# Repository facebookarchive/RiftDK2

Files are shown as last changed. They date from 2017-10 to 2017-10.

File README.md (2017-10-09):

Oculus Rift Development Kit 2
=======

Firmware, electrical CAD, mechanical CAD, artwork, and documentation for DK2.

License
-------
The CAD, artwork, and documentation are released under Creative Commons
Attribution 4.0 International.

The Oculus firmware is licensed under the BSD-style license at
https://github.com/fbsamples/RiftDK2/blob/master/Headset/Firmware/LICENSE

We also provide for the Oculus firmware an additional grant of patent rights at
https://github.com/fbsamples/RiftDK2/blob/master/Headset/Firmware/PATENTS

The firmware incorporates or references materials of third parties that are
subject to other licenses.  Please see the individual headers on each file to
determine which license applies.  For ease of reference, headers that include
the link http://www.st.com/software_license_agreement_liberty_v2 refer to the
license reproduced in en.ultimate-liberty-v2.txt.

Documentation
-------------

High-level specifications for the DK2 headset, sensor, and firmware.

Cable
-----

The cable is surprisingly one of the most complex parts of the product, and
is likely actually more advanced than the entirety of DK1.  This directory
contains schematics and high level specifications for the cable, but this
is a custom assembly that likely isn't achievable to recreate from source.

Sensor
------

The positional tracking sensor release contains electrical and mechanical
CAD.  The sensor also utilizes microcontrollers which require firmware
which was not redistributable.

Headset
-------

The headset directory contains the mainboard firmware as well as electrical
and mechanical CAD for the headset.  It also contains artwork for the
packaging.

Contributors
------------

The incredible (and incredibly small) team who made DK2:

 * Headset Electrical: Lyle Bainbridge, Ryan Brown, Matt DeVoe
 * Sensor Electrical: John Robertson
 * Headset Firmware: Nirav Patel
 * Mechanical: Julian Hammerstein, Matt Thomas, Kam Chin
 * Optical: Youngshik Yoon
 * Automation: Simon Hallam, Anusha Balan, Brant Lewis
 * Operations: Rita Chen, Licia Angino, Jack McCauley, David Dykes
 * Factory: Allen Qin, Victor Zhang, Ivan Chow, Mark Zhang
 * Misc: Palmer Luckey, Chris Dycus, Jonathan Shine
 * Artwork: Matt Ford, Jon Malkemus

RiftDK2 repository preparation: Matt Appleby, Kelly Lowenberg, John Tsai

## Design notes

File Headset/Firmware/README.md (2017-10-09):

DK2 Firmware
============

Licenses
--------

The Oculus firmware is licensed under the BSD-style license at
https://github.com/fbsamples/RiftDK2/blob/master/Headset/Firmware/LICENSE

We also provide for the Oculus firmware an additional grant of patent rights at
https://github.com/fbsamples/RiftDK2/blob/master/Headset/Firmware/PATENTS

The firmware incorporates or references materials of third parties that are
subject to other licenses.  Please see the individual headers on each file to
determine which license applies.  For ease of reference, headers that include
the link http://www.st.com/software_license_agreement_liberty_v2 refer to the
license reproduced in en.ultimate-liberty-v2.txt.

External Libraries
------------------

The ARM CMSIS library is not included, but can be downloaded from:
https://github.com/ARM-software/CMSIS/tree/master/CMSIS

The firmware was originally developed with CMSIS 3.01

This should be placed in lib/CMSIS

Building DK2 Firmware
---------------------

Building DK2 firmware currently requires IAR EWARM.  You can get a 30-day trial
here: http://supp.iar.com/Download/SW/?item=EWARM-EVAL

Programming DK2 Firmware to a Board
-----------------------------------

### Updating an already programmed board

You can update a DK2 over USB using the Oculus Configuration Utility:
https://product-guides.oculus.com/en-us/documentation/dk2/latest/tasks/ug-tray-start-firmware/

In this case, you should use the most recent DK2.bin available for your board.

* Rev 3 (GDC units): prj/REV3/Exe/DK2.bin
* Rev 3.3 (Pilot run and production units): prj/REV3_3/Exe/DK2.bin

### Programming to a blank board

For a blank board, you'll need to program it over the SWD header using an
ST-Link programmer.

In this case, you'll need the ST-Link utility and DK2Bootloader.bin

* Rev 3 (GDC units): bootloader/prj/REV3/Exe/DK2Bootloader.bin
* Rev 3.3 (Pilot run and production units):
    bootloader/prj/REV3_3/Exe/DK2Bootloader.bin

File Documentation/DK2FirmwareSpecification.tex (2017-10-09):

\documentclass[letterpaper]{article}
\usepackage{bytefield}
\usepackage{mathtools}
\usepackage{ifxetex}
\ifxetex
  \usepackage{fontspec}
  \setmainfont[ExternalLocation=../Common/, 
  					  Ligatures =TeX,
					  BoldFont = Cabin-Bold.ttf,
					  ItalicFont = Cabin-Italic.ttf,
					  BoldItalicFont = Cabin-BoldItalic.ttf ]
					  {Cabin-Regular.ttf}
\fi
\usepackage{graphicx}
\usepackage{color}
\usepackage[table]{xcolor}
\usepackage{hyperref}
\usepackage{parskip}
\usepackage{tikz}
\usetikzlibrary{automata,positioning,fit}
\usepackage{fancyhdr}
\pagestyle{fancy}
\definecolor{lightgray}{gray}{0.8}
\renewcommand{\arraystretch}{1.25}

\begin{document}

\title{\huge DK2 Firmware Specification}
\author{Nirav Patel}
\date{Revision 0.10\\
28 April 2014}

\begin{figure}

\end{figure}

\maketitle
\thispagestyle{empty}

\lfoot{DK2 Firmware Specification}
\cfoot{}
\rfoot{\thepage}

\newpage

\tableofcontents

\newpage

\section{Revision History}

\begin{center}
    \begin{tabular}{ | l | l | p{8cm} |}
    \hline
    \cellcolor{lightgray} Revision & \cellcolor{lightgray} Date & \cellcolor{lightgray} Description \\ \hline
    0.1 & 28-11-2013 & Preliminary specification. \\ \hline
    0.2 & 08-12-2013 & Add camera feature report. \\ \hline
    0.3 & 11-12-2013 & Add display feature report. \\ \hline
    0.4 & 23-12-2013 & Add magnetometer and position calibration and LED pattern reports. \\ \hline
    0.5 & 26-12-2013 & Add keep alive, manufacturing, and uuid reports. \\ \hline
    0.6 & 30-01-2014 & Add temperature report, modify position report. \\ \hline
    0.7 & 13-02-2014 & Add gyro offset report. \\ \hline
    0.8 & 18-02-2014 & Add normals to position calibration, rename camera to tracking. \\ \hline
    0.9 & 24-02-2014 & Add lens distortion report. \\ \hline
    0.10 & 28-04-2014 & Add basic EDID information. \\ \hline
    \end{tabular}
\end{center}

\newpage

\section{Introduction}

The Rift DK2 is interfaced using USB HID with a 1000 Hz polling rate.  The device is configured using Feature Report Gets and Sets and reports back gyroscope, accelerometer, magnetometer, and synchronization timestamps through an IN Report.  For more information about HID, see the Device Class Definition for Human Interface Devices\footnote{\url{http://www.usb.org/developers/devclass_docs/HID1_11.pdf}}

\begin{itemize}
  \item {\bfseries Vendor ID:} {\em 0x2833}
  \item {\bfseries Product ID:} {\em 0x0021}
  \item {\bfseries Vendor String:} {\em Oculus VR, Inc.}
  \item {\bfseries Product String:} {\em Rift DK2}
  \item {\bfseries Serial String:} {\em Globally unique 20 byte Base32 string generated per device}
\end{itemize}

\newpage

\section{HID In Report}

The 64 byte IN report on Endpoint 1 contains the sensor data.  All data is in little-endian format.  The gyro and accelerometer report data at a rate of 1000 Hz, which is also the rate at which the sample time is incremented.\\

While the target rate for the host polling the device for the IN report is 1000 Hz, system or bus load can cause the polling to happen on longer intervals, dropping the reporting rate below 1000 Hz.  For this reason, the report contains fields for up to 2 samples of gyro and accelerometer data as well as a field stating the number of samples being reported.  The behavior is as follows:\\

\begin{itemize}
  \item If the number of recorded samples is $<=$ 2, the corresponding number
   of samples is returned with NumSamples set accordingly.
  \item If the number of recorded samples is $>$ 2, the first (NumSamples -1) samples
   are averaged into Samples[0], while Samples[1] contains the most recent recorded sample.
   NumSamples is set to the total original number of
   recorded samples and Timestamp is set to that of the most recent sample; this allows for PC software to compensate the integration.
  \item DK2 does not accumulate more then 254 samples; beyond that the
   NumSamples is reset to 2 and only the most recent 2 samples are reported, with the Timestamp field properly incremented to indicate the loss of samples.
\end{itemize}

\begin{bytefield}[leftcurly=.,bitwidth=1.1em]{32}
         \bitheader{0-31} \\
	\begin{leftwordgroup}{0}
           \bitbox{8}{ReportID = 11} & \bitbox{16}{LastCommandID} & \bitbox{8}{NumSamples}
	\end{leftwordgroup} \\
	\begin{leftwordgroup}{4}
           \bitbox{16}{SampleCount} & \bitbox{16}{Temperature}
	\end{leftwordgroup} \\
	\begin{leftwordgroup}{8}
           \bitbox{32}{SampleTimestamp}
	\end{leftwordgroup} \\
	\begin{leftwordgroup}{12}
           \wordbox[lrt]{1}{Samples[0]}
	\end{leftwordgroup} \\
         \skippedwords \\
         \wordbox[lrb]{1}{} \\
	\begin{leftwordgroup}{28}
           \wordbox[lrt]{1}{Samples[1]}
	\end{leftwordgroup} \\
         \skippedwords \\
         \wordbox[lrb]{1}{} \\
	\begin{leftwordgroup}{44}
            \bitbox{16}{MagX} & \bitbox{16}{MagY}
	\end{leftwordgroup} \\
	\begin{leftwordgroup}{48}
           \bitbox{16}{MagZ} & \bitbox{16}{FrameCount}
	\end{leftwordgroup} \\
	\begin{leftwordgroup}{52}
	   \bitbox{32}{FrameTimestamp}
	\end{leftwordgroup} \\
	\begin{leftwordgroup}{56}
	   \bitbox{8}{FrameID} & \bitbox{8}{TrackingPattern} & \bitbox{16}{TrackingCount}
	\end{leftwordgroup} \\
	\begin{leftwordgroup}{60}
	   \bitbox{32}{TrackingTimestamp}
	\end{leftwordgroup} \\
\end{bytefield}

\begin{itemize}
  \item {\bfseries ReportID} (8 bits): The USB Report ID for this report is 11.
  \item {\bfseries LastCommandID} (16 bits): Contains the CommandID from the last Feature Report set on DK2.
  \item {\bfseries NumSamples} (8 bits): The number of samples the report represents as described above.
  \item {\bfseries SampleCount} (16 bits): A running counter of samples, for the number of the first sample in the report.  As the internal sampling rate targets 1000 Hz, this unit is close to milliseconds.
  \item {\bfseries Temperature} (16 bits): The most recent internal sensor temperature recorded by the DK2.  The value is in two's complement format, in units of centidegrees Celsius. 
  \item {\bfseries SampleTimestamp} (32 bits): A microsecond timestamp of the last sensor sample in the packet.  This is recorded on the same clock as the FrameTimestamp and TrackingTimestamp.
  \item {\bfseries Samples} (128 bits): Each sample contains X, Y, and Z data for the gyro and accelerometer.  Specified below.
  \item {\bfseries MagX, MagY, MagZ} (16 bits each): The most recent data available from the magnetometer.  The three axes are sampled simultaneously at up to 100 Hz.  Note that consecutive reports may contain the same magnetometer data.  The data is two's complement in units of $10\textsuperscript{-4}$ gauss.
  \item {\bfseries FrameCount} (16 bit): A running counter of frames sent to the display, incremented at each vsync.
  \item {\bfseries FrameTimestamp} (32 bit): A microsecond timestamp of the last vsync sent to the display.  This is recorded on the same clock as the SampleTimestamp and TrackingTimestamp.
  \item {\bfseries FrameID} (8 bit): The green value of the top left pixel in the last frame sent to the display.  This is used to identify specific frames to measure the end to end latency from motion to photon.
  \item {\bfseries TrackingPattern} (8 bit): The index of the last tracking LED pattern exposed to the camera.
  \item {\bfseries TrackingCount} (16 bit): A running counter of camera frames triggered by the headset.
  \item {\bfseries TrackingTimestamp} (32 bit): A microsecond timestamp of the last camera exposure.  This is recorded on the same clock as the SampleTimestamp and FrameTimestamp.
\end{itemize}

\subsection{Accelerometer and Gyro Sample}

The X, Y, and Z axes of the gyro and accelerometer are sampled simultaneously.  The accelerometer fields are two's complement format and 21 bits each. They are in units of $\frac{m}{s\textsuperscript{2}}\cdot 10\textsuperscript{-4}$.  The gyroscope fields are two's complement and 21 bits each. They are in units of $\frac{\theta}{s}\cdot 10\textsuperscript{-4}$ in radians.\\

\begin{bytefield}[leftcurly=.,bitwidth=1.1em]{32}
         \bitheader{0-31} \\
	\begin{leftwordgroup}{0}
           \bitbox{21}{AccelX} & \bitbox{11}{AccelY[0:10]} 
	\end{leftwordgroup} \\
	\begin{leftwordgroup}{4}
           \bitbox{10}{AccelY[11:20]} & \bitbox{21}{AccelZ} & \bitbox{1}{\color{lightgray}\rule{\width}{\height}}
	\end{leftwordgroup} \\
	\begin{leftwordgroup}{8}
           \bitbox{21}{GyroX} & \bitbox{11}{GyroY[0:10]} 
	\end{leftwordgroup} \\
	\begin{leftwordgroup}{12}
           \bitbox{10}{GyroY[11:20]} & \bitbox{21}{GyroZ} & \bitbox{1}{\color{lightgray}\rule{\width}{\height}}
	\end{leftwordgroup} \\
\end{bytefield}

\newpage

\section{Feature Reports}

\subsection{Tracking}

The 13 byte Tracking report has a ReportID of 12.  It configures the infrared tracking LEDs and camera synchronization. \\

\begin{bytefield}[leftcurly=.,bitwidth=1.1em]{32}
         \bitheader{0-31} \\
	\begin{leftwordgroup}{0}
           \bitbox{8}{ReportID = 12} & \bitbox{16}{CommandID} & \bitbox{8}{Pattern}
	\end{leftwordgroup} \\
	\begin{leftwordgroup}{4}
           \bitbox{1}{a} & \bitbox{1}{b} & \bitbox{1}{c} & \bitbox{1}{d} & \bitbox{1}{e} & \bitbox{1}{f} & \bitbox{10}{} & \bitbox{16}{ExposureLength}
          \end{leftwordgroup} \\
	\begin{leftwordgroup}{8}
           \bitbox{16}{FrameInterval} & \bitbox{16}{VsyncOffset}
	\end{leftwordgroup} \\
	\begin{leftwordgroup}{12}
           \bitbox{8}{DutyCycle} & \bitbox[]{24}{}
	\end{leftwordgroup} \\
\end{bytefield}

\begin{itemize}
  \item {\bfseries ReportID} (8 bits): The USB Report ID for this report is 12.
  \item {\bfseries CommandID} (16 bits): A sequence number that is then repeated in the LastCommandID field of the HID IN Report.
  \item {\bfseries Pattern} (8 bits): The index of the pattern of high and low intensities that is currently set on the tracking LEDs.  Pattern 255 is reserved for all LEDs set high.  Patterns auto-increment after each exposure if the Autoincrement bit is set in the bitmask.  The Pattern starts at 0 on power on.
  \item {\bfseries (a) Enable} (1 bit): This bit enables the tracking LED exposure and updating.  This currently defaults to on, but will default off in a later firmware revision.
  \item {\bfseries (b) Autoincrement} (1 bit): With Autoincrement set, the Pattern is incremented after every exposure.  This defaults to on.
  \item {\bfseries (c) UseCarrier} (1 bit): The tracking LEDs modulate at 85 kHz to allow for wireless synchronization when UseCarrier is enabled.  This defaults to on.
  \item {\bfseries (d) SyncInput} (1 bit): With SyncInput enabled, LED exposure is triggered from a rising edge on GPIO1.  With SyncInput disabled, the LED exposure is triggered from an internal timer at FrameInterval.  This defaults to off.
  \item {\bfseries (e) VsyncLock} (1 bit)(Disabled): If enabled, LED exposure is triggered on panel Vsync rather than from an internal timer or external trigger.  This defaults to off.
  \item {\bfseries (f) CustomPattern} (1 bit): If enabled, the LED sequence will be the one loaded in using the CustomPattern report.  This defaults to off.
  \item {\bfseries ExposureLength} (16 bits): This is the length of time the tracking LEDs are enabled for in microseconds.  The sync output also follows this length.  This number cannot be larger than the FrameInterval.  The minimum length is approximately 10 microseconds.
  \item {\bfseries FrameInterval} (16 bits): When SyncInput and VsyncLock are false, the tracking LEDs are exposed on the interval set in FrameInterval in microseconds.
  \item {\bfseries VsyncOffset} (16 bits)(Disabled): When VsyncLock is enabled, the exposure can be performed a fixed offset of VsyncOffset microseconds after the panel vsync.
  \item {\bfseries DutyCycle} (8 bits): When UseCarrier is true, the duty cycle of the 85 kHz modulation can be increased or decreased.  The default value is 128, which results in a $50\%$ duty cycle. 
\end{itemize}

\newpage

\subsection{Display}

The 16 byte Display report has a ReportID of 13.  It configures the display panel. \\

\begin{bytefield}[leftcurly=.,bitwidth=1.1em]{32}
         \bitheader{0-31} \\
	\begin{leftwordgroup}{0}
           \bitbox{8}{ReportID = 13} & \bitbox{16}{CommandID} & \bitbox{8}{Brightness}
	\end{leftwordgroup} \\
	\begin{leftwordgroup}{4}
           \bitbox{4}{a} & \bitbox{2}{b} & \bitbox{1}{c} & \bitbox{1}{d} & \bitbox{1}{e} & \bitbox{1}{f} & \bitbox{1}{g} & \bitbox{1}{h} &\bitbox{20}{}
          \end{leftwordgroup} \\
	\begin{leftwordgroup}{8}
           \bitbox{16}{Persistence} & \bitbox{16}{LightingOffset}
	\end{leftwordgroup} \\
	\begin{leftwordgroup}{12}
           \bitbox{16}{PixelSettle} & \bitbox{16}{TotalRows}
	\end{leftwordgroup} \\
\end{bytefield}

\begin{itemize}
  \item {\bfseries ReportID} (8 bits): The USB Report ID for this report is 13.
  \item {\bfseries CommandID} (16 bits): A sequence number that is then repeated in the LastCommandID field of the HID IN Report.
  \item {\bfseries Brightness} (8 bits): A relative brightness setting that is independent of pixel persistence.  The field only takes effect if HighBrightness is disabled. 
  \item {\bfseries (a) ShutterType} (4 bits)(Read only): A read-only enum of the method in which the display is scanned and exposed.
  \item {\bfseries (b) CurrentLimit} (2 bit): An enum of the current limiting mode in use.
  \item {\bfseries (c) UseRolling} (1 bit): Switches between global shutter and rolling shutter update modes.  This defaults to true.
  \item {\bfseries (d) ReverseRolling} (1 bit): Switches the polarity on the rolling shutter mode.  Reverse had the lighting of rows happen before the black period.  This defaults to true.
  \item {\bfseries (e) HighBrightness} (1 bit)(Disabled): This enables a mode in which maximum brightness is used, at the possible expense of panel lifetime.  This defaults to false.
  \item {\bfseries (f) SelfRefresh} (1 bit): This sets the panel to self refresh from the contents of its frame buffer.  This defaults to false.
  \item {\bfseries (g) ReadPixel} (1 bit): This enables reading the top left pixel each frame.  This currently defaults to false, but will default to true in a later firmware revision.
  \item {\bfseries (h) DirectPentile} (1 bit): This enables direct mapping of input data to panel sub pixel geometry, rather than using in-panel interpolation.
  \item {\bfseries Persistence} (16 bits): This is the length of time in rows that the display is lit each frame.  This defaults to the full size of the display, meaning full persistence.
  \item {\bfseries LightingOffset} (16 bits)(Disabled): This is the offset in rows from vsync that the panel is lit when using global shutter mode.  In rolling shutter, this has no effect.
  \item {\bfseries PixelSettle} (16 bits)(Read only): This is the read-only time in microseconds that we estimate the pixel takes to settle to the value it is set to after it is lit.
  \item {\bfseries TotalRows} (16 bits)(Read only): This is the read-only number of rows including active area and blanking used with Persistence and LightingOffset.
\end{itemize}

\newpage

\subsection{MagCalibration}

The 52 byte MagCalibration report has a ReportID of 14.  It contains the 3 by 4 matrix of parameters used to fit the magnetometer to a sphere.  The table is stored on the headset, but the firmware does not apply it to outgoing magnetometer data. \\

\begin{bytefield}[leftcurly=.,bitwidth=1.1em]{32}
         \bitheader{0-31} \\
	\begin{leftwordgroup}{0}
           \bitbox{8}{ReportID = 14} & \bitbox{16}{CommandID} & \bitbox{8}{Version}
	\end{leftwordgroup} \\
	\begin{leftwordgroup}{4}
           \bitbox{32}{Calibration[0][0]}
         \end{leftwordgroup} \\
	\begin{leftwordgroup}{8}
           \bitbox{32}{Calibration[0][1]}
         \end{leftwordgroup} \\
	\begin{leftwordgroup}{12}
           \bitbox{32}{Calibration[0][2]}
         \end{leftwordgroup} \\
	\begin{leftwordgroup}{16}
           \bitbox{32}{Calibration[0][3]}
         \end{leftwordgroup} \\
	\begin{leftwordgroup}{20}
           \bitbox{32}{Calibration[1][0]}
         \end{leftwordgroup} \\
	\begin{leftwordgroup}{24}
           \bitbox{32}{Calibration[1][1]}
         \end{leftwordgroup} \\
	\begin{leftwordgroup}{28}
           \bitbox{32}{Calibration[1][2]}
         \end{leftwordgroup} \\
	\begin{leftwordgroup}{32}
           \bitbox{32}{Calibration[1][3]}
         \end{leftwordgroup} \\
	\begin{leftwordgroup}{36}
           \bitbox{32}{Calibration[2][0]}
         \end{leftwordgroup} \\
	\begin{leftwordgroup}{40}
           \bitbox{32}{Calibration[2][1]}
         \end{leftwordgroup} \\
	\begin{leftwordgroup}{44}
           \bitbox{32}{Calibration[2][2]}
         \end{leftwordgroup} \\
	\begin{leftwordgroup}{48}
           \bitbox{32}{Calibration[2][3]}
         \end{leftwordgroup} \\
\end{bytefield}

\begin{itemize}
  \item {\bfseries ReportID} (8 bits): The USB Report ID for this report is 14.
  \item {\bfseries CommandID} (16 bits): A sequence number that is then repeated in the LastCommandID field of the HID IN Report.
  \item {\bfseries Version} (8 bits): The version of the calibration procedure used to generate the stored table. 
  \item {\bfseries Calibration} (48 bytes): This is the 3 by 4 matrix used to fit magnetometer data to a sphere.  Each field is a 32 bit signed integer.  The specific value is dependent on the calibration procedure, indicated by Version.
\end{itemize}

\newpage

\subsection{PositionCalibration}

The 30 byte PositionCalibration report has a ReportID of 15.  It allows reading and storage of calibrated positions of each tracking LED as well as the inertial tracker.\\

\begin{bytefield}[leftcurly=.,bitwidth=1.1em]{32}
         \bitheader{0-31} \\
	\begin{leftwordgroup}{0}
           \bitbox{8}{ReportID = 15} & \bitbox{16}{CommandID} & \bitbox{8}{Version}
	\end{leftwordgroup} \\
	\begin{leftwordgroup}{4}
           \bitbox{32}{Position[0]}
          \end{leftwordgroup} \\
	\begin{leftwordgroup}{8}
           \bitbox{32}{Position[1]}
          \end{leftwordgroup} \\
	\begin{leftwordgroup}{12}
           \bitbox{32}{Position[2]}
          \end{leftwordgroup} \\
	\begin{leftwordgroup}{16}
           \bitbox{16}{Normal[0]} && \bitbox{16}{Normal[1]}
          \end{leftwordgroup} \\
	\begin{leftwordgroup}{20}
           \bitbox{16}{Normal[2]} && \bitbox{16}{Rotation}
          \end{leftwordgroup} \\
	\begin{leftwordgroup}{24}
           \bitbox{16}{PositionIndex} & \bitbox{16}{NumPositions}
          \end{leftwordgroup} \\
	\begin{leftwordgroup}{28}
           \bitbox{16}{PositionType} & \bitbox[]{16}{}
          \end{leftwordgroup} \\
\end{bytefield}

\begin{itemize}
  \item {\bfseries ReportID} (8 bits): The USB Report ID for this report is 15.
  \item {\bfseries CommandID} (16 bits): A sequence number that is then repeated in the LastCommandID field of the HID IN Report.
  \item {\bfseries Version} (8 bits): The version of the calibration procedure used to generate the stored positions.  Note that setting the report with a Version value of 1 returns the Position values for the PositionIndex to the stored defaults.
    \begin{description}
      \item[0 -] None
      \item[1 -] Hard-coded default positions
      \item[2 -] Factory calibrated
      \item[3 -] User calibrated
    \end{description}
  \item {\bfseries Position} (12 bytes): The X, Y, and Z axis position of the LED or inertial tracker.  This is a signed integer in units of micrometers.  The position is relative to the center of the emitter plane of the display at nominal focus.
  \item {\bfseries Normal} (6 bytes): The X, Y, and Z axis normal of the LED or inertial tracker.  This is a signed integer in units of micrometers.  The Normal is relative to the Position.
  \item {\bfseries Rotation} (16 bits): The rotation around the normal.  This is in units of $ 10\textsuperscript{-4}$ radians.
  \item {\bfseries PositionIndex} (16 bits): This is the current position being read or written to.  This autoincrements on reads, and gets set to the written value on writes.
  \item {\bfseries NumPositions} (16 bits)(Read only): This is the read-only number of items with positions stored.
  \item {\bfseries PositionType} (16 bits)(Read only): The type of the item which has its position reported in the current report.  These are defined as:
    \begin{description}
      \item[0 -] Tracking LED
      \item[1 -] Inertial sensor
    \end{description}
    When setting this report, the PositionType should match that read for the PositionIndex.
\end{itemize}

\newpage

\subsection{CustomPattern}

The 12 byte CustomPattern report has a ReportID of 16.  It allows reading of the default LED patterns as well as reading and setting of custom patterns.  Repeated reads of the report iterate through each LED, starting at 0 and wrapping at the final LED.  When the CustomPattern bit of the Tracking report is not set, reads on this report act upon the default LED pattern stored in the headset, and writes have no effect.  With the CustomPattern bit set, this report acts on a custom pattern array that erases when the headset is reset.\\

\begin{bytefield}[leftcurly=.,bitwidth=1.1em]{32}
         \bitheader{0-31} \\
	\begin{leftwordgroup}{0}
           \bitbox{8}{ReportID = 16} & \bitbox{16}{CommandID} & \bitbox{8}{SequenceLength}
	\end{leftwordgroup} \\
	\begin{leftwordgroup}{4}
           \bitbox{32}{Sequence}
          \end{leftwordgroup} \\
	\begin{leftwordgroup}{8}
           \bitbox{16}{LEDIndex} & \bitbox{16}{NumLEDs}
	\end{leftwordgroup} \\
\end{bytefield}

\begin{itemize}
  \item {\bfseries ReportID} (8 bits): The USB Report ID for this report is 16.
  \item {\bfseries CommandID} (16 bits): A sequence number that is then repeated in the LastCommandID field of the HID IN Report.
  \item {\bfseries SequenceLength} (8 bits): The length of the sequence of bits that each LED goes through.  Each state of the sequence is represented by two bits, allowing a maximum of 4 levels per sequence.  For DK2, only states 0, 1, and 3 are meaningful, for off, low, and high respectively.
  \item {\bfseries Sequence} (32 bits): The sequence that the specific LED goes through.  The first $SequenceLength*2$ bits are used.  The sequence is in order of LSB to MSB.
  \item {\bfseries LEDIndex} (16 bits): This is the current LED being read or written to.  This autoincrements on reads, and gets set to the written value on writes.
  \item {\bfseries NumLEDs} (16 bits)(Read only): This is the read-only number of tracking LEDs which are actually present on the device.
\end{itemize}

\newpage

\subsection{KeepAliveMux}

The 6 byte KeepAliveMux report has a ReportID of 17.  It is used to specify both which IN Report is sent and the interval of sending.  The interval takes effect only if the UseCommandKeepAlive or UseMotionKeepAlive bits are set in the Config report.\\

\begin{bytefield}[leftcurly=.,bitwidth=1.1em]{32}
         \bitheader{0-31} \\
	\begin{leftwordgroup}{0}
           \bitbox{8}{ReportID = 17} & \bitbox{16}{CommandID} & \bitbox{8}{INReport}
	\end{leftwordgroup} \\
	\begin{leftwordgroup}{4}
           \bitbox{16}{Interval} & \bitbox[]{16}{}
          \end{leftwordgroup} \\
\end{bytefield}

\begin{itemize}
  \item {\bfseries ReportID} (8 bits): The USB Report ID for this report is 17.
  \item {\bfseries CommandID} (16 bits): A sequence number that is then repeated in the LastCommandID field of the HID IN Report.
  \item {\bfseries INReport} (8 bits): The specified number is the INReport which will be repeatedly sent until the interval is passed.  For example, specifying 1 sends the DK1 IN Report, while specifying 11 sends the DK2 IN Report.  The default value for DK2 is 11.
  \item {\bfseries Interval} (16 bits): The interval in milliseconds used as the threshold for UseCommandKeepAlive and UseMotionKeepAlive.  The default interval is 10000.
\end{itemize}

\newpage

\subsection{Manufacturing}

The 16 byte Manufacturing report has a ReportID of 18.  It is used to record and display the results of each stage of the production of the DK2 product that has USB access.\\

\begin{bytefield}[leftcurly=.,bitwidth=1.1em]{32}
         \bitheader{0-31} \\
	\begin{leftwordgroup}{0}
           \bitbox{8}{ReportID = 18} & \bitbox{16}{CommandID} & \bitbox{8}{NumStages}
	\end{leftwordgroup} \\
	\begin{leftwordgroup}{4}
           \bitbox{8}{Stage} & \bitbox{8}{StageVersion} & \bitbox{16}{StageLocation}
         \end{leftwordgroup} \\
	\begin{leftwordgroup}{8}
           \bitbox{32}{StageTime}
         \end{leftwordgroup} \\
	\begin{leftwordgroup}{12}
           \bitbox{32}{Result}
         \end{leftwordgroup} \\
\end{bytefield}

\begin{itemize}
  \item {\bfseries ReportID} (8 bits): The USB Report ID for this report is 18.
  \item {\bfseries CommandID} (16 bits): A sequence number that is then repeated in the LastCommandID field of the HID IN Report.
  \item {\bfseries NumStages} (8 bits)(Read only): The number of stages of production being recorded on the product.
  \item {\bfseries Stage} (8 bits): The specific stage number being recorded or read from.  This autoincrements on reads, and gets set to the written value on writes.
  \item {\bfseries StageVersion} (8 bits): The version of the specific manufacturing test.
  \item {\bfseries StageLocation} (16 bits): A bit mask representing the manufacturer, line, and machine this test was performed on.  See the DK2 Testware document for details on this.
  \item {\bfseries StageTime} (32 bits): The UNIX time at which the stage was performed.
  \item {\bfseries Result} (32 bits): The result of the stage.  See the DK2 Testware document for the details of what this means for each stage.
\end{itemize}

\newpage

\subsection{UUID}

The 23 byte UUID report has a ReportID of 19.  It is used internally for manufacturing purposes, when the USB serial number is set to a default number.  Outside of manufacturing, the number is identical to the USB serial number.  Setting this report switches the USB serial number to the value read from this report.  The value being set is ignored.\\

\begin{bytefield}[leftcurly=.,bitwidth=1.1em]{32}
         \bitheader{0-31} \\
	\begin{leftwordgroup}{0}
           \bitbox{8}{ReportID = 19} & \bitbox{16}{CommandID} & \bitbox{8}{UUID[0]} 
	\end{leftwordgroup} \\
	\begin{leftwordgroup}{4}
           \bitbox{32}{UUID[1:5]}
	\end{leftwordgroup} \\
	\begin{leftwordgroup}{8}
           \bitbox{32}{UUID[5:9]}
	\end{leftwordgroup} \\
	\begin{leftwordgroup}{12}
           \bitbox{32}{UUID[9:13]}
	\end{leftwordgroup} \\
	\begin{leftwordgroup}{16}
           \bitbox{32}{UUID[13:17]}
	\end{leftwordgroup} \\
	\begin{leftwordgroup}{20}
           \bitbox{24}{UUID[17:20]} & \bitbox[]{8}{}
	\end{leftwordgroup} \\
\end{bytefield}

\begin{itemize}
  \item {\bfseries ReportID} (8 bits): The USB Report ID for this report is 19.
  \item {\bfseries CommandID} (16 bits): A sequence number that is then repeated in the LastCommandID field of the HID IN Report.
  \item {\bfseries UUID} (20 bytes)(Read only):  The unique ID of the device.
\end{itemize}

\newpage

\subsection{Temperature}

The 24 byte Temperature report has a ReportID of 20.  It is used to store gyroscope zero rate offsets across different temperatures.  The offsets are stored for certain target temperature Bins, with multiple Samples of offset data stored per temperature.  When reading the report, subsequent reads of the report go sequentially through each Sample in NumSamples for each Bin in NumBins.  The headset only stores the offsets, and does not create or modify them directly.\\

\begin{bytefield}[leftcurly=.,bitwidth=1.1em]{32}
         \bitheader{0-31} \\
	\begin{leftwordgroup}{0}
           \bitbox{8}{ReportID = 20} & \bitbox{16}{CommandID} & \bitbox{8}{Version} 
	\end{leftwordgroup} \\
	\begin{leftwordgroup}{4}
           \bitbox{8}{NumBins} & \bitbox{8}{Bin} & \bitbox{8}{NumSamples} & \bitbox{8}{Sample}
	\end{leftwordgroup} \\
	\begin{leftwordgroup}{8}
           \bitbox{16}{TargetTemperature} & \bitbox{16}{ActualTemperature}
	\end{leftwordgroup} \\
	\begin{leftwordgroup}{12}
           \bitbox{32}{Time}
	\end{leftwordgroup} \\
	\begin{leftwordgroup}{16}
           \wordbox[lrt]{1}{Offset}
	\end{leftwordgroup} \\
         \skippedwords \\
         \wordbox[lrb]{1}{} \\
\end{bytefield}

\begin{itemize}
  \item {\bfseries ReportID} (8 bits): The USB Report ID for this report is 20.
  \item {\bfseries CommandID} (16 bits): A sequence number that is then repeated in the LastCommandID field of the HID IN Report.
  \item {\bfseries Version} (8 bits):  The version of temperature calibration being performed.
  \item {\bfseries NumBins} (8 bits)(Read only): The number of temperature bins being stored.
  \item {\bfseries Bin} (8 bits): The current index of temperature bin the samples are for.  This autoincrements on reading all of the Samples in the Bin, and gets set to the written value on writes.
  \item {\bfseries NumSamples} (8 bits)(Read only): The number of samples being stored per temperature bin.
  \item {\bfseries Sample} (8 bits): The current index of temperature offset sample.  This autoincrements on reads, and gets set to the written value on writes.
  \item {\bfseries TargetTemperature} (16 bits)(Read only): The target temperature in centidegrees Celsius for the current Level.
  \item {\bfseries ActualTemperature} (16 bits): The actual temperature in centidegrees Celsius of the current Bin.
  \item {\bfseries Time} (32 bits): The UNIX time that the current Sample was generated at.
  \item {\bfseries Offset} (64 bits): The packed sample format with 21 bits per axis used for the IN Report, with each value in units of $\frac{\theta}{s}\cdot 10\textsuperscript{-4}$ radians, representing the estimated zero-rate gyroscope offset for the ActualTemperature.
\end{itemize}

\newpage

\subsection{GyroOffset}

The 18 byte Temperature report has a ReportID of 21.  It is used to fetch the headset's most recent estimate of gyro zero-rate offset error.  Note that if the headset fails to complete zero rate offset calculation, there will not be valid data in this report, indicated by a Version field value of 0.\\

\begin{bytefield}[leftcurly=.,bitwidth=1.1em]{32}
         \bitheader{0-31} \\
	\begin{leftwordgroup}{0}
           \bitbox{8}{ReportID = 21} & \bitbox{16}{CommandID} & \bitbox{8}{Version} 
	\end{leftwordgroup} \\
	\begin{leftwordgroup}{4}
           \wordbox[lrt]{1}{Offset}
	\end{leftwordgroup} \\
         \skippedwords \\
         \wordbox[lrb]{1}{} \\
	\begin{leftwordgroup}{12}
           \bitbox{32}{Timestamp}
        	\end{leftwordgroup} \\
	\begin{leftwordgroup}{16}
           \bitbox{16}{Temperature} & \bitbox[]{16}{}
	\end{leftwordgroup} \\
\end{bytefield}

\begin{itemize}
  \item {\bfseries ReportID} (8 bits): The USB Report ID for this report is 21.
  \item {\bfseries CommandID} (16 bits): A sequence number that is then repeated in the LastCommandID field of the HID IN Report.
  \item {\bfseries Version} (8 bits):  The version of offset calculation being performed.
    \begin{description}
      \item[0 -] No offset calculated
      \item[1 -] Running average terminated by motion
      \item[2 -] Running average terminated by timeout
    \end{description}
  \item {\bfseries Offset} (64 bits): The packed sample format with 21 bits per axis used for the IN Report, with each value in units of $\frac{\theta}{s}\cdot 10\textsuperscript{-4}$ radians, representing the estimated zero-rate gyroscope offset.
  \item {\bfseries Timestamp} (32 bits): A microsecond timestamp of the calculation of the offset.  This is recorded on the same clock as the SampleTimestamp in the IN Report.
  \item {\bfseries Temperature} (16 bits): The temperature the offset was calculated at.
\end{itemize}

\newpage

\subsection{LensDistortion}

The 64 byte LensDistortion report has a ReportID of 22.  It defines parameters used by LibOVR to correct lens distortion.  Multiple reports of the same or different versions or eye reliefs may be available, defined by NumDistortions.  The report defaults to factory data, but each DistortionIndex may be overwritten with new data.\\

\begin{bytefield}[leftcurly=.,bitwidth=1.1em]{32}
         \bitheader{0-31} \\
	\begin{leftwordgroup}{0}
           \bitbox{8}{ReportID = 22} & \bitbox{16}{CommandID} & \bitbox{8}{NumDistortions} 
	\end{leftwordgroup} \\
	\begin{leftwordgroup}{4}
           \bitbox{8}{DistortionIndex} & \bitbox{8}{Bitmask} & \bitbox{16}{LensType}
	\end{leftwordgroup} \\
	\begin{leftwordgroup}{8}
           \bitbox{16}{Version} & \bitbox{16}{EyeRelief}
	\end{leftwordgroup} \\
	\begin{leftwordgroup}{12}
           \bitbox{16}{KCoefficients[0]} & \bitbox{16}{KCoefficients[1]}
	\end{leftwordgroup} \\
	\begin{leftwordgroup}{16}
           \bitbox{16}{KCoefficients[2]} & \bitbox{16}{KCoefficients[3]}
	\end{leftwordgroup} \\
	\begin{leftwordgroup}{20}
           \bitbox{16}{KCoefficients[4]} & \bitbox{16}{KCoefficients[5]}
	\end{leftwordgroup} \\
	\begin{leftwordgroup}{24}
           \bitbox{16}{KCoefficients[6]} & \bitbox{16}{KCoefficients[7]}
	\end{leftwordgroup} \\
	\begin{leftwordgroup}{28}
           \bitbox{16}{KCoefficients[8]} & \bitbox{16}{KCoefficients[9]}
	\end{leftwordgroup} \\
	\begin{leftwordgroup}{32}
           \bitbox{16}{KCoefficients[10]} & \bitbox{16}{MaxR}
	\end{leftwordgroup} \\
	\begin{leftwordgroup}{36}
           \bitbox{16}{MetersPerTanAngleAtCenter} & \bitbox{16}{ChromaticAberration[0]}
	\end{leftwordgroup} \\
	\begin{leftwordgroup}{40}
           \bitbox{16}{ChromaticAberration[1]} & \bitbox{16}{ChromaticAberration[2]}
	\end{leftwordgroup} \\
	\begin{leftwordgroup}{44}
           \bitbox{16}{ChromaticAberration[3]} & \bitbox[lrt]{16}{}
	\end{leftwordgroup} \\
	\begin{leftwordgroup}{48}
           \wordbox[lr]{1}{Unused}
	\end{leftwordgroup} \\
         \skippedwords \\
         \wordbox[lrb]{1}{} \\
\end{bytefield}

\begin{itemize}
  \item {\bfseries ReportID} (8 bits): The USB Report ID for this report is 22.
  \item {\bfseries CommandID} (16 bits): A sequence number that is then repeated in the LastCommandID field of the HID IN Report.
  \item {\bfseries NumDistortions} (8 bits)(Read only):  The number of lens distortions being stored.
  \item {\bfseries DistortionsIndex} (8 bits):  The current index of lens distortion.  This autoincrements on reads and gets set to the written value on writes.
  \item {\bfseries Bitmask} (8 bits):  A current unused bitmask.
  \item {\bfseries LensType} (16 bits):  The type of the lens used in the headset.  These are enumerated in LibOVR.
  \item {\bfseries Version} (16 bits):  The version of lens distortion specified in the report.  The fields after this one are dependent on the specified Version.
    \begin{description}
      \item[0 -] No lens distortion stored. The remaining report is empty.
      \item[1 -] LCSV\_CatmullRom10Version1. The fields are defined as below.
    \end{description}
  \item {\bfseries EyeRelief} (16 bits):  The eye relief the distortion is designed for.  This is in units of micrometers measured from the front surface of the lens.
  \item {\bfseries KCoefficients} (11 fields of 16 bits): Catmull-Rom distortion coefficients.  The units are defined in LibOVR.
  \item {\bfseries MaxR} (16 bits): Defined in LibOVR.
  \item {\bfseries MetersPerTanAngleAtCenter} (16 bits): Defined in LibOVR.
  \item {\bfseries ChromaticAberration} (4 fields of 16 bits): Defined in LibOVR.
  \item {\bfseries Unused} (14 bytes): Unused by LCSV\_CatmullRom10Version1.
\end{itemize}

\newpage

\section{EDID}

The EDID 1.3 is read over the HDMI interface by the video host.

\begin{itemize}
  \item {\bfseries Manufacturer ID:} {\em OVR}
  \item {\bfseries Product ID:} {\em 0x0003}
  \item {\bfseries Product String:} {\em Rift DK2}
  \item {\bfseries Serial String:} {\em First 13 bytes of the device UUID}
\end{itemize}

\end{document}

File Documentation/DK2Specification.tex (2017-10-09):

\documentclass[letterpaper]{article}
\usepackage[utf8]{inputenc}

\usepackage{ifxetex}
\ifxetex
  \usepackage{fontspec}
  \setmainfont[ExternalLocation=../Common/, 
              		  Ligatures =TeX,
					  BoldFont = Cabin-Bold.ttf,
					  ItalicFont = Cabin-Italic.ttf,
					  BoldItalicFont = Cabin-BoldItalic.ttf ]
					  {Cabin-Regular.ttf}
\fi

\title{\huge DK2 Specification}
\author{Nirav Patel\\ Nate Mitchell\\ Kam Chin\\ Ryan Brown}
\date{Revision 0.4\\
30 May 2014}

\usepackage{parskip}
\usepackage{graphicx}
\usepackage{hyperref}
\usepackage{color}
\usepackage{fancybox}
\usepackage[usenames,dvipsnames,svgnames,table]{xcolor}
\usepackage{fancyhdr}
\usepackage{todo}
\usepackage{mdwlist}
\usepackage{float}
\pagestyle{fancy}
\definecolor{lightgray}{gray}{0.8}
\renewcommand{\arraystretch}{1.25}

\begin{document}

\begin{figure}
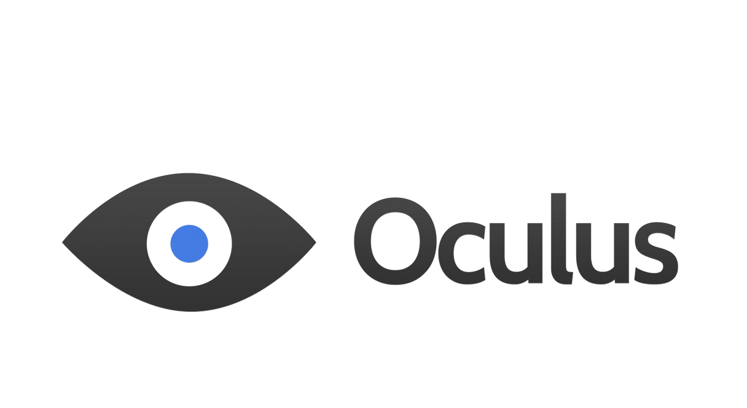
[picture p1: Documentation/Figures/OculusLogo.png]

\end{figure}

\maketitle
\thispagestyle{empty}

\lfoot{DK2 Specification 0.4}
\cfoot{}
\rfoot{\thepage}

\newpage

\tableofcontents

\newpage

\section{Revision History}

\begin{center}
    \begin{tabular}{ | l | l | p{8cm} |}
    \hline
    \cellcolor{lightgray} Revision & \cellcolor{lightgray} Date & \cellcolor{lightgray} Description \\ \hline
    0.1 & 18-9-2013 & Preliminary specification. \\ \hline
    0.2 & 3-10-2013 & Modifications from specification review. \\ \hline
    0.3 & 5-22-2014 & Updated to current design. \\ \hline
    0.4 & 5-30-2014 & Updates to cable and optics. \\ \hline
    \end{tabular}
\end{center}

\newpage

\section{Introduction}
The Oculus Rift is a virtual reality headset designed for immersive gaming. Development Kit 2 (DK2) is the second iteration of the development kit that game developers use to build games and applications for the consumer version of the Rift. \\

DK2 introduces a number of new features over DK1, including:

\begin{itemize}
    \item Higher image quality via a 1080x1920 pixel resolution AMOLED display
    \item Positional head tracking via an external Positional Tracker and headset IR LEDs    
    \item Extensibility via a user accessible USB port
\end{itemize}

\newpage

\section{Box Contents}
The Oculus Rift Development Kit 2 includes the following:

\begin{itemize}
    \item Headset with detachable cable
    \item Lenses - 2 sizes and cleaning cloth
    \item Positional Tracker
    \item Positional Tracker USB cable
    \item Positional Tracker sync cable
    \item 1 DVI to HDMI adapter
    \item Power adapter and 4 plugs: US (attached), UK, AU, EU
\end{itemize}

\newpage

\section{Primary Vendors}

\begin{itemize}
    \item Vishay
    \item STMicroelectronics
    \item Toshiba
    \item Richtek
    \item InvenSense
    \item Samsung Display
    \item Berway
    \item Jabil
    \item Elka
    \item Cypress
    \item Coxon
    \item Aptina
    \item Etron
    \item Boowon
\end{itemize}

\newpage

\section{Industrial and Mechanical Design}
DK2 is designed to be comfortable, lightweight, and durable for Virtual Reality game and content developers.  The industrial design is comprised of three distinct sections: the physical plastic panel, optics, and electronics housing, the foam and rubber facial interface, and mounting straps.  The total weight of the unit is 440 grams.

\subsection{Housing}
The DK2 headset shell is outer front cover and designed for IR transmissive cover for position tracking LEDs. This shell shape is unique industrial design and consists cable door, power button, power light pipe, Aux/USB light pipe and rubber plug. It also cover for HMD controller board. The shell interconnects with DK2 cable and Facial Interface. It has a dedicated location for product label behind both connectors. The shell has a nose recess allowing for nose clearance when the shell is assembled to other optical mounting base.

\begin{center}
    \begin{tabular}{ | l | p{8cm} |}
    \hline
    \cellcolor{lightgray} Parameter & \cellcolor{lightgray} Specification \\ \hline
    Housing & Black plastic injection molded ABS IR Transmissive \\ \hline
    Weight & 97.5 grams \\ \hline
    Finish & Matte (Sandblasted Tool) \\ \hline
    \end{tabular}
\end{center}

\begin{figure}[H]  
  \centering
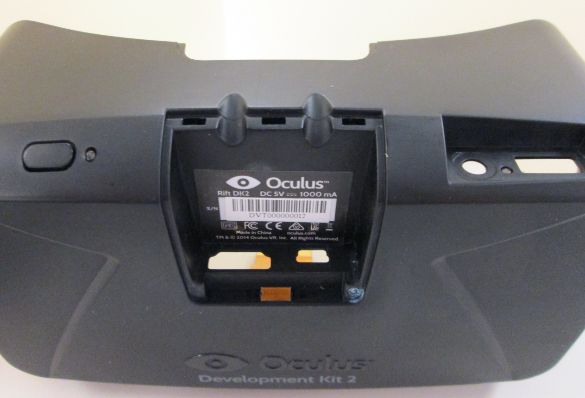
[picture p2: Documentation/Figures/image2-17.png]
    
\end{figure}

\subsection{Internal Structure}
The DK2 Mounting Base is inner part of the HMD unit where optics and panel are mounted together. Two eyecups are mounted into the Mounting Base from user viewing side and panel with rubber cushion is mounted on the other side of the Base with Frame. 
The mounting base design is highly leveraged from DK1. The Base is an interface part for Front Cover Shell and Facial Interface. The Base has a nose recess and maximized for nose clearance and optical viewing.

\begin{center}
    \begin{tabular}{ | l | p{8cm} |}
    \hline
    \cellcolor{lightgray} Parameter & \cellcolor{lightgray} Specification \\ \hline
    Housing & Black plastic injection molded ABS \\ \hline
    Weight & 176.5 grams \\ \hline
    Finish & Matte (light textured tool) \\ \hline
    \end{tabular}
\end{center}

\begin{figure}[H]  
  \centering
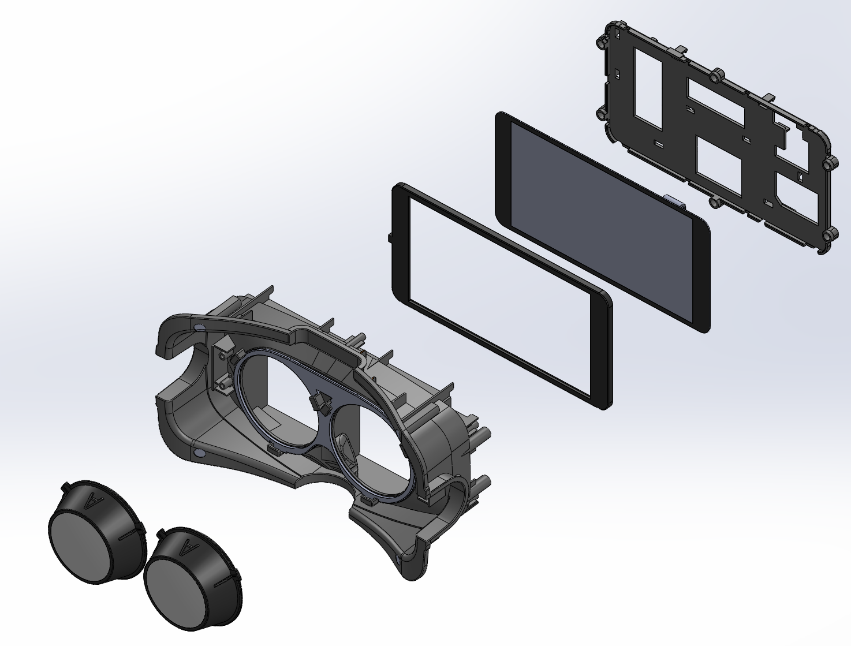
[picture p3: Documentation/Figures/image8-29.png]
    
\end{figure}

\subsection{Eye Relief Adjustment}

To allow for a wide variety of face shapes, the entire housing assembly containing the panel and optics can be adjusted closer and farther from the user's face using a coin on the mechanisms on the left and right sides of the headset.

\subsection{Facial Interface and Straps}
The facial interface of DK2 attaches to the housing using a multi-clip system. The primary components are a curved rubber mask, mesh ventilation openings, and a strip of microfiber covered triple-layer die cut foam attached to the mask with a layer of adhesive. The facial interface is very similar in design to that of ski goggles, with many of the same objectives: long term comfort, sweat resistance, and durability. \\

The DK2 Straps and Facial Interface design are carried over from DK1. Top strap design is highly leverage from DK1 and with two additional elastic cable loops. One loop is located in the front of the strap and 6 to 9 mm away from hard plastic loop. And, another loop is located in the back of the strap where T-shaped clip located and in vertical orientation. The Loop is able to stretch for connector insertion and holding cable in place. Right side of the adjustable strap loop is the same as left side loop unlike DK1 right side loop with cable clip feature.
Facial Interface?s plastic part bridge portion is trimmed off where nose clearance is located from DK1 design.

\begin{center}
    \begin{tabular}{ | l | p{8cm} |}
    \hline
    \cellcolor{lightgray} Parameter & \cellcolor{lightgray} Specification \\ \hline
    Weight & 138 grams \\ \hline
    Facial interface & Single layer die-cut foam strip, flexible PPU mounting \\ \hline
    Facial interface foam dimensions & Approximate 14mm thick, 19mm wide \\ \hline
    Straps & Two nylon/elastic fabric straps attached to the left and right sides of the headset. Top Strap has Velcro for ease of adjustment \\ \hline
    Strap Dimensions & Top strap: 3.5 mm thick, 30 mm wide, 420 mm length (approximate).
Side strap: 2.6 mm thick, 39.5 mm wide, 220 mm length (approximate) \\ \hline
    \end{tabular}
\end{center}

\begin{figure}[H]  
  \centering
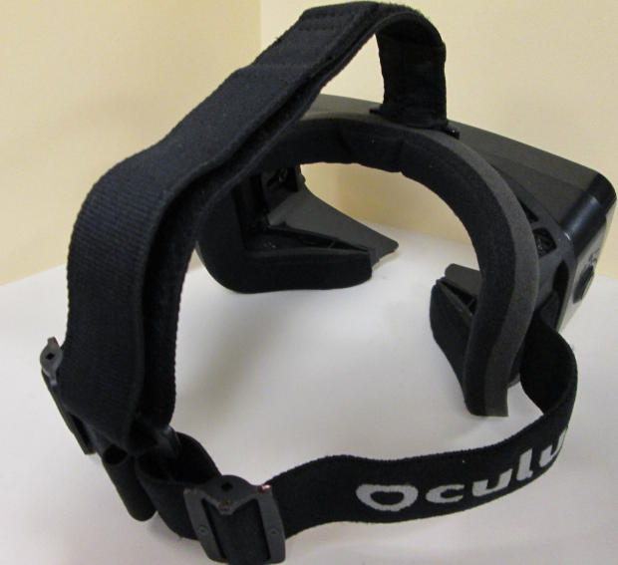
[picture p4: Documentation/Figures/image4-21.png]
    
\end{figure}

\subsection{Tracking LEDs}
DK2 includes 40 Vishay VSMY3850 850nm IR LEDs for positional tracking. These LEDs are reflow soldered onto an FPC which is attached to the inside of the front plate of the headset using 3M VHB double sided tape. They are spaced approximately 30mm apart in a design defined by computer vision algorithms.

\newpage

\subsection{Interface Control}
The Rift has a momentary tactile switch used for powering on and off.

\subsection{Status Indicator}
A bi-color amber/blue status LED on the Rift shows indication of power on as well as notification of errors.  The LED is located next to the power button.  Amber indicates that the headset is powered but not receiving video input.  Blue indicates that the headset is powered and receiving video input.

\subsection{USB Port}
A user accessible USB port is available on the top surface of the Rift.  A 2.5mm synchronization jack is placed next to the USB port to allow for synchronization of the .  The USB port is enabled and providing up to 500 mA only when the optional wall wart power is plugged in to the DK2 Cable.

\newpage

\section{Optics}
The design of the viewing optics is to cover human visual field based on biological and psychological researches. Having a single lens approach for cost effectiveness, the design is optimized not only in optics but also in image processing. There are two sets of magnifiers, labeled A and B, for the user's eye sight or preference. Each magnifier is placed at 10mm in front of each eye, situated with their centers 63.5mm (as an average inter-pupillary distance) apart. The A eyecup is mounted for normal 20/20 eye vision and B eyecup is for near-sighted users.

\begin{center}
    \begin{tabular}{ | l | p{8cm} |}
    \hline
    \cellcolor{lightgray} Parameter & \cellcolor{lightgray} Specification \\ \hline
    Lens Material & Molded optical-grade polycarbonate \\ \hline
    Lens Thickness & 5.36mm thick at the edge and 15mm at the center. \\ \hline
    Lens Type & Aspherical \\ \hline
    \end{tabular}
\end{center}

\begin{figure}[H]  
  \centering
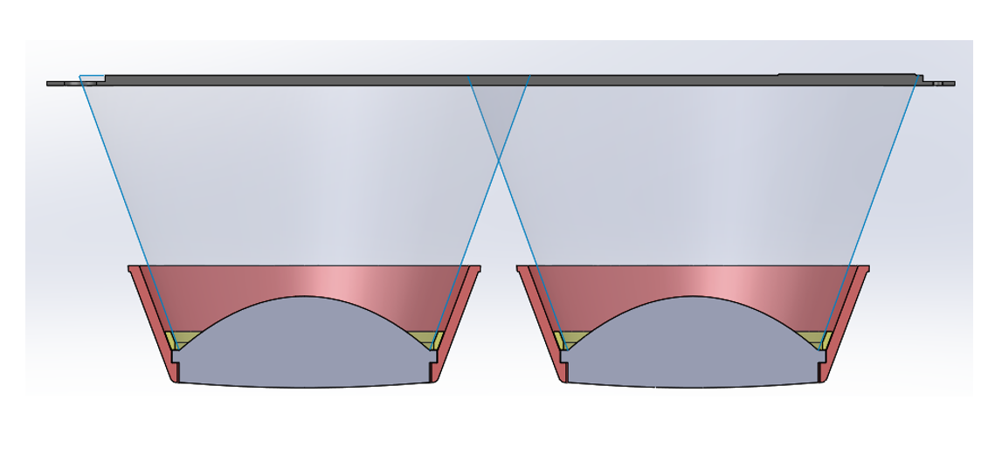
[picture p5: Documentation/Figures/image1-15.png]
    
\end{figure}

\begin{figure}[H]  
  \centering
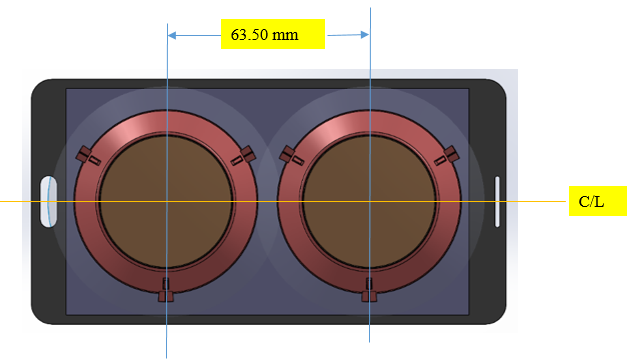
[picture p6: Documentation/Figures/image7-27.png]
    
\end{figure}

\subsection{Focus Adjustment}
To accommodate near-sighted users, an additional pair of lens cups labelled B are included with the DK2 with a 2.5mm shorter focal length.  The default lens cups installed in the headset are labelled A.  \\ 

\newpage

\section{Display}
DK2 uses a 5.68" Full HD AMOLED panel developed by Samsung Display. It is a portrait mode driven display viewed in landscape orientation, with each eye viewing half of the active screen area for a per-eye resolution of 960x1080.

\subsection{Panel}
The Samsung Display AMS568 is an RGBG pentile AMOLED panel measuring 5.68" diagonally with a 16:9 aspect ratio and a total resolution of 1080x1920. The viewable area dimensions are 70.74mm x 125.76mm.  The panel stackup from bottom to top is a foam layer, the LTPS layer, encapsulation, a polarizer, optical adhesive, a touch screen, and cover glass.  The touch screen layer is not powered or interfaced in the DK2 headset.  The module weight is 36.4 grams.

\subsection{Display Driver}
The display driver on the panel is the Samsung S6E3FA0, which supports 4 lane MIPI-DSI at up to 1.1 Gbps per lane.

\subsection{Brightness Control}
Analog voltage rails for the panel are supplied by a the TI TPS65633 triple output power supply.  The ELVSS rail can be controlled by the panel to adjust brightness.  Brightness control is made available via the Oculus SDK.  A HID Control report sets the the desired level to the microcontroller on the Rift, which then writes the request via i\textsuperscript{2}c to the display controller, which sends the MIPI DCS command to the panel to adjust the ELVSS level.  The default brightness of the headset is approximately 100 nit.

\subsection{Low Persistence Mode}
Although the effectively instant pixel switch times on an AMOLED reduce motion blur relative to LCDs, a perceptual artifact results in a specific type of motion blur called judder remaining.  Michael Abrash's blog posts offer thorough explanations of the perception of and challenges around judder.

\begin{itemize}
  \item \url{http://blogs.valvesoftware.com/abrash/why-virtual-isnt-real-to-your-brain-judder/}
  \item \url{http://blogs.valvesoftware.com/abrash/down-the-vr-rabbit-hole-fixing-judder/}
\end{itemize}

The summary is that during smooth pursuit by the eye of an object moving across space or during the vestibulo-ocular reflex (VOR) in which the eye tracks a stationary object in space smoothly as the head rotates, the object appearing on the display remains stationary for a full frame length of 16.6ms while the eye continues to rotate to track the expected path of its motion.  The effect is that the object perceptually is smearing across the retina as the eye continues to turn while the image remains stationary.  This can be most easily observed by attempting to read text fixed in the virtual environment as the head turns.  The text appears blurry as the eye attempts to track it.

The significance of the effect is proportional to the angular velocity of the head or moving object and the length of time that the object persists on the display.  The solution to the problem is therefore to reduce the length of time that the object persists on the display.

DK2 accomplishes this using a feature of the AMS568 panel called AID, which allows for rows to be enabled in a rolling manner on a reduced duty cycle.  The default duty cycle for the DK2 headset is 22.5\%.  The duty cycle is adjustable through a HID report write using the Oculus SDK.

\newpage

\section{Positional Tracker}
The Positional Tracker uses an Aptina MT9V034 sensor and an Etron eSP570 USB controller.  A user removable band pass filter on the outside of the lens stack allows for high efficiency infrared tracking as well as visible light use.  The Positional Tracker is interfaced to the host PC via a USB Mini jack as well as to the DK2 Cable via a 2.5mm synchronization jack.  See the DK2 Positional Tracker Specification for details on the positional tracking system.

\newpage

\section{Mainboard}
The mainboard of DK2 contains the video interface circuitry, the Tracker, the LED driving circuitry, and a USB hub.  See the DK2 Mainboard Specification for implementation.

\begin{figure}[H]  
  \centering
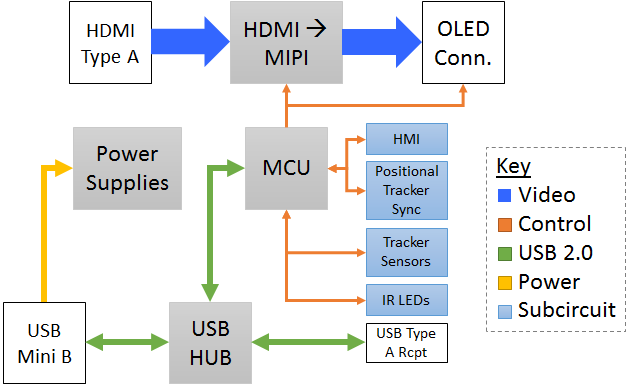
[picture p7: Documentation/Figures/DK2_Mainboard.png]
    
  \caption{Rift DK 2 Mainboard Diagram}
  \label{Mainboard_Diagram}
\end{figure}

The mainboard uses a 6 layer FR4 PCB to accommodate high speed impedance matched differential pairs.

\subsection{Power}
The DK2 power system generates all required voltages from the 5V input, optimized for minimal coversion loss.  The following rails are used:

\begin{itemize}
    \item 3.3V, 1.2V from a buck regulator
    \item 3.0V from an LDO from 3.3V
    \item 2.0V from a buck regulator
    \item 4.6V, 7.0V, -4.4V from a TPS65633
\end{itemize}

The total power consumption is under 500 mA to allow the product to be bus powered.

\subsection{HDMI MIPI Bridge}
To interface the HDMI input signal to the MIPI-DSI panel, a Toshiba TC358779 HDMI MIPI Bridge is used.  The TC358799 is a 64 ball BGA package.  It takes HDMI input at an up to 165 MHz pixel clock, optionally upscales and color adjusts it, and outputs it over a four lane MIPI-DSI interface.  The device is configured by the microcontroller over i\textsuperscript{2}c.\\

The TC358799 natively supports HDCP.  DK2 uses HDCP keys provided by Toshiba.

\begin{center}
\fcolorbox{black}{lightgray}{\parbox{\textwidth}{\textbf{Note}\\The TC358799 does not support video rotation or superposition of an on-screen display (OSD).}}
\end{center}

\subsubsection{EDID}
The HDMI DDC lines interface to a dedicated EDID EEPROM.  The EEPROM is programmed at the factory and can also be updated via the microcontroller.  The EDID contains the following display modes:

\begin{itemize*}
    \item 1080x1920 75 Hz (default)
    \item 1080x1920 60 Hz
    \item 1080x1920 72 Hz 
\end{itemize*}

The Product ID in the EDID is 0x04.  The display serial number presented in the EDID matches that of the microcontroller on the USB interface.

\subsection{USB Hub}
The mainboard contains a Cypress CY7C65634-28LTXC \footnote{\url{http://www.cypress.com/?mpn=CY7C65634-28LTXC}} 2-port USB hub.  One port interfaces to the Tracker microcontroller, while the other is connected to a USB Type A port exposed on the headset for use by the user.\\

A USB overcurrent detection and control IC interfaced to the hub powers the user USB port to ensure that overcurrent devices are disconnected.\\

When DK2 is bus powered, the user USB port is disabled.  With DK2 self powered by a wall wart, the port advertises 500 mA capability.  The hub is configured using the microcontroller to set and change this information.

\newpage

\section{Microcontroller and Sensors}
The DK2 microcontroller is a USB 2.0 FS HID device which reports inertial sensor information to the host PC, as well as allowing for driver free control of various Rift functions.  The microcontroller system is a component of the Mainboard.

\subsection{Microcontroller}
An STMicroelectronics STM32L100R8T6\footnote{\url{http://www.st.com/web/catalog/mmc/FM141/SC1169/SS1295/LN1808/PF255678}} Cortex-M3 microcontroller handles the USB interface, interfacing to the various sensors on the main board, configuring the HDMI MIPI bridge, and configuring the tracking LEDs.  Dual-stage firmware allows for the application firmware to be updated by a bootloader over USB HID.

\subsection{Gyroscope and Accelerometer}
An Invensense MPU-6500\footnote{\url{http://www.invensense.com/mems/gyro/mpu6500.html}} 3-axis gyroscope and accelerometer handles reporting angular velocity and acceleration information to the PC, allowing for low latency orientation measurement.  The sensor supports a 1000 Hz sampling rate, and reports 16-bit per axis data over SPI.

\subsection{Magnetometer}
An STMicroelectronics LIS3MDL\footnote{\url{http://www.st.com/web/en/catalog/sense_power/FM89/SC1449/PF255198}} 3-axis magnetometer reports magnetic field data back to the PC, allowing for yaw correction of the orientation data.  The device reports over SPI with 16-bit data for all axes at a 80 Hz update rate.

\subsection{Sampling Synchronization}
Sensor samples also contain a bit indicating the display VSYNC pulse, allowing the tracking LEDs and tracking frames to be time synchronized with inertial measurements.

\subsection{Latency Tester}
The microcontroller reads the top left pixel off of the display controller each frame, sending it back to the PC in the sensor HID reports.  This allows precise continuous latency measurements to the developer and to the sensor fusion prediction algorithm.

\newpage

\section{Firmware}
The STM32L100 microcontroller on the mainboard with 128 KB of Flash contains two stages of firmware, the Bootloader and the Application.

\subsection{Bootloader}
The Bootloader firmware runs immediately on powering the headset.  If no firmware update flag was set, the Bootloader jumps to the Application firmware.  If a firmware update flag was set through previous running of the Application firmware or by holding the power button when powering on, the Bootloader firmware jumps to a mode where it is able to receive new Application firmware over the USB interface.  This allows for field updates of Application firmware.  See the Oculus Bootloader Specification for further details.

\subsection{Application}
The Application firmware interfaces to the host PC over USB to transmit sensor and timestamp data at up to 1000 Hz as well as receive configuration commands for the sensors, tracking LEDs, and display.  Calibration parameters for the LEDs, sensors, and lenses are also stored in EEPROM accessed by the Application firmware.  See the DK2 Firmware Specification for further details.

\newpage

\section{Cable}
The USB, power, and video cable for DK2 is detachable.  This custom cable allows for USB, HDMI, and power to be contained within a single 3 meter cable assembly for minimal diameter and maximum flexibility.  The HMD (sink) side of the cable connects to a HDMI Type A and a USB Mini B inline on the top of the headset.  The sink side HDMI connector contains a Spectra7 VR7100 HDMI equalizer.

On the PC (source) side, the cable breaks out into two 1 foot tails, one for HDMI Type A and one for USB Type A.  The breakout also contains a barrel connector for optional 5V power input and a 2.5mm connector for the sync signal to the Positional Tracker.  Full details on the cable are available in the DK2 Cable Specification.

\newpage

\begin{figure}[H]  
  \centering
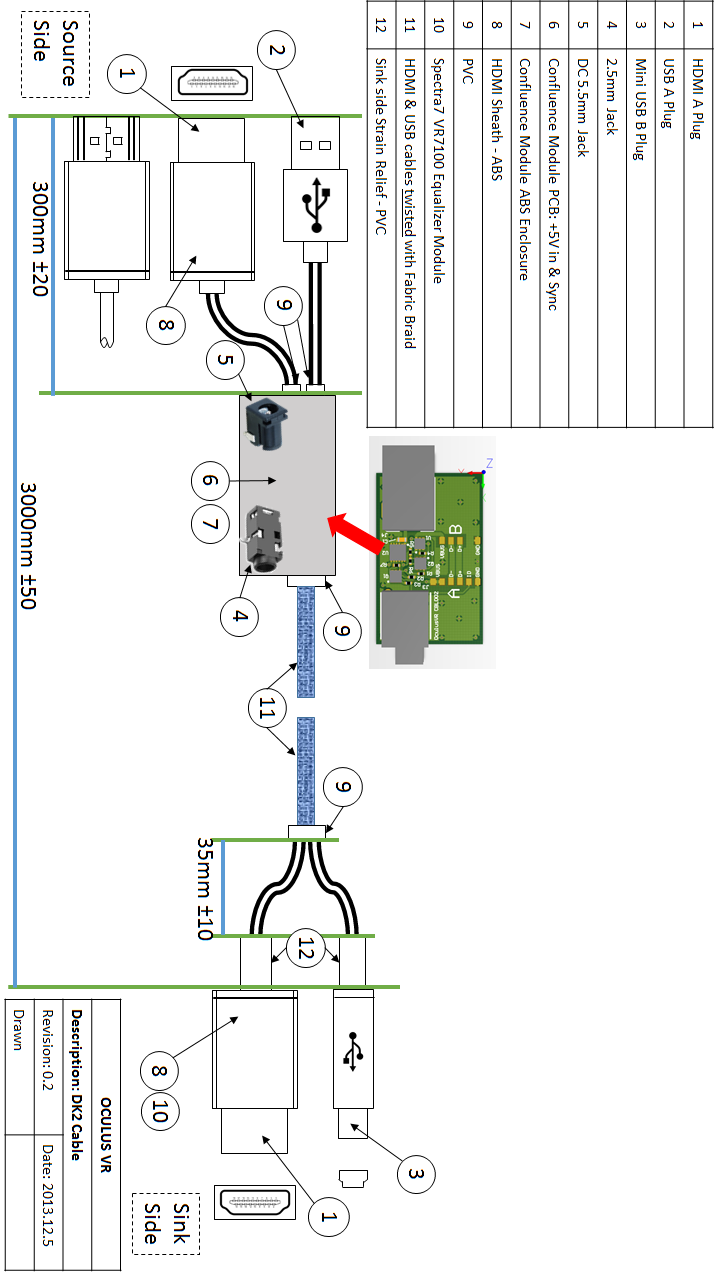
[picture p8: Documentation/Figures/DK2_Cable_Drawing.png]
    
  \caption{Rift DK 2 Cable Drawing}
  \label{Cable_Diagram}
\end{figure}

\newpage

\subsection{Molded Components}
The DK2 Cable includes custom molded backshells, confluence module enclosure, and strain relief - detailed in the following table.

\begin{center}
    \begin{tabular}{ | l | l | p{8cm} |}
    \hline
    \cellcolor{lightgray} Parameter & \cellcolor{lightgray} Specification \\ \hline
    Backshells (4) & Black plastic injection molded ABS \\ \hline
    Strain relief and join overmold & Black PVC \\ \hline
    Confluence Module Housing & Black plastic injection molded ABS \\ \hline
    Cable-Individual Jacket & Black TPE \\ \hline
    Cable-Twisted Jacket & Black fabric braid \\ \hline
    Finish (Back shells) & Glossy (Polished Tool) \\ \hline
    Finish (Strain relief and join over mold) & Matte (sandblasted tool) \\ \hline
    Finish (Module) & Matte (sandblasted tool) \\ \hline
    \end{tabular}
\end{center}

\begin{figure}[H]  
  \centering
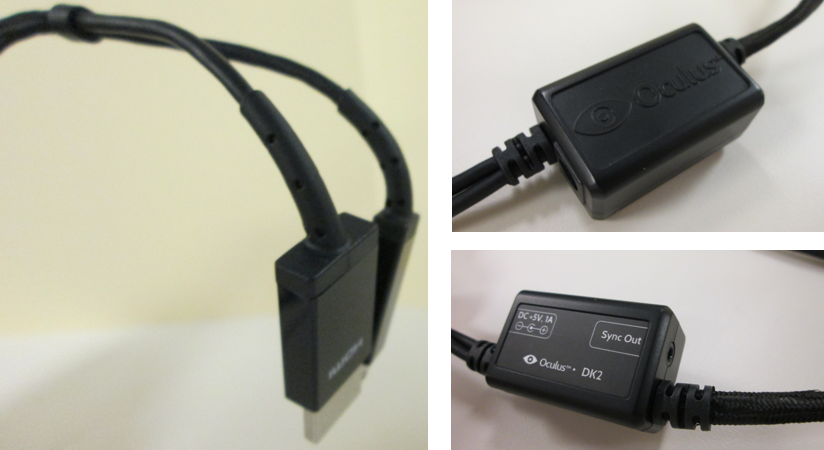
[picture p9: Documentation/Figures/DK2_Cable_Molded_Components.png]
    
  \caption{Rift DK 2 Cable molded components}
  \label{Cable_Molded_Components}
\end{figure}

\newpage

\section{Positional Tracking}
DK2 features positional tracking to a 2.5 meter distance at a 72 degree field of view. \\

Positional tracking is achieved using the Oculus SDK, based on data captured by the Positional Tracker sitting on the desk. The Positional Tracker captures snapshots of the LEDs modulating amplitudes in known patterns for LED identification, then sends the data back to the SDK for determination of position.

\subsection{Positional Tracker}
A 60hz Positional Tracker tracks the headset's spatial position within 2 meters with a 100 degree field of view using the LEDs on the front plate of the headset. This Positional Tracker is placed on the desk or atop a monitor in front of the headset with an unobstructed view of the LEDs. \\

See the Positional Tracker section of this document for more information on technical details of this system.

\subsection{LEDs}
DK2 includes 40 Vishay VSMY3850 850nm Infrared LEDs for positional tracking.  The LEDs are driven individually using constant current circuits that allow two brightness levels to be set.  The high or low setting is interfaced to the microcontroller via shift registers interfaced over SPI.  The LEDs and driving circuitry are placed on a flex PCB which is inserted into the front plastic assembly of the headset.

\subsection{Synchronization}
The IR LEDs are pulsed on only during the exposure period of the Positional Tracker.  This is achieved by driving synchronization pulse from the headset MCU to the Positional Tracker.  For DK2 the sync signal is connected to the Positional Tracker via a cable from the source (PC) side of the HMD interface.

\end{document}

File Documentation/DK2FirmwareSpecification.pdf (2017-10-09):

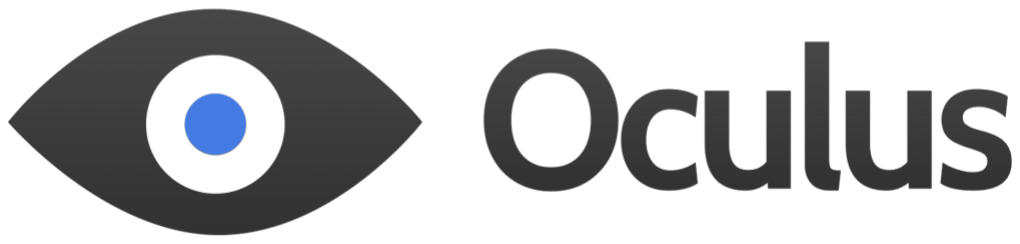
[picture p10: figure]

# DK2 Firmware Specification

Nirav Patel

Revision 0.10
28 April 2014

CONTENTS | CONTENTS

## Contents

1 Revision History | 3
2 Introduction | 4
3 HID In Report | 5
4 Feature Reports | 8
5 EDID | 24
DK2 Firmware Specification | 2

1 REVISION HISTORY

## 1 Revision History

Revision | Date | Description
0.1 | 28-11-2013 | Preliminary specification.
0.2 | 08-12-2013 | Add camera feature report.
0.3 | 11-12-2013 | Add display feature report.
0.4 | 23-12-2013 | Add magnetometer and position calibration and LED pattern reports.
0.5 | 26-12-2013 | Add keep alive, manufacturing, and uuid reports.
0.6 | 30-01-2014 | Add temperature report, modify position report.
0.7 | 13-02-2014 | Add gyro offset report.
0.8 | 18-02-2014 | Add normals to position calibration, rename camera to tracking.
0.9 | 24-02-2014 | Add lens distortion report.
0.10 | 28-04-2014 | Add basic EDID information.
DK2 Firmware Specification | 3

2 INTRODUCTION

## 2 Introduction

The Rift DK2 is interfaced using USB HID with a 1000 Hz polling rate. The device is configured using Feature Report Gets and Sets and reports back gyroscope, accelerometer, magnetometer, and synchronization timestamps through an IN Report. For more information about HID, see the Device Class Definition for Human Interface Devices¹

- Vendor ID: 0x2833
- Product ID: 0x0021
- Vendor String: Oculus VR, Inc.
- Product String: Rift DK2
- Serial String: Globally unique 20 byte Base32 string generated per device

1http://www.usb.org/developers/devclass_docs/HID1_11.pdf

DK2 Firmware Specification | 4

3 HID IN REPORT

## 3 HID In Report

The 64 byte IN report on Endpoint 1 contains the sensor data. All data is in little-endian format. The gyro and accelerometer report data at a rate of 1000 Hz, which is also the rate at which the sample time is incremented.

While the target rate for the host polling the device for the IN report is 1000 Hz, system or bus load can cause the polling to happen on longer intervals, dropping the reporting rate below 1000 Hz. For this reason, the report contains fields for up to 2 samples of gyro and accelerometer data as well as a field stating the number of samples being reported. The behavior is as follows:

- If the number of recorded samples is <= 2, the corresponding number of samples is returned with NumSamples set accordingly.
- If the number of recorded samples is > 2, the first (NumSamples -1) samples are averaged into Samples[0], while Samples[1] contains the most recent recorded sample. NumSamples is set to the total original number of recorded samples and Timestamp is set to that of the most recent sample; this allows for PC software to compensate the integration.
- DK2 does not accumulate more then 254 samples; beyond that the Num-Samples is reset to 2 and only the most recent 2 samples are reported, with the Timestamp field properly incremented to indicate the loss of samples.
DK2 Firmware Specification | 5

3 HID IN REPORT

0 | 1 | 2 | 3 | 4 | 5 | 6 | 7 | 8 | 9 | 10 11 12 13 14 15 16 17 18 19 20 21 22 23 24 25 26 27 28 29 30 31
0 | ReportID = 11 | LastCommandID | NumSamples
4 | SampleCount | Temperature
8 | SampleTimestamp
12 | Samples[0]

❤❤❤❤❤❤❤❤❤❤❤❤❤❤❤❤❤❤❤❤❤❤❤❤❤❤❤❤❤❤❤❤❤❤❤ ❤❤❤❤

❤❤❤

❤❤❤❤

❤❤❤

❤❤❤❤

❤❤❤

❤❤❤❤

❤❤❤

❤❤❤❤

❤❤❤

28 | Samples[1]

❤❤❤❤❤❤❤❤❤❤❤❤❤❤❤❤❤❤❤❤❤❤❤❤❤❤❤❤❤❤❤❤❤❤❤ ❤❤❤❤

❤❤❤❤

❤❤❤❤

❤❤❤

❤❤❤❤

❤❤❤

❤❤❤❤

❤❤❤

❤❤❤❤

❤❤

44 | | MagX | MagY
48 | | MagZ | FrameCount
52 | | FrameTimestamp
56 | FrameID | TrackingPattern | TrackingCount
60 | | TrackingTimestamp
- ReportID (8 bits): The USB Report ID for this report is 11.
- LastCommandID (16 bits): Contains the CommandID from the last Feature Report set on DK2.
- NumSamples (8 bits): The number of samples the report represents as described above.
- SampleCount (16 bits): A running counter of samples, for the number of the first sample in the report. As the internal sampling rate targets 1000 Hz, this unit is close to milliseconds.
- Temperature (16 bits): The most recent internal sensor temperature recorded by the DK2. The value is in two’s complement format, in units of centidegrees Celsius.
- SampleTimestamp (32 bits): A microsecond timestamp of the last sensor sample in the packet. This is recorded on the same clock as the Fram-
DK2 Firmware Specification | 6

3.1 Accelerometer and Gyro Sample | 3 HID IN REPORT

eTimestamp and TrackingTimestamp.

- Samples (128 bits): Each sample contains X, Y, and Z data for the gyro and accelerometer. Specified below.
- MagX, MagY, MagZ (16 bits each): The most recent data available from the magnetometer. The three axes are sampled simultaneously at up to 100 Hz. Note that consecutive reports may contain the same magnetometer data. The data is two’s complement in units of 10⁻⁴ gauss.
- FrameCount (16 bit): A running counter of frames sent to the display, incremented at each vsync.
- FrameTimestamp (32 bit): A microsecond timestamp of the last vsync sent to the display. This is recorded on the same clock as the Sample-Timestamp and TrackingTimestamp.
- FrameID (8 bit): The green value of the top left pixel in the last frame sent to the display. This is used to identify specific frames to measure the end to end latency from motion to photon.
- TrackingPattern (8 bit): The index of the last tracking LED pattern exposed to the camera.
- TrackingCount (16 bit): A running counter of camera frames triggered by the headset.
- TrackingTimestamp (32 bit): A microsecond timestamp of the last camera exposure. This is recorded on the same clock as the Sample-Timestamp and FrameTimestamp.

### 3.1 Accelerometer and Gyro Sample

The X, Y, and Z axes of the gyro and accelerometer are sampled simultaneously. The accelerometer fields are two’s complement format and 21 bits each. They are in units of m
s

2

- 10⁻⁴. The gyroscope fields are two’s complement and 21 bits each. They are in units of θ
s
- 10⁻⁴ in radians.
0 | 1 | 2 | 3 | 4 | 5 | 6 | 7 | 8 | 9 | 10 11 12 13 14 15 16 17 18 19 20 21 22 23 24 25 26 27 28 29 30 31
0 | AccelX | AccelY[0:10]
4 | AccelY[11:20] | AccelZ
8 | GyroX | GyroY[0:10]
12 | GyroY[11:20] | GyroZ
DK2 Firmware Specification | 7

4 FEATURE REPORTS

## 4 Feature Reports

### 4.1 Tracking

The 13 byte Tracking report has a ReportID of 12. It configures the infrared tracking LEDs and camera synchronization.

0 | 1 | 2 | 3 | 4 | 5 | 6 | 7 | 8 | 9 | 10 11 12 13 14 15 16 17 18 19 20 21 22 23 24 25 26 27 28 29 30 31
0 | ReportID = 12 | CommandID | Pattern
4 | a | b | c | d | e | f | ExposureLength
8 | FrameInterval | VsyncOffset
12 | DutyCycle
- ReportID (8 bits): The USB Report ID for this report is 12.
- CommandID (16 bits): A sequence number that is then repeated in the LastCommandID field of the HID IN Report.
- Pattern (8 bits): The index of the pattern of high and low intensities that is currently set on the tracking LEDs. Pattern 255 is reserved for all LEDs set high. Patterns auto-increment after each exposure if the Autoincrement bit is set in the bitmask. The Pattern starts at 0 on power on.
- (a) Enable (1 bit): This bit enables the tracking LED exposure and updating. This currently defaults to on, but will default off in a later firmware revision.
- (b) Autoincrement (1 bit): With Autoincrement set, the Pattern is incremented after every exposure. This defaults to on.
- (c) UseCarrier (1 bit): The tracking LEDs modulate at 85 kHz to allow for wireless synchronization when UseCarrier is enabled. This defaults to on.
- (d) SyncInput (1 bit): With SyncInput enabled, LED exposure is triggered from a rising edge on GPIO1. With SyncInput disabled, the LED exposure is triggered from an internal timer at FrameInterval. This defaults to off.
- (e) VsyncLock (1 bit)(Disabled): If enabled, LED exposure is triggered on panel Vsync rather than from an internal timer or external trigger. This defaults to off.
- (f) CustomPattern (1 bit): If enabled, the LED sequence will be the one loaded in using the CustomPattern report. This defaults to off.
DK2 Firmware Specification | 8

4.1 Tracking | 4 FEATURE REPORTS
- ExposureLength (16 bits): This is the length of time the tracking LEDs are enabled for in microseconds. The sync output also follows this length. This number cannot be larger than the FrameInterval. The minimum length is approximately 10 microseconds.
- FrameInterval (16 bits): When SyncInput and VsyncLock are false, the tracking LEDs are exposed on the interval set in FrameInterval in microseconds.
- VsyncOffset (16 bits)(Disabled): When VsyncLock is enabled, the exposure can be performed a fixed offset of VsyncOffset microseconds after the panel vsync.
- DutyCycle (8 bits): When UseCarrier is true, the duty cycle of the 85 kHz modulation can be increased or decreased. The default value is 128, which results in a 50% duty cycle.
DK2 Firmware Specification | 9

4.2 Display | 4 FEATURE REPORTS

### 4.2 Display

The 16 byte Display report has a ReportID of 13. It configures the display panel.

0 | 1 | 2 | 3 | 4 | 5 | 6 | 7 | 8 | 9 | 10 11 12 13 14 15 16 17 18 19 20 21 22 23 24 25 26 27 28 29 30 31
0 | ReportID = 13 | CommandID | Brightness
4 | a | b | c | d | e | f | g | h
8 | Persistence | LightingOffset
12 | PixelSettle | TotalRows
- ReportID (8 bits): The USB Report ID for this report is 13.
- CommandID (16 bits): A sequence number that is then repeated in the LastCommandID field of the HID IN Report.
- Brightness (8 bits): A relative brightness setting that is independent of pixel persistence. The field only takes effect if HighBrightness is disabled.
- (a) ShutterType (4 bits)(Read only): A read-only enum of the method in which the display is scanned and exposed.
- (b) CurrentLimit (2 bit): An enum of the current limiting mode in use.
- (c) UseRolling (1 bit): Switches between global shutter and rolling shutter update modes. This defaults to true.
- (d) ReverseRolling (1 bit): Switches the polarity on the rolling shutter mode. Reverse had the lighting of rows happen before the black period. This defaults to true.
- (e) HighBrightness (1 bit)(Disabled): This enables a mode in which maximum brightness is used, at the possible expense of panel lifetime. This defaults to false.
- (f) SelfRefresh (1 bit): This sets the panel to self refresh from the contents of its frame buffer. This defaults to false.
- (g) ReadPixel (1 bit): This enables reading the top left pixel each frame. This currently defaults to false, but will default to true in a later firmware revision.
- (h) DirectPentile (1 bit): This enables direct mapping of input data to panel sub pixel geometry, rather than using in-panel interpolation.
- Persistence (16 bits): This is the length of time in rows that the display is lit each frame. This defaults to the full size of the display, meaning full persistence.
DK2 Firmware Specification | 10

4.2 Display | 4 FEATURE REPORTS
- LightingOffset (16 bits)(Disabled): This is the offset in rows from vsync that the panel is lit when using global shutter mode. In rolling shutter, this has no effect.
- PixelSettle (16 bits)(Read only): This is the read-only time in microseconds that we estimate the pixel takes to settle to the value it is set to after it is lit.
- TotalRows (16 bits)(Read only): This is the read-only number of rows including active area and blanking used with Persistence and LightingOffset.
DK2 Firmware Specification | 11

4.3 MagCalibration | 4 FEATURE REPORTS

### 4.3 MagCalibration

The 52 byte MagCalibration report has a ReportID of 14. It contains the 3 by 4 matrix of parameters used to fit the magnetometer to a sphere. The table is stored on the headset, but the firmware does not apply it to outgoing magnetometer data.

0 | 1 | 2 | 3 | 4 | 5 | 6 | 7 | 8 | 9 | 10 11 12 13 14 15 16 17 18 19 20 21 22 23 24 25 26 27 28 29 30 31
0 | ReportID = 14 | CommandID | Version
4 | Calibration[0][0]
8 | Calibration[0][1]
12 | Calibration[0][2]
16 | Calibration[0][3]
20 | Calibration[1][0]
24 | Calibration[1][1]
28 | Calibration[1][2]
32 | Calibration[1][3]
36 | Calibration[2][0]
40 | Calibration[2][1]
44 | Calibration[2][2]
48 | Calibration[2][3]
- ReportID (8 bits): The USB Report ID for this report is 14.
- CommandID (16 bits): A sequence number that is then repeated in the LastCommandID field of the HID IN Report.
- Version (8 bits): The version of the calibration procedure used to generate the stored table.
- Calibration (48 bytes): This is the 3 by 4 matrix used to fit magnetometer data to a sphere. Each field is a 32 bit signed integer. The specific value is dependent on the calibration procedure, indicated by Version.
DK2 Firmware Specification | 12

4.4 PositionCalibration | 4 FEATURE REPORTS

### 4.4 PositionCalibration

The 30 byte PositionCalibration report has a ReportID of 15. It allows reading and storage of calibrated positions of each tracking LED as well as the inertial tracker.

0 | 1 | 2 | 3 | 4 | 5 | 6 | 7 | 8 | 9 | 10 11 12 13 14 15 16 17 18 19 20 21 22 23 24 25 26 27 28 29 30 31
0 | ReportID = 15 | CommandID | Version
4 | Position[0]
8 | Position[1]
12 | Position[2]
16 | Normal[0] | Normal[1]
20 | Normal[2] | Rotation
24 | PositionIndex | NumPositions
28 | PositionType
- ReportID (8 bits): The USB Report ID for this report is 15.
- CommandID (16 bits): A sequence number that is then repeated in the LastCommandID field of the HID IN Report.
- Version (8 bits): The version of the calibration procedure used to generate the stored positions. Note that setting the report with a Version value of 1 returns the Position values for the PositionIndex to the stored defaults.

0 - None

1 - Hard-coded default positions

2 - Factory calibrated

3 - User calibrated

- Position (12 bytes): The X, Y, and Z axis position of the LED or inertial tracker. This is a signed integer in units of micrometers. The position is relative to the center of the emitter plane of the display at nominal focus.
- Normal (6 bytes): The X, Y, and Z axis normal of the LED or inertial tracker. This is a signed integer in units of micrometers. The Normal is relative to the Position.
- Rotation (16 bits): The rotation around the normal. This is in units of 10⁻⁴ radians.
- PositionIndex (16 bits): This is the current position being read or written to. This autoincrements on reads, and gets set to the written value
DK2 Firmware Specification | 13

4.4 PositionCalibration | 4 FEATURE REPORTS

on writes.

- NumPositions (16 bits)(Read only): This is the read-only number of items with positions stored.
- PositionType (16 bits)(Read only): The type of the item which has its position reported in the current report. These are defined as:

0 - Tracking LED

1 - Inertial sensor

When setting this report, the PositionType should match that read for the PositionIndex.

DK2 Firmware Specification | 14

4.5 CustomPattern | 4 FEATURE REPORTS

### 4.5 CustomPattern

The 12 byte CustomPattern report has a ReportID of 16. It allows reading of the default LED patterns as well as reading and setting of custom patterns. Repeated reads of the report iterate through each LED, starting at 0 and wrapping at the final LED. When the CustomPattern bit of the Tracking report is not set, reads on this report act upon the default LED pattern stored in the headset, and writes have no effect. With the CustomPattern bit set, this report acts on a custom pattern array that erases when the headset is reset.

0 | 1 | 2 | 3 | 4 | 5 | 6 | 7 | 8 | 9 | 10 11 12 13 14 15 16 17 18 19 20 21 22 23 24 25 26 27 28 29 30 31
0 | ReportID = 16 | CommandID | SequenceLength
4 | Sequence
8 | LEDIndex | NumLEDs
- ReportID (8 bits): The USB Report ID for this report is 16.
- CommandID (16 bits): A sequence number that is then repeated in the LastCommandID field of the HID IN Report.
- SequenceLength (8 bits): The length of the sequence of bits that each LED goes through. Each state of the sequence is represented by two bits, allowing a maximum of 4 levels per sequence. For DK2, only states 0, 1, and 3 are meaningful, for off, low, and high respectively.
- Sequence (32 bits): The sequence that the specific LED goes through. The first SequenceLength ∗ 2 bits are used. The sequence is in order of LSB to MSB.
- LEDIndex (16 bits): This is the current LED being read or written to. This autoincrements on reads, and gets set to the written value on writes.
- NumLEDs (16 bits)(Read only): This is the read-only number of tracking LEDs which are actually present on the device.
DK2 Firmware Specification | 15

4.6 KeepAliveMux | 4 FEATURE REPORTS

### 4.6 KeepAliveMux

The 6 byte KeepAliveMux report has a ReportID of 17. It is used to specify both which IN Report is sent and the interval of sending. The interval takes effect only if the UseCommandKeepAlive or UseMotionKeepAlive bits are set
in the Config report.
0 | 1 | 2 | 3 | 4 | 5 | 6 | 7 | 8 | 9 | 10 11 12 13 14 15 16 17 18 19 20 21 22 23 24 25 26 27 28 29 30 31
0 | ReportID = 17 | CommandID | INReport
4 | Interval
- ReportID (8 bits): The USB Report ID for this report is 17.
- CommandID (16 bits): A sequence number that is then repeated in the LastCommandID field of the HID IN Report.
- INReport (8 bits): The specified number is the INReport which will be repeatedly sent until the interval is passed. For example, specifying 1 sends the DK1 IN Report, while specifying 11 sends the DK2 IN Report. The default value for DK2 is 11.
- Interval (16 bits): The interval in milliseconds used as the threshold for UseCommandKeepAlive and UseMotionKeepAlive. The default interval is 10000.
DK2 Firmware Specification | 16

4.7 Manufacturing | 4 FEATURE REPORTS

### 4.7 Manufacturing

The 16 byte Manufacturing report has a ReportID of 18. It is used to record and display the results of each stage of the production of the DK2 product that
has USB access.
0 | 1 | 2 | 3 | 4 | 5 | 6 | 7 | 8 | 9 | 10 11 12 13 14 15 16 17 18 19 20 21 22 23 24 25 26 27 28 29 30 31
0 | ReportID = 18 | CommandID | NumStages
4 | Stage | StageVersion | StageLocation
8 | StageTime
12 | Result
- ReportID (8 bits): The USB Report ID for this report is 18.
- CommandID (16 bits): A sequence number that is then repeated in the LastCommandID field of the HID IN Report.
- NumStages (8 bits)(Read only): The number of stages of production being recorded on the product.
- Stage (8 bits): The specific stage number being recorded or read from. This autoincrements on reads, and gets set to the written value on writes.
- StageVersion (8 bits): The version of the specific manufacturing test.
- StageLocation (16 bits): A bit mask representing the manufacturer, line, and machine this test was performed on. See the DK2 Testware document for details on this.
- StageTime (32 bits): The UNIX time at which the stage was performed.
- Result (32 bits): The result of the stage. See the DK2 Testware document for the details of what this means for each stage.
DK2 Firmware Specification | 17

4.8 UUID | 4 FEATURE REPORTS

### 4.8 UUID

The 23 byte UUID report has a ReportID of 19. It is used internally for manufacturing purposes, when the USB serial number is set to a default number. Outside of manufacturing, the number is identical to the USB serial number. Setting this report switches the USB serial number to the value read from this report. The value being set is ignored.

0 | 1 | 2 | 3 | 4 | 5 | 6 | 7 | 8 | 9 | 10 11 12 13 14 15 16 17 18 19 20 21 22 23 24 25 26 27 28 29 30 31
0 | ReportID = 19 | CommandID | UUID[0]
4 | UUID[1:5]
8 | UUID[5:9]
12 | UUID[9:13]
16 | UUID[13:17]
20 | UUID[17:20]
- ReportID (8 bits): The USB Report ID for this report is 19.
- CommandID (16 bits): A sequence number that is then repeated in the LastCommandID field of the HID IN Report.
- UUID (20 bytes)(Read only): The unique ID of the device.
DK2 Firmware Specification | 18

4.9 Temperature | 4 FEATURE REPORTS

### 4.9 Temperature

The 24 byte Temperature report has a ReportID of 20. It is used to store gyroscope zero rate offsets across different temperatures. The offsets are stored for certain target temperature Bins, with multiple Samples of offset data stored per temperature. When reading the report, subsequent reads of the report go sequentially through each Sample in NumSamples for each Bin in NumBins.
The headset only stores the offsets, and does not create or modify them directly.
0 | 1 | 2 | 3 | 4 | 5 | 6 | 7 | 8 | 9 | 10 11 12 13 14 15 16 17 18 19 20 21 22 23 24 25 26 27 28 29 30 31
0 | ReportID = 20 | CommandID | Version
4 | NumBins | Bin | NumSamples | Sample
8 | TargetTemperature | ActualTemperature
12 | Time
16 | Offset ❤❤❤❤❤❤❤❤❤❤❤❤❤❤❤❤❤❤❤❤❤❤❤❤❤❤❤❤❤❤❤❤❤❤❤ ❤❤❤

❤❤❤❤

❤❤❤

❤❤❤❤

❤❤❤

❤❤❤❤

❤❤❤

❤❤❤❤

❤❤❤

❤❤❤❤

- ReportID (8 bits): The USB Report ID for this report is 20.
- CommandID (16 bits): A sequence number that is then repeated in the LastCommandID field of the HID IN Report.
- Version (8 bits): The version of temperature calibration being performed.
- NumBins (8 bits)(Read only): The number of temperature bins being stored.
- Bin (8 bits): The current index of temperature bin the samples are for. This autoincrements on reading all of the Samples in the Bin, and gets set to the written value on writes.
- NumSamples (8 bits)(Read only): The number of samples being stored per temperature bin.
- Sample (8 bits): The current index of temperature offset sample. This autoincrements on reads, and gets set to the written value on writes.
- TargetTemperature (16 bits)(Read only): The target temperature in centidegrees Celsius for the current Level.
DK2 Firmware Specification | 19

4.9 Temperature | 4 FEATURE REPORTS
- ActualTemperature (16 bits): The actual temperature in centidegrees Celsius of the current Bin.
- Time (32 bits): The UNIX time that the current Sample was generated at.
- Offset (64 bits): The packed sample format with 21 bits per axis used for the IN Report, with each value in units of θ
s
- 10⁻⁴ radians, representing the estimated zero-rate gyroscope offset for the ActualTemperature.
DK2 Firmware Specification | 20

4.10 GyroOffset | 4 FEATURE REPORTS

### 4.10 GyroOffset

The 18 byte Temperature report has a ReportID of 21. It is used to fetch the headset’s most recent estimate of gyro zero-rate offset error. Note that if the headset fails to complete zero rate offset calculation, there will not be valid data
in this report, indicated by a Version field value of 0.
0 | 1 | 2 | 3 | 4 | 5 | 6 | 7 | 8 | 9 | 10 11 12 13 14 15 16 17 18 19 20 21 22 23 24 25 26 27 28 29 30 31
0 | ReportID = 21 | CommandID | Version
4 | Offset ❤❤❤❤❤❤❤❤❤❤❤❤❤❤❤❤❤❤❤❤❤❤❤❤❤❤❤❤❤❤❤❤❤❤❤ ❤❤❤

❤❤❤❤

❤❤❤

❤❤❤❤

❤❤❤

❤❤❤❤

❤❤❤

❤❤❤❤

❤❤❤

❤❤❤❤

12 | Timestamp
16 | Temperature
- ReportID (8 bits): The USB Report ID for this report is 21.
- CommandID (16 bits): A sequence number that is then repeated in the LastCommandID field of the HID IN Report.
- Version (8 bits): The version of offset calculation being performed.

0 - No offset calculated

1 - Running average terminated by motion

2 - Running average terminated by timeout

- Offset (64 bits): The packed sample format with 21 bits per axis used for the IN Report, with each value in units of θ
s
- 10⁻⁴ radians, representing the estimated zero-rate gyroscope offset.
- Timestamp (32 bits): A microsecond timestamp of the calculation of the offset. This is recorded on the same clock as the SampleTimestamp in the IN Report.
- Temperature (16 bits): The temperature the offset was calculated at.
DK2 Firmware Specification | 21

4.11 LensDistortion | 4 FEATURE REPORTS

### 4.11 LensDistortion

The 64 byte LensDistortion report has a ReportID of 22. It defines parameters used by LibOVR to correct lens distortion. Multiple reports of the same or different versions or eye reliefs may be available, defined by NumDistortions. The report defaults to factory data, but each DistortionIndex may be overwritten with new data.

0 | 1 | 2 | 3 | 4 | 5 | 6 | 7 | 8 | 9 | 10 11 12 13 14 15 16 17 18 19 20 21 22 23 24 25 26 27 28 29 30 31
0 | ReportID = 22 | CommandID | NumDistortions
4 | DistortionIndex | Bitmask | LensType
8 | Version | EyeRelief
12 | KCoefficients[0] | KCoefficients[1]
16 | KCoefficients[2] | KCoefficients[3]
20 | KCoefficients[4] | KCoefficients[5]
24 | KCoefficients[6] | KCoefficients[7]
28 | KCoefficients[8] | KCoefficients[9]
32 | KCoefficients[10] | MaxR
36 | MetersPerTanAngleAtCenter | ChromaticAberration[0]
40 | ChromaticAberration[1] | ChromaticAberration[2]
44 | ChromaticAberration[3]
48 | Unused ❤❤❤❤❤❤❤❤❤❤❤❤❤❤❤❤❤❤❤❤❤❤❤❤❤❤❤❤❤❤❤❤❤❤❤ ❤❤❤❤

❤❤❤❤

❤❤❤

❤❤❤❤

❤❤❤

❤❤❤❤

❤❤❤

❤❤❤❤

❤❤❤

❤❤❤

- ReportID (8 bits): The USB Report ID for this report is 22.
- CommandID (16 bits): A sequence number that is then repeated in the LastCommandID field of the HID IN Report.
- NumDistortions (8 bits)(Read only): The number of lens distortions being stored.
- DistortionsIndex (8 bits): The current index of lens distortion. This autoincrements on reads and gets set to the written value on writes.
DK2 Firmware Specification | 22

4.11 LensDistortion | 4 FEATURE REPORTS
- Bitmask (8 bits): A current unused bitmask.
- LensType (16 bits): The type of the lens used in the headset. These are enumerated in LibOVR.
- Version (16 bits): The version of lens distortion specified in the report. The fields after this one are dependent on the specified Version.

0 - No lens distortion stored. The remaining report is empty.

1 - LCSV CatmullRom10Version1. The fields are defined as below.

- EyeRelief (16 bits): The eye relief the distortion is designed for. This is in units of micrometers measured from the front surface of the lens.
- KCoefficients (11 fields of 16 bits): Catmull-Rom distortion coefficients. The units are defined in LibOVR.
- MaxR (16 bits): Defined in LibOVR.
- MetersPerTanAngleAtCenter (16 bits): Defined in LibOVR.
- ChromaticAberration (4 fields of 16 bits): Defined in LibOVR.
- Unused (14 bytes): Unused by LCSV CatmullRom10Version1.
DK2 Firmware Specification | 23

5 EDID

## 5 EDID

The EDID 1.3 is read over the HDMI interface by the video host.

- Manufacturer ID: OVR
- Product ID: 0x0003
- Product String: Rift DK2
- Serial String: First 13 bytes of the device UUID
DK2 Firmware Specification | 24

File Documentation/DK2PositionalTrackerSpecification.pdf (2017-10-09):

### OCULUS VR, INC

# Positional Tracker DK2 Specification

Authors:
John Robertson

Date:
May 29, 2014

Oculus VR, Inc. 19800 MacArthur Blvd Suite 200 Irvine, CA 92612

All brand names, product names or trademarks belong to their respective holders.

Disclaimer
THIS PUBLICATION AND THE INFORMATION CONTAINED HEREIN IS MADE AVAILABLE BY OCULUS VR, INC. AS IS. OCULUS VR, INC. DISCLAIMS ALL WARRANTIES, EITHER EXPRESS OR IMPLIED, INCLUDING BUT NOT LIMITED TO ANY IMPLIED WARRANTIES OF MERCHANTABIL-ITY OR FITNESS FOR A PARTICULAR PURPOSE REGARDING THESE MATERIALS.

## 1 Introduction

Positional Tracker DK2 is a High Speed USB device used to provide optical tracking data for the Oculus Rift. Its large 1/3” format global shutter image sensor enables short exposures, providing high contrast marker tracking data over a wide field of view. Targeting the standard USB Video Class (UVC) will enable wide compatibility with minimal driver development.

### 1.1 Block Diagram

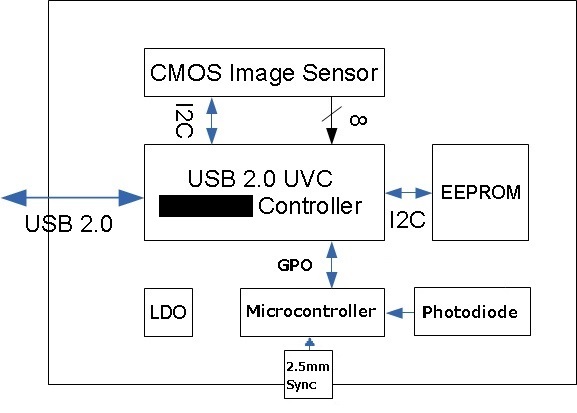
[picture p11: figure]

## 2 Industrial Design

### 2.1 PCB

The Positional Tracker DK2 PCB is 51.4x24mm with mounting holes for the M12 mount (M1.6) and housing (M2). A mini USB connector and a 2.5mm stereo jack attach to removable cables on the side of the device. A daughter-board containing a blue status LED and NIR photodiode is positioned in the front of the case.

### 2.2 Internal M12 Lens Mount

The lens mount is M12, centered on the image sensors optical axis.

### 2.3 Housing

The DK2 Positional Tracker housing design is unique industrial design and consists of two main parts, tracker housing and removable stand. Housing is designed for lens barrel attachment, cover for IR transmissive sensor, for PCBA mounting, removable filter assembly, and removable stand attachment. The housing cover has two dedicated openings for connector connection on the side. The back of the housing has dedicated recess surface area for product label attachment.

Stand Assembly is designed for removable from the housing and allow the upper housing to tilt forward and backward. The stand is design for multiple position usage and folded position for desk top uses, and unfolded position for monitor mounting uses. The bottom of stand surfaces consist with anti-slip rubber pads to minimize movement and with screw thread for tripod mounting of the tracker.

Physical Characteristics

Parameter | Specification
Housing | Black plastic injeciton molded PC
Front Coverplate | Black plastic injection molded PC IR transmissive
Stand Assembly | Black plastic injection molded PC
Weight | 70 grams
Finish (Housing) | Matte (Sandblasted Tool)
Finish (Cover Plate) | Glossy (Polished Tool)
Finish (Stand) | Matte (Sandblasted Tool)

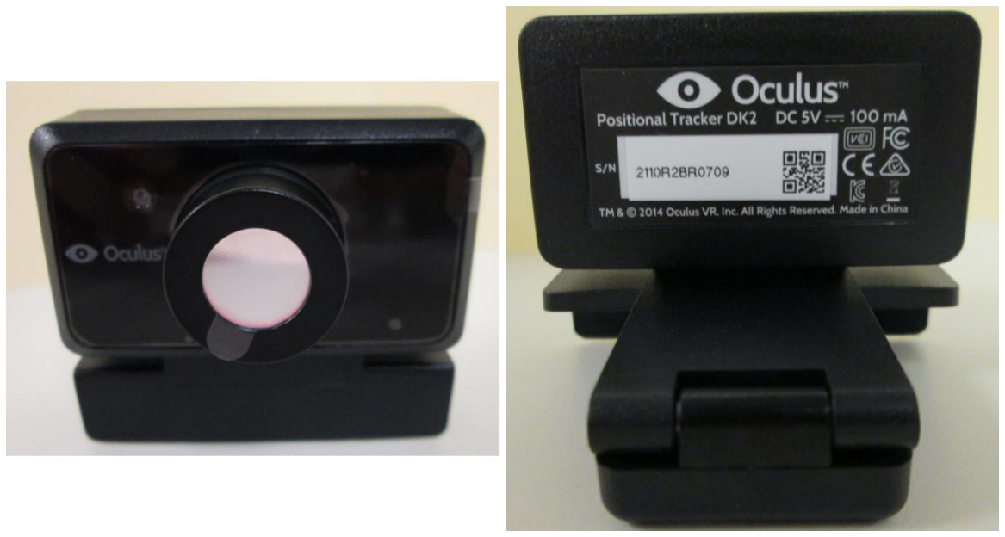
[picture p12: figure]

## 3 Optical System

The optical system consists of a 850nm band-pass filter, lens, lens-mount, and image sensor.

### 3.1 Image Sensor

The image sensor used in the Positional Tracker DK2 is Aptina MT9V034C12STC CMOS sensor¹ with the following feature set:

- 752x480 pixel resolution
- Color (Bayer filter array pattern)
- 60 FPS at full resolution
- 1/3” image format
- Global shutter
- High sensitivity at 850 nm

### 3.2 Lens Optics

The optical system will use low profile lens with a M12 mount. The target for field of view is 70◦ horizontal. Like the viewing optics, distortion in the edges of the field can be corrected for in software, allowing for use of smaller/cheaper optics than would be possible with stringent distortion requirements. A NIR 850nm band-pass filter is included to enable play in high ambient lighting conditions (with some minor transmission loss in the NIR band).

1http://www.aptina.com/products/image_sensors/mt9v034c12stm/

## 4 Microcontroller

The Positional Tracker DK2 will include a STM8S003F3 microcontroller to handle synchronization between the LEDs on the HMD and the image sensor exposure. The STM8S003F3 is programmed over a standard 4-pin SWIM header, and controls a status LED. Field upgrades over USB are not supported.

The microcontroller contains the following I2C registers for configuration:

Address | Name | Description
0x00 | FW VERSION | Firmware version number
0x02 | SYNC PERIOD | Timeout to wait between wired syncs before switch to NIR if enabled
0x03 | EXT SYNC PERIOD | Detected external sync period
0x05 | LED ON START | LED PWM start count
0x06 | LED TOTAL | LED PWM total count
0x07 | SYNC SOURCE SEL | Current sync mode (0 == WIRE, 1 == NIR)
0x08 | NIR SYNC EN | Set to 0 (default) disables NIR sync option, otherwise enabled

## 5 USB 2.0 UVC Controller

To handle USB 2.0 HS isochronous transfers of image sensor frame data to the computer, an Etron eSP570 2 is used. This part is interfaced to the image sensor over a 8-bit image data bus, with status/control strobes, and I2C for image sensor register access. The eSP570 implements the standard USB Video device Class (UVC 1.1) 3 via its internal 8051 core.

Etron claims 50 percent of the UVC controller market in China 4

Firmware is loaded onto the attached EEPROM over USB. The eSP570 part ships with an internal bootloader, so that new devices can be immediately programmed over USB. There is a Windows programming tool that loads the firmware binary into the EEPROM. Field upgrades are supported.

2http://www.etron.com/en/products/PositionalTrackerDK2_detial.php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

28&pages=PR&seq=201

## 6 Data Stored in EEPROM

Address | Size | Name | Written by
0x0000 | Variable, max 0x1000 bytes | Etron Firmware | Jabil Etron Programmer
0x2000 | Variable, max 0x800 bytes | Calibration block | Bundle Adjustment Testware
0x2800 | 32 | Serial Number | Bundle Adjustment Testware
0x2820 | 32 | Jabil Serial Number | Jabil Software

### 6.1 Calibration Block

The calibration block is a variable length block that contains calibration parameters and CRC in little endian

typedef struct
{
UINT32 magic; // should always be 0xe2978900
UINT16 length; // length of serialization block plus this header UINT16 version; // 1 for simple list of coefficients
UINT16 coefficientCount; // 9 for version 1
UINT32 crc; // Checksum of coefficients in this block
} CalibrationHeader;

Each calibration value is specified with a calibration header:

typedef struct
{
UINT16 identifier;
UINT16 length; // Size of this block plus header
} CalibrationValue;

CRC is computed with the entire block and the CRC value as 0

### 6.2 Serial Number

- 20 bytes HMD GUID
- 12 bytes Jenkins hash of 20 byte HMD GUID

### 6.3 Jabil Serial Number

- 0-7 bytes epoch date in milliseconds LE, 8-31 bytes Jabil serial number incrementing from 0 LE

## 7 Image sensor syncrhonization to external strobe

Synchronizing the image sensor exposure to the illumination of the IR LEDs on the HMD allows for minimum exposure time and LED power consumption.

A Vishay TSOP75585NTT IR Receiver module demodulates the signal emitted from the LEDs on the HMD to trigger the image sensor exposure. The TSOP75585NTT has a field of view comparable to the image sensor lens, such that it can receive a sync signal when the HMD is in the image sensors field of view. While the HMD LEDs are not in view, the STM8S003F3 microcontroller can be continue to trigger the image sensors exposure at the set frame rate. To relax the synchronization constraint, the image sensor exposure must be extended relative to the LED on time (for 150us LED, 300us shutter is used) when in NIR sync mode.

The 2.5mm stereo jack provides a sync signal and ground from the HMD. This cable can be used as an alternative to the IR sync (noisy environments). The 2.5mm sync signal has priority over the IR sync.

The image sensor triggers exposure on negative sync edges

## 8 USB Identification

- Vendor ID: 0x2833
- Product ID: 0x0201
- Vendor String: Oculus VR, Inc.
- Product String: Positional Tracker DK2
- Supported Resolutions: 752x480 60fps

## 9 Using the Positional Tracker DK2

All target operating systems include support for UVC-compatible image sensors for streaming video data. Demosaicing can be preformed in usermode after acquiring the data.

### 9.1 Windows

Windows 7,8 have a system-supplied universial serial bus Video Class driver 5
, UsbVideo.sys (Windows XP support may require SP2). The image data is packed in a YUY2 container with half the horizontal resolution (two raw pixels per YUY2 pixel).

### 9.2 Linux

UVC 1.1 video streaming is supported by the Linux UVC driver 6 from 2.6.26 this is included in kernel source distribution.

### 9.3 Mac OS X

Mac OS X has shipped with a UVC driver since version 10.4.3

5http://msdn.microsoft.com/en-us/library/windows/hardware/ff568651.aspx6http://www.ideasonboard.org/uvc/

## 10 Revision History

Revision | Date | Description
0.8 | 29-05-2014 | Cleanup
0.7 | 19-05-2014 | Part number updates, USB Product String, EEPROM map, STM8S I2C regs data
0.6 | 18-12-2013 | Part number updates, USB Product String
0.5 | 20-10-2013 | Cleanup
0.4 | 18-10-2013 | Included sync information, removed accelerometer, added microcontroller. Specified color Aptina part.
0.3 | 19-8-2013 | Fixed markup
0.2 | 30-7-2013 | Updated block diagram.
0.1 | 27-7-2013 | Preliminary specification.

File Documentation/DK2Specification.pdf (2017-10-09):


# DK2 Specification

Nirav Patel
Nate Mitchell
Kam Chin
Ryan Brown

Revision 0.4
30 May 2014

CONTENTS | CONTENTS

## Contents

1 Revision History | 3
2 Introduction | 4
3 Box Contents | 5
4 Primary Vendors | 6
5 Industrial and Mechanical Design | 7
6 Optics | 12
7 Display | 14
8 Positional Tracker | 16
9 Mainboard | 17
10 Microcontroller and Sensors | 19
11 Firmware | 21
DK2 Specification 0.4 | 2

CONTENTS | CONTENTS
12 Cable | 22
13 Positional Tracking | 25
DK2 Specification 0.4 | 3

1 REVISION HISTORY

## 1 Revision History

Revision | Date | Description
0.1 | 18-9-2013 | Preliminary specification.
0.2 | 3-10-2013 | Modifications from specification review.
0.3 | 5-22-2014 | Updated to current design.
0.4 | 5-30-2014 | Updates to cable and optics.
DK2 Specification 0.4 | 4

2 INTRODUCTION

## 2 Introduction

The Oculus Rift is a virtual reality headset designed for immersive gaming. Development Kit 2 (DK2) is the second iteration of the development kit that game developers use to build games and applications for the consumer version of the Rift.

DK2 introduces a number of new features over DK1, including:

- Higher image quality via a 1080x1920 pixel resolution AMOLED display
- Positional head tracking via an external Positional Tracker and headset IR LEDs
- Extensibility via a user accessible USB port
DK2 Specification 0.4 | 5

3 BOX CONTENTS

## 3 Box Contents

The Oculus Rift Development Kit 2 includes the following:

- Headset with detachable cable
- Lenses - 2 sizes and cleaning cloth
- Positional Tracker
- Positional Tracker USB cable
- Positional Tracker sync cable
- 1 DVI to HDMI adapter
- Power adapter and 4 plugs: US (attached), UK, AU, EU
DK2 Specification 0.4 | 6

4 PRIMARY VENDORS

## 4 Primary Vendors

- Vishay
- STMicroelectronics
- Toshiba
- Richtek
- InvenSense
- Samsung Display
- Berway
- Jabil
- Elka
- Cypress
- Coxon
- Aptina
- Etron
- Boowon
DK2 Specification 0.4 | 7

5 INDUSTRIAL AND MECHANICAL DESIGN

## 5 Industrial and Mechanical Design

DK2 is designed to be comfortable, lightweight, and durable for Virtual Reality game and content developers. The industrial design is comprised of three distinct sections: the physical plastic panel, optics, and electronics housing, the foam and rubber facial interface, and mounting straps. The total weight of the unit is 440 grams.

### 5.1 Housing

The DK2 headset shell is outer front cover and designed for IR transmissive cover for position tracking LEDs. This shell shape is unique industrial design and consists cable door, power button, power light pipe, Aux/USB light pipe and rubber plug. It also cover for HMD controller board. The shell interconnects with DK2 cable and Facial Interface. It has a dedicated location for product label behind both connectors. The shell has a nose recess allowing for nose clearance when the shell is assembled to other optical mounting base.

Parameter | Specification
Housing | Black plastic injection molded ABS IR Transmissive
Weight | 97.5 grams
Finish | Matte (Sandblasted Tool)


DK2 Specification 0.4 | 8

5.2 Internal Structure 5 INDUSTRIAL AND MECHANICAL DESIGN

### 5.2 Internal Structure

The DK2 Mounting Base is inner part of the HMD unit where optics and panel are mounted together. Two eyecups are mounted into the Mounting Base from user viewing side and panel with rubber cushion is mounted on the other side of the Base with Frame. The mounting base design is highly leveraged from DK1. The Base is an interface part for Front Cover Shell and Facial Interface. The Base has a nose recess and maximized for nose clearance and optical viewing.

Parameter | Specification
Housing | Black plastic injection molded ABS
Weight | 176.5 grams
Finish | Matte (light textured tool)

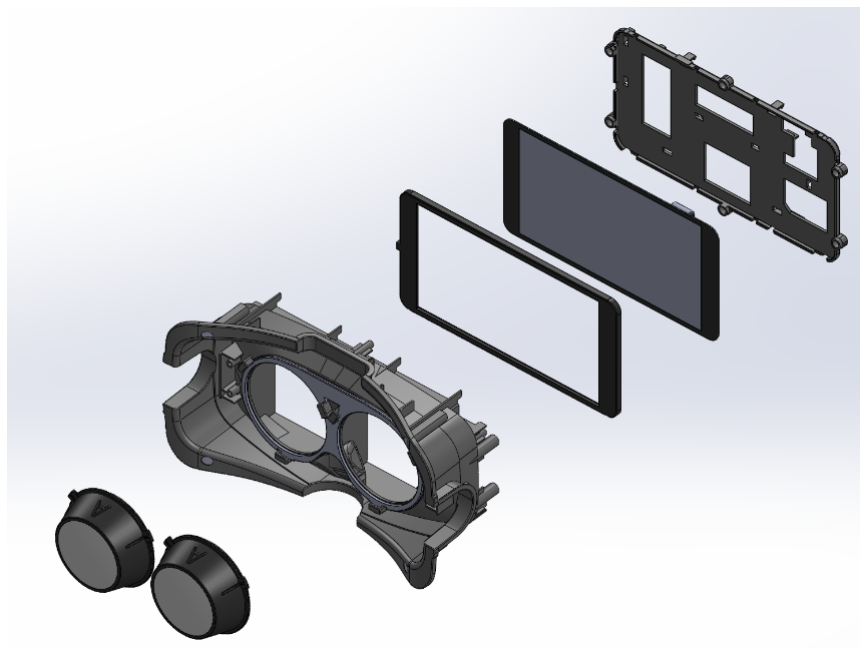
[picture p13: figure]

### 5.3 Eye Relief Adjustment

To allow for a wide variety of face shapes, the entire housing assembly containing the panel and optics can be adjusted closer and farther from the user’s face using a coin on the mechanisms on the left and right sides of the headset.

DK2 Specification 0.4 | 9

5.4 Facial Interface and Straps5 INDUSTRIAL AND MECHANICAL DESIGN
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

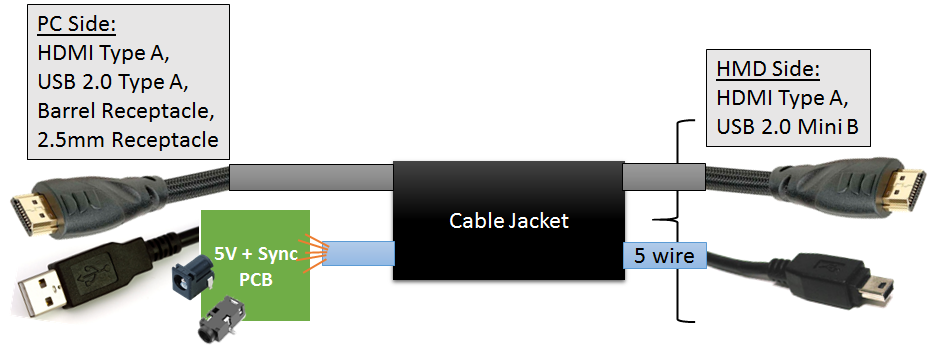
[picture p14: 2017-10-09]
Documentation/Figures/DK2_Cable.png

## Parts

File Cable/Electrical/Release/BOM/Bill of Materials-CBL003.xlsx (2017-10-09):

Manufacturer_PN | Comment | Designator | Manufacturer | Quantity | Description
C1608X5R1C225K080AB | CAP, X7R, 2.2 uF, 10%, 16 V, 0603 | C1 | TDK | 1 | ='CAP, ' + Material + ', ' + Value + ', ' + Tolerance + ', ' + Voltage + ', ' + Package
GRM21BR60J226ME39L | 2.2E-5 | C2 | Murata | 1 | CAP, CERAMIC, 22UF, ±20%, 6.3V, X5R, 0805
GRM1885C1H102JA01D | 1E-9 | C3 | Murata | 1 | CAP, CERAMIC, 1000PF, ±10%, 50V, C0G, 0603
GRM155R61A105KE15D | 1E-6 | C4, C5 | Murata | 2 | CAP, CERAMIC, 1uF, ±10%, 10V, X5R, 0402
GRM31CR60J107ME39L | 0.0001 | C6 | Murata | 1 | CAP, CERAMIC, 100UF, ±20%, 6.3V, X5R, 1206
BAS40L,315 | BAS40L,315 | D1 | NXP | 1 | DIODE, SCHOTTKY, 40V, SOD882
VCUT07B1-HD1 | VCUT07B1-HD1 | D2, D3 | Vishay | 2 | DIODE, ESD SUPPRESSOR, SINGLE LINE BI-DIRECTIONAL, LLP1006-2L
SJ-2509N | SJ-2509N | J3 | CUI | 1 | CONN, 2.5MM AUDIO JACK
KLDX-0202-A | DC Jack | J4 | Kycon | 1 | CONN, DC POWER JACK
BC856BS | TRANSISTOR, DUAL PNP, SOT363 | Q1 | NXP | 1 | ='TRANSISTOR, DUAL PNP, ' + Package
BC847BDW1T3G | TRANSISTOR, DUAL NPN, SOT363 | Q2 | ON Semi | 1 | ='TRANSISTOR, DUAL NPN, ' + Package
FDMA420NZ | FDMA420NZ | Q3 | Fairchild Semiconductor | 1 | TRANS, NMOS, DFN2020-6
RC0402FR-0710KL | RES, 0402, 10K, 1%, 1/16 W | R1, R4, R5, R7, R12 | Yageo | 5 | ='RES, ' + Package + ', ' + Value + ', ' + Tolerance + ', ' + Power
RK73H1ETTP1003F | RES, 0402, 100K, 1%, 1/16 W | R2, R3, R6, R9, R10 | KOA Speer | 5 | ='RES, ' + Package + ', ' + Value + ', ' + Tolerance + ', ' + Power
RC0402FR-0718KL | RES, 0402, 18K, 1%, 1/16 W | R8, R11 | Yageo | 2 | ='RES, ' + Package + ', ' + Value + ', ' + Tolerance + ', ' + Power
NCP380HMUAJAATBG | NCP380HMUAJAATBG | U1 | ON Semi | 1 | IC, LOAD SWITCH, UDFN6
NCP374MU075TXG | NCP374MU075TXG | U2 | ON Semiconductor | 1 | IC, LOAD SWITCH WITH OVP/RVP, LLGA-12

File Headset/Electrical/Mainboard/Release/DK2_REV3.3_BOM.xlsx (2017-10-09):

Comment | Part Number | Description | Designator | Manufacturer | Quantity
0.1uF | GRM155R71C104KA88D | CAP, CERAMIC, 0.1uF, ±10%, 16V, X7R, 0402 | C4, C7, C9, C13, C15, C18, C22, C26, C29, C30, C31, C32, C33, C36, C39, C42, C43, C44, C45, C46, C47, C51, C53, C55, C56, C57, C59, C60, C80, C81, C82, C83, C84, C85, C93, C94, C95, C96, C97, C100, C101, C102 | MURATA ELECTRONICS | 42
0.01uF | GRM155R71E103KA01D | CAP, CERAMIC, 0.01uF, ±10%, 25V, X7R, 0402 | C2, C5, C8, C10, C11, C14, C16, C19, C20, C23, C24, C27, C35, C52 | MURATA ELECTRONICS | 14
22uF | CL21A226MPQNNNE | CAP, CERAMIC, 22uF, ±20%, 10V, X5R, 0805 | C64, C71, C72, C73, C74, C75, C76, C86, C88, C89, C91, C92, C98 | SAMSUNG | 13
1uF | GRM155R61A105KE15D | CAP, CERAMIC, 1uF, ±10%, 10V, X5R, 0402 | C1, C34, C40, C41, C58, C61, C62, C77, C78, C79, C87 | MURATA ELECTRONICS | 11
10K | ERJ-2RKF1002X | RES, 10K OHM, 1/10W, ±1%, 0402 | R9, R15, R19, R21, R27, R35, R36, R42, R50, R54 | PANASONIC | 10
10uF | GRM188R60J106ME47D | CAP, CERAMIC, 10uF, ±20%, 6.3V, X5R, 0603 | C3, C6, C12, C17, C21, C25, C49, C54, C68, C70 | MURATA ELECTRONICS | 10
100K | ERJ-2RKF1003X | RES, 100K OHM, 1/10W, ±1%, 0402 | R10, R16, R22, R23, R32, R33, R34, R37 | PANASONIC | 8
2K | ERJ-2RKF2001X | RES, 2K OHM, 1/10W, ±1%, 0402 | R1, R2, R3, R25, R26, R30 | PANASONIC | 6
BLM18KG221SN1D | BLM18KG221SN1D | FERRITE CHIP BEAD, 220 OHM @ 100MHz, 2.2A, 0603 | FB1, FB2, FB3, FB4, FB5, FB6 | MURATA ELECTRONICS | 6
340R | ERJ-2RKF3400X | RES 340 OHM, 1/10W, ±1%, 0402 | R45, R46, R47, R48, R49 | PANASONIC | 5
DMC2038LVT | DMC2038LVT | FET, COMPLEMENTARY, LOGIC LEVEL | Q1, Q2, Q3, Q4, Q6 | DIODES INC | 5
ESDAXLC6-1BT2 | ESDAXLC6-1BT2 | DIODE, ESD SUPPRESSOR, SINGLE LINE BI-DIRECTIONAL, LOW CAPACITANCE | D3, D4, D6, D7, D8 | ST MICROELECTRONICS | 5
STP16CPC26 | STP16CPC26TTR | IC, LED DRIVER, 16-BIT CONSTANT CURRENT SINK DRIVER | U16, U17, U18, U19, U20 | STMICROELECTRONICS | 5
22R | ERJ-2RKF22R0X | RES, 22 OHM, 1/10W, ±1%, 0402 | R11, R13, R14, R31 | PANASONIC | 4
4.7K | ERJ-2RKF4701X | RES, 4.7K OHM, 1/10W, ±1%, 0402 | R39, R41, R53 | PANASONIC | 3
4.7uF | C1005X5R0J475K | CAP, CERAMIC, 4.7uF, ±10%, 6.3V, X5R, 0402 | C28, C65, C66 | TDK CORPORATION | 3
47K | ERJ-2RKF4702X | RES, 47K OHM, 1/10W, ±1%, 0402 | R5, R20, R28 | PANASONIC | 3
BLM15EG121SN1D | BLM15EG121SN1D | FERRITE CHIP BEAD, 120 OHM @ 100MHz, 1.5A, 0402 | FB9, FB10, FB11 | MURATA ELECTRONICS | 3
HSP061-4NY8 | HSP061-4NY8 | IC, 4-LINE ESD PROTECTION ARRAY, HIGH SPEED | U2, U3, U4 | STMICROELECTRONICS | 3
100uF | GRM31CR60J107ME39K | CAP, CERAMIC, 100uF, ±20%, 6.3V, X5R, 1206 | C48, C103 | MURATA ELECTRONICS | 2
2.2uH | NR3015T2R2M | INDUCTOR, SHIELDED POWER, 2.2uH, 1.5A | L3, L4 | TAIYO YUDEN | 2
20pF | GRM1555C1H200JA01D | CAP, CERAMIC, 20pF, ±5%, 50V, NP0, 0402 | C37, C38 | MURATA ELECTRONICS | 2
22pF | GRM1535C1H220JDD5D | CAP, CERAMIC, 22pF, ±5%, 50V, NP0, 0402 | C63, C67 | MURATA ELECTRONICS | 2
4.7uH | 252010CDMCDS-4R7MC | INDUCTOR, SHIELDED POWER, 4.7uH, 1.4A | L5, L6 | SUMIDA | 2
470R | ERJ-2RKF4700X | RES, 470 OHM, 1/10W, ±1%, 0402 | R7, R12 | PANASONIC | 2
BLM21PG220SN1D | BLM21PG220SN1D | FERRITE CHIP BEAD, 22 OHM @ 100MHz, 6A, 0805 | FB7, FB8 | MURATA ELECTRONICS | 2
ECMF02-2AMX6 | ECMF02-2AMX6 | IC, COMMON MODE FILTER WITH ESD PROTECTION FOR MIPI | U7, U8 | STMICROELECTRONICS | 2
LED | LNJ926W8CRA | LED, BLUE, 0603 | D1, D5 | PANASONIC | 2
M74VHC1GT50DFT2G | M74VHC1GT50DFT2G | IC, NON-INVERTING BUFFER, CMOS LOGIC LEVEL SHIFTER | U22, U23 | ON SEMICONDUCTOR | 2
MMZ1005S601C | MMZ1005S601C | FERRITE CHIP BEAD, 600 OHM @ 100MHz, 300mA, 0402 | L1, L2 | TDK CORPORATION | 2
YC124-JR-0722R | YC124-JR-0722R | RESISTOR ARRAY, 4 RESISTORS, 22 OHM, 5%, 0.5MM PITCH | RA1, RA2 | YAGEO | 2
100R | ERJ-2RKF1000X | RES, 100 OHM, 1/10W, ±1%, 0402 | R38 | PANASONIC | 1
10R | ERJ-2RKF10R0X | RES, 10 OHM, 1/10W, ±1%, 0402 | R51 | PANASONIC | 1
10uH | NR3015T100M | INDUCTOR, SHIELDED POWER, 10uH, 730mA | L7 | TAIYO YUDEN | 1
11163-106004-03 | 11163-106004-03 | CONNECTOR, USB MINI B, R/A, SMD | J8 | BERWAY TECHNOLOGY | 1
1M | ERJ-2RKF1004X | RES, 1M OHM, 1/10W, ±1%, 0402 | R18 | PANASONIC | 1
1nF | GRM155R71H102KA01D | CAP, CERAMIC, 1nF, ±10%, 50V, X7R, 0402 | C69 | MURATA ELECTRONICS | 1
2.2uH | SRP6540-2R2M | INDUCTOR, SHIELDED POWER, 2.2uH, 9A | L8 | BOURNES | 1
24K | ERJ-2RKF2402X | RES, 24K OHM, 1/10W, ±1%, 0402 | R52 | PANASONIC | 1
330R | ERJ-2RKF3300X | RES, 330 OHM, 1/10W, ±1%, 0402 | R8 | PANASONIC | 1
33R | ERJ-2RKF33R0X | RES, 33 OHM, 1/10W, ±1%, 0402 | R6 | PANASONIC | 1
453K | ERJ-2RKF4533X | RES, 453K OHM, 1/10W, ±1%, 0402 | R29 | PANASONIC | 1
470uF | 6TPB470M | CAP, TANTALUM, 470uF, ±20%, 6.3V, 7343-38 | C90 | PANASONIC | 1
47151-0001 | 47151-0001 | CONNECTOR, HDMI TYPE A, R/A, SMD | J2 | MOLEX | 1
62684-452100ALF | 62684-452100ALF | CONNECTOR, FPC HEADER, 45 POS, 0.5MM PITCH | J10 | FCI | 1
649R | ERJ-2RKF6490X | RES, 649 OHM, 1/10W, ±1%, 0402 | R24 | PANASONIC | 1
AXE440124 | AXE440124 | CONNECTOR, 40-PIN HEADER, 0.4MM PITCH | J1 | PANASONIC | 1
BC856S | BC856S H6327 | TRANSISTOR, DUAL SILICON PNP | Q5 | INFINEON | 1
CY7C65632-28LTXCT | CY7C65632-28LTXCT | IC, USB 2.0 HUB CONTROLLER, 4-PORT, STT | U6 | CYPRESS SEMICONDUCTOR | 1
FUWEI-12.000-20-20-40 | FUWEI-12.000-20-20-40 | CRYSTAL, 12MHZ, +/-30PPM, 20pF, HC-49USX | X1 | BERWAY TECHNOLOGY | 1
FXMA2102L8X | FXMA2102L8X | IC, I2C TRANSLATOR, BUFFER AND REPEATER | U24 | FAIRCHILD SEMICONDUCTOR | 1
LD59015C30R | LD59015C30R | IC, LDO REGULATOR, 3.0V, 150mA, HIGH PSRR | U13 | STMICROELECTRONICS | 1
LED | LNJ437W84RA | LED, AMBER, 0603 | D2 | PANASONIC | 1
LIS3MDL | LIS3MDLTR | IC, MEMS 3 AXIS MAGNETOMETER | U12 | STMICROELECTRONICS | 1
M24C02-WDW6TP | M24C02-WDW6TP | IC, EEPROM, I2C, 2kB | U25 | STMICROELECTRONICS | 1
M24C32-RDW6TP | M24C32-RDW6TP | IC, EEPROM, I2C, 32 Kbits | U10 | STMICROELECTRONICS | 1
MPU-6500 | MPU-6500 | IC, MEMS 3 AXIS GYROSCOPE AND 3 AXIS ACCELEROMETER | U11 | INVENSENSE | 1
PJ-2019-3 | PJ-2019-3 | CONNECTOR, 2.5MM STEREO AUDIO JACK | J5 | BERWAY TECHNOLOGY | 1
RT-USBA-F198 | RT-USBA-F198 | CONNECTOR, USB TYPE A RECEPTICLE, MID MOUNT | J7 | BERWAY TECHNOLOGY | 1
RT8075ZQW | RT8075ZQW | IC, DUAL STEP DOWN CONVERTER, 1A, 1.25MHz | U14 | RICHTEK | 1
ST1S31PUR | ST1S31PUR | IC, BUCK REGULATOR, 3A | U21 | STMICROELECTRONICS | 1
STM32L100RBT6 | STM32L100RBT6 | IC, STM32L MICROCONTROLLER, ARM CORTEX M3 | U5 | ST MICROELECTRONICS | 1
STMPS2141STR | STMPS2141STR | IC, USB POWER DISTRIBUTION SWITCH, 500mA CURRENT LIMIT | U9 | STMICROELECTRONICS | 1
TA-27.000MBE-T | TA-27.000MBE-T | OSCILLATOR, 27MHz, MEMS, 3.3V, 50PPM | Y1 | TXC | 1
TC358779XBG | TC358779XBG | IC, HDMI RX TO MIPI DSI TX BRIDGE | U1 | TOSHIBA | 1
TPS65632ARTER | TPS65632ARTER | IC, TRIPLE OUTPUT AMOLED DISPLAY POWER SUPPLY | U15 | TEXAS INSTRUMENTS | 1
TS-TL3330E | TS-TL3330E | SWITCH, TACTILE, SPST-NO, 250gf | SW1 | BERWAY TECHNOLOGY | 1

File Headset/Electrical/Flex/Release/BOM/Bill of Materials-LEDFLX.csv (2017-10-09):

Designator | Quantity | Manufacturer | ManufacturerPN | Footprint
D1, D2, D3, D4, D5, D6, D7, D8, D9, D10, D11, D12, D13, D14, D15, D16, D17, D18, D19, D20, D21, D22, D23, D24, D25, D26, D27, D28, D29, D30, D31, D32, D33, D34, D35, D36, D37, D38, D39, D40 | 40 | Vishay | VSMY3850 | VISHAY_PLCC2_A

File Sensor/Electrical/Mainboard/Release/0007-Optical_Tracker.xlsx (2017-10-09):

Comment | Description | Designator | Footprint | LibRef | Manufacturer 1 | Manufacturer Part Number 1 | Quantity | Supplier 1 | Supplier Part Number 1
1uF | CAP CER 1UF 6.3V 20% X5R 0402 | C1, C15, C16 | CAP_CERAMIC_0402 | CAP, CERAMIC | Panasonic Electronic Components | ECJ-0EB0J105M | 3 | Digi-Key | PCC2257CT-ND
12pF | CAP CER 12PF 50V 5% NP0 0402 | C2, C3 | CAP_CERAMIC_0402 | CAP, CERAMIC | Kemet | C0402C120J5GACTU | 2 | Digi-Key | 399-1013-1-ND
0.1uF | CAP CER 0.1UF 6.3V 20% X5R 0402 | C4, C5, C6, C8, C9, C10, C14, C17, C19, C21, C22, C23, C24, C25, C28, C29, C30, C31 | CAP_CERAMIC_0402 | CAP, CERAMIC | Kemet | C0402C104M9PACTU | 18 | Digi-Key | 399-8944-1-ND
4.7uF | CAP CER 4.7UF 6.3V 20% X5R 0402 | C7, C20, C26, C27 | CAP_CERAMIC_0402 | CAP, CERAMIC | Taiyo Yuden | JMK105BBJ475MV-F | 4 | Digi-Key | 587-2787-1-ND
2200pF | CAP CER 2200PF 50V 10% X7R 0402 | C11, C12 | CAP_CERAMIC_0402 | CAP, CERAMIC | Murata Electronics North America | GRM155R71H222KA01D | 2 | Digi-Key | 490-1305-1-ND
10uF | CAP CER 10UF 6.3V 20% X5R 0603 | C13, C18 | CAP_CERAMIC_0603 | CAP, CERAMIC | TDK Corporation | C1608X5R1A106M080AC | 2 | Digi-Key | 445-6853-1-ND
0513870578 | CONN RECEPT MINIUSB R/A 5POS SMD | J1 | 0513870578 | 0513870578 | Molex Inc | 0513870578 | 1 | Digi-Key | WM5462CT-ND
KYCON STX-2500-3NTR | Phone Connectors SJ 2.5MM SMT 3POS | J2 | KYCON_STX2500 | AUDIO_JACK_3P | Kycon | STX-2500-3NTR | 1 | Mouser | 806-STX-2500-3NTR
BLM18KG221SN1D | FERRITE CHIP 220 OHM 2200MA 0603 | L1, L2 | INDUCTOR_0603 | INDUCTOR | Murata Electronics North America | BLM18KG221SN1D | 2 | Digi-Key | 490-5255-1-ND
PPTC022LFBN-RC | Header, 2-Pin, Dual row | P1 | HDR2X2 | Header 2X2 | Sullins Connector Solutions | PPTC022LFBN-RC | 1 | Digi-Key | S7070-ND
10K | RES 10K OHM 1/10W 1% 0402 SMD | R1, R4, R5, R6, R9, R10, R11 | RESISTOR_0402 | RESISTOR | Panasonic Electronic Components | ERJ-2RKF1002X | 7 | Digi-Key | P10.0KLCT-ND
2.2K | RES 2.2K OHM 1/10W 1% 0402 SMD | R2, R3, R7, R8, R14, R15 | RESISTOR_0402 | RESISTOR | Panasonic Electronic Components | ERJ-2RKF2201X | 6 | Digi-Key | P2.20KLCT-ND
1M | RES 1M OHM 1/10W 1% 0402 SMD | R12 | RESISTOR_0402 | RESISTOR | Panasonic Electronic Components | ERJ-2RKF1004X | 1 | Digi-Key | P1.00MLCT-ND
6.2K | RES 6.2K OHM 1/10W 1% 0402 SMD | R13 | RESISTOR_0402 | RESISTOR | Panasonic Electronic Components | ERJ-2RKF6201X | 1 | Digi-Key | P6.20KLCT-ND
30 | RES 30 OHM 1/10W 1% 0402 SMD | R16 | RESISTOR_0402 | RESISTOR | Panasonic Electronic Components | ERJ-2RKF30R0X | 1 | Digi-Key | P30.0LCT-ND
MT9V034 | 1/3" WVGA 60FPS CMOS Digital Image Sensor Global Shutter | U1 | CLCC-48 | MT9V034_DS_D | Aptina LLC | MT9V034C12STM | 1 | Digi-Key | 557-1454-ND
eSP570 | USB 2.0 Camera Bridge Controller | U2 | LQFP-48_M | eSP570 |  |  | 1
STM8S003F3 | MCU 8BIT 8KB 16MHZ | U3 | 20-UFQFN | STM8S003F3 | STMicroelectronics | STM8S003F3U6TR | 1 | Mouser | 511-STM8S003F3U6TR
LP5900SD-3.3 | IC, LINEAR REGULATOR, 3.3V, 150MA, ULTRA LOW NOISE | U4 | LLP-6 | LP5900SD-3.3 | Texas Instruments | LP5900SD-3.3/NOPB | 1 | Digi-Key | LP5900SD-3.3/NOPBCT-ND
24LC128-I/MS | 128Kbit, 400kHz, 2.5V, I2C Serial EEPROM, 8-Pin MSOP, Industrial Temperature | U5 | MSOP-MS8_N | 24LC128-I/MS | Microchip Technology | 24LC128-I/MS | 1 | Digi-Key | 24LC128-I/MS-ND
ESDR0502N | TVS ARRAY LOW CAP 6UDFN | U6 | UDFN-6 | ESDR0502N | ON Semiconductor | ESDR0502NMUTBG | 1 | Digi-Key | ESDR0502NMUTBGOSCT-ND
12MHz | CRYSTAL 12MHZ 20PF SMD | X1 | 4-SMD | 405C35E24M00000 | CTS-Frequency Controls | 405C35E12M00000 | 1 | Digi-Key | CTX819CT-ND

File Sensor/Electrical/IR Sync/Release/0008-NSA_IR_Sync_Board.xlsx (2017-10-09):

Comment | Description | Designator | Manufacturer 1 | Manufacturer Part Number 1 | Quantity | Type | Supplier 1 | Supplier Part Number 1
LED | LED, GREEN, 0603 | D1 | Kingbright Company LLC | APT1608CGCK | 1 | smt | Digi-Key | 754-1116-1-ND
Molex 901310122 | CONN HEADER 4POS .100" STR TIN | P1 | Molex Inc | 0901310122 | 1 | thru-hole | Digi-Key | WM8120-ND
510 | RES 510 OHM 1/10W 1% 0603 SMD | R1 | Yageo | RC0603FR-07510RL | 1 | smt | Digi-Key | 311-510HRCT-ND
TSDP75T85N | IR Receiver Modules for Remote Control Systems | U1 | Vishay | TSDP75T85N | 1 | smt | Nirav | TSDP75T85N

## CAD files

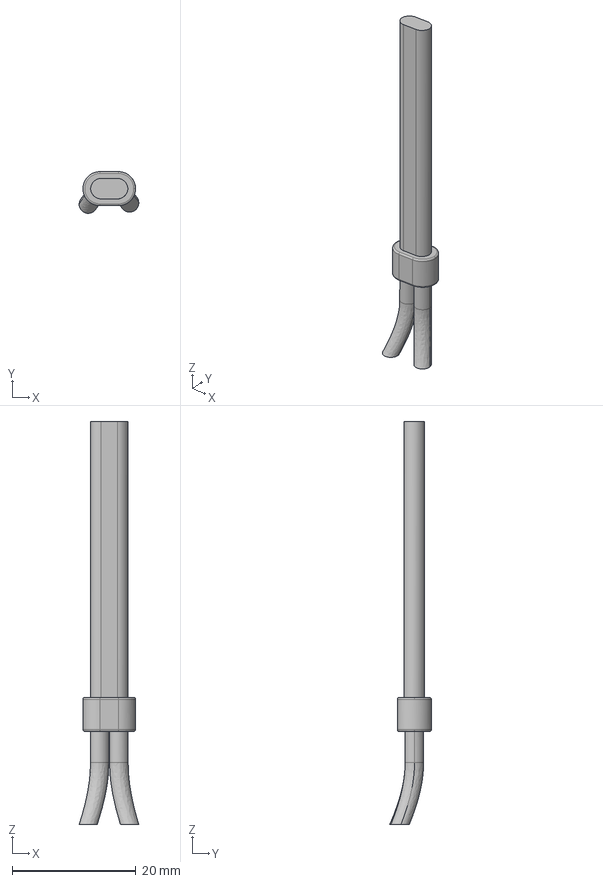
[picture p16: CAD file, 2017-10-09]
Cable/Mechanical/HMD-Side Cable Merge.stp
9.63 x 6.74 x 65.0 mm

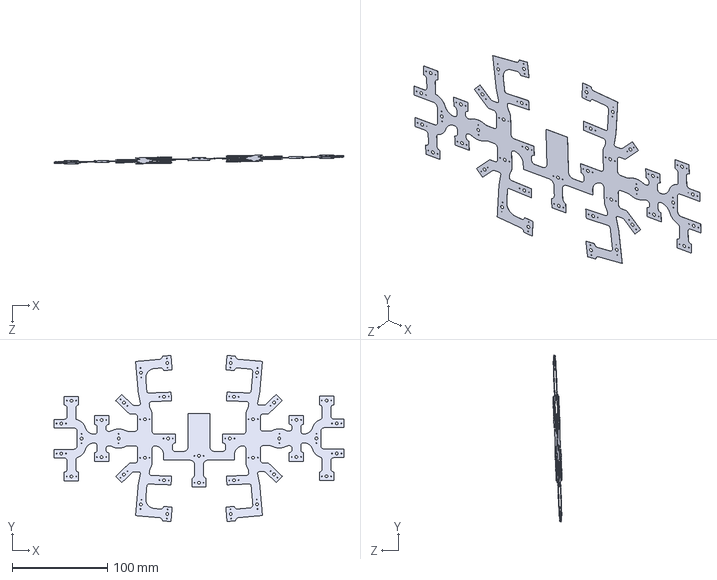
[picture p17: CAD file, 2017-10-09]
Headset/Electrical/Flex/Altium Source/Flex Mockup4.STEP
304.3 x 174.4 x 9.62 mm

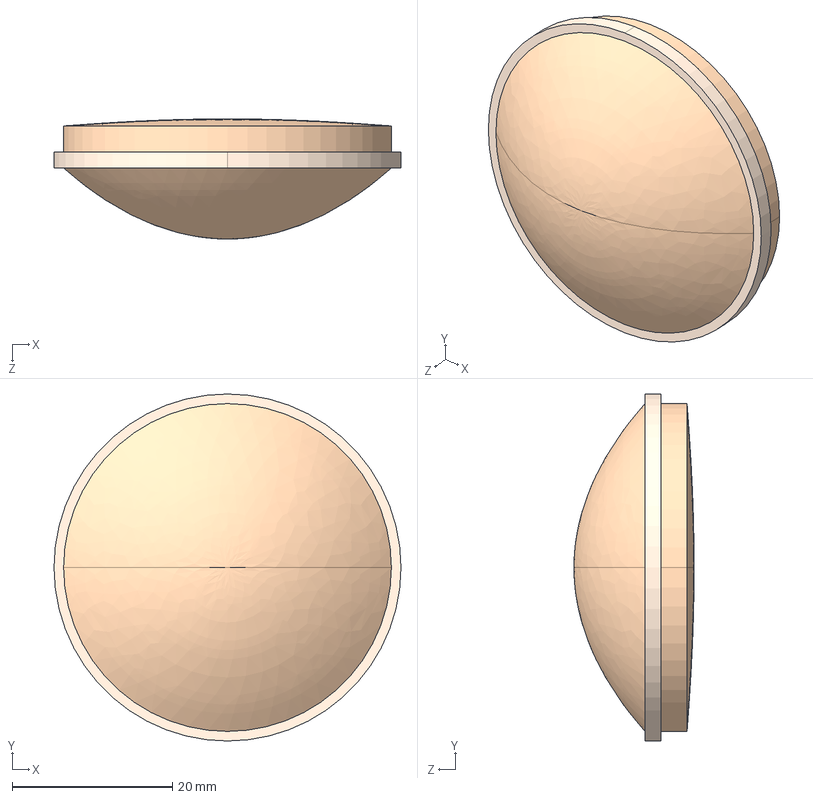
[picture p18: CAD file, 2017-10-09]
Headset/Optical/730-000005-DK2,10-100FOV_131124-130701.STEP
43.3 x 43.3 x 15.0 mm

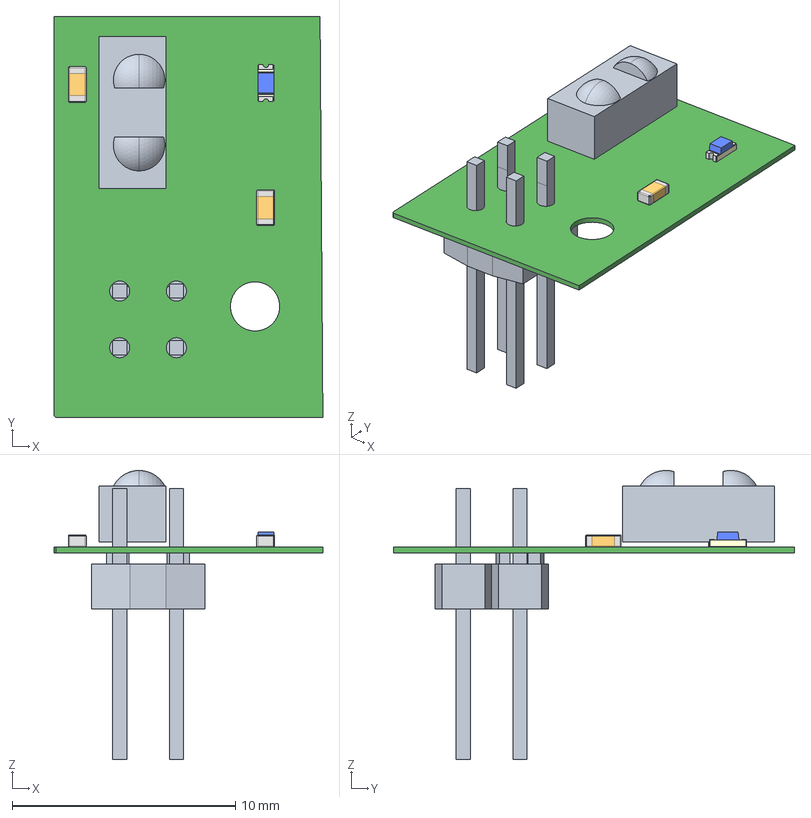
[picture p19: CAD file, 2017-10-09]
Sensor/Electrical/IR Sync/Release/0008-NSA_IR_Sync_Board.step
12.0 x 18.0 x 12.9 mm
Board
IR_Receiver_TSOP_772
LED_BLUE_0603
CAPC1608X55N_EIA_0603 x 2

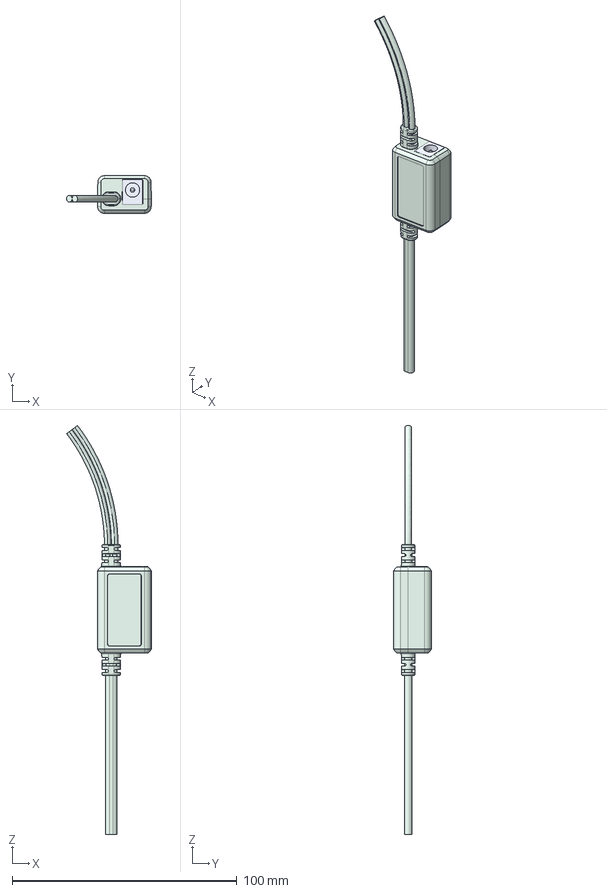
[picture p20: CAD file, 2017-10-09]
Cable/Mechanical/Confluence Module.stp
37.8 x 16.8 x 182.1 mm
Board_1465
Extruded_1639
Extruded_2_1813
RESC1005X38N_EIA_0402_2653 x 7
Extruded_3_2851 x 2
CAPC1608X55N_EIA_0603_3695
Power jack^Confluence Module_4277
2.5mm jack^Confluence Module_5087
SR ¤W»__17615
SR ¤U»__23631
Cable_29843

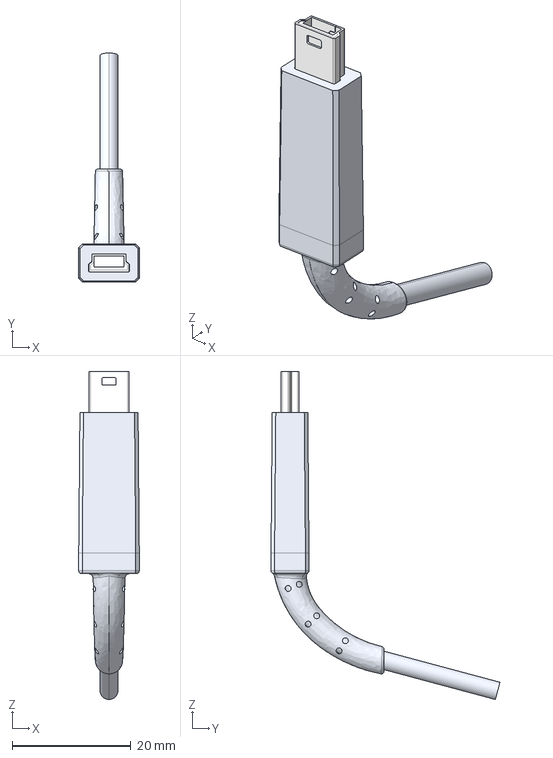
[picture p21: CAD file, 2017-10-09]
Cable/Mechanical/Mini USB 01.stp
10.2 x 38.5 x 55.2 mm

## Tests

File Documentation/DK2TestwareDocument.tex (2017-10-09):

\documentclass[letterpaper]{article}
\usepackage{bytefield}
\usepackage{mathtools}
\usepackage{ifxetex}
\ifxetex
  \usepackage{fontspec}
  \setmainfont[ExternalLocation=../Common/, 
  					  Ligatures =TeX,
					  BoldFont = Cabin-Bold.ttf,
					  ItalicFont = Cabin-Italic.ttf,
					  BoldItalicFont = Cabin-BoldItalic.ttf ]
					  {Cabin-Regular.ttf}
\fi
\usepackage{graphicx}
\usepackage{color}
\usepackage[table]{xcolor}
\usepackage{hyperref}
\usepackage{parskip}
\usepackage{tikz}
\usetikzlibrary{automata,positioning,fit}
\usepackage{fancyhdr}
\pagestyle{fancy}
\definecolor{lightgray}{gray}{0.8}
\renewcommand{\arraystretch}{1.25}

\begin{document}

\title{\huge DK2 Testware Document}
\author{Anusha Balan}
\date{Revision 0.1\\
18 August 2014}

\begin{figure}

\end{figure}

\maketitle
\thispagestyle{empty}

\lfoot{DK2 Testware Document}
\cfoot{}
\rfoot{\thepage}

\newpage

\tableofcontents

\newpage

\section{Revision History}

\begin{center}
    \begin{tabular}{ | l | l | p{8cm} |}
    \hline
    \cellcolor{lightgray} Revision & \cellcolor{lightgray} Date & \cellcolor{lightgray} Description \\ \hline
    0.1 & 18-08-2014 & Preliminary document. \\ \hline
    \end{tabular}
\end{center}

\newpage

\section{Introduction}

The Rift DK2 is interfaced using USB HID with a 1000 Hz polling rate.  The manufacturing feature report is set and checked for in the factory at different test stations using Feature Report Gets and Sets.  For more information about the various other feature reports, see the DK2 Firmware Specification document. This document details the tests available in the factory and the data saved in the manufacturing report regarding each of these tests. 

\begin{itemize}
    \item {\bfseries Vendor ID:} {\em 0x2833}
    \item {\bfseries Product ID:} {\em 0x0021}
    \item {\bfseries Vendor String:} {\em Oculus VR, Inc.}
    \item {\bfseries Product String:} {\em Rift DK2}
\end{itemize}

\newpage

\section{Manufacturing Report}

The 16 byte Manufacturing report has a ReportID of 18.  It is used to record and display the results of each stage of the production of the DK2 product that has USB access. Stage, in this document, refers to the type of test performed along the factory floor and may consist of several stations (operators) each of which handle one HMD. The manufacturing report for each stage is read by successive calls to the manufacturing report to get the report from each stage present. EG on power on, reading the manufacturing report twice will return the manufacturing report for stange 0 and 1. \\

\begin{bytefield}[leftcurly=.,bitwidth=1.1em]{32}
         \bitheader{0-31} \\
	\begin{leftwordgroup}{0}
           \bitbox{8}{ReportID = 18} & \bitbox{16}{CommandID} & \bitbox{8}{NumStages}
	\end{leftwordgroup} \\
	\begin{leftwordgroup}{4}
           \bitbox{8}{Stage} & \bitbox{8}{StageVersion} & \bitbox{16}{StageLocation}
         \end{leftwordgroup} \\
	\begin{leftwordgroup}{8}
           \bitbox{32}{StageTime}
         \end{leftwordgroup} \\
	\begin{leftwordgroup}{12}
           \bitbox{32}{Result}
         \end{leftwordgroup} \\
\end{bytefield}

\begin{itemize}
    \item {\bfseries ReportID} (8 bits): The USB Report ID for this report is 18.
    \item {\bfseries CommandID} (16 bits): A sequence number that is then repeated in the LastCommandID field of the HID IN Report.
    \item {\bfseries NumStages = 6} (8 bits)(Read only): The number of stages of production being recorded on the product. In DK2, the number of stages that are being stored are the number of active tests, utilizing USB HID interface. The number of such active tests in the current DK2 production line is 6\footnote{Reference: Berway Dongguan Factory Audit - 2014.07.09}.
    
    \item {\bfseries Stage} (8 bits): The specific stage number being recorded or read from.  This autoincrements on reads, and gets set to the written value on writes. The default before writing is 0. 
    \item {\bfseries StageVersion} (8 bits): The version of the specific manufacturing test, along with their stage numbers can be referred to from this table. The default before writing is 0. Table below also provides the cross-reference between the active test and their corresponding stage value for the 8 bits of Stage.
        \begin{center}
            \begin{tabular}{ | p{0.8cm} | p{1.4cm} | p{2.1cm} | l | p{1.7cm} | p{2.2cm} |}
            \hline
            \cellcolor{lightgray} Stage Type &  \cellcolor{lightgray} Stage   Location & \cellcolor{lightgray} Software & \cellcolor{lightgray}Version & \cellcolor{lightgray} Version Date & \cellcolor{lightgray} Description \\ \hline
            1 & F2A-6 & FrontShell LED Test & 1 & 2014-05-20 & Preliminary software. \\ \hline
            2 & F2B-1 & Shake Test & 1 & 2014-07-10 & Python GUI. \\ \hline
            3 & F2B-21 & LED Light Box & 1 & 2014-05-20 & Preliminary software. \\ \hline
            4 & F2C-3 & Magnetometer Calibration & 2 & 2014-06-30 & Software update. \\ \hline
            5 & F2C-11 & Bundle Adjustment & 2 & 2014-07-11 & Software update \\ \hline
            6 & F2C-18 & Print Station & 3 & 2014-08-11 & Updated bundle adjustment check in Printer software. \\ \hline
            \end{tabular}
        \end{center}
  
    \item {\bfseries StationLocation} (16 bits): This is a bit mask representing line, location in the line and machine this test was performed on. The line tags and the exact stage number for each of the stations is available in the "Berway Dongguan Factory Audit - 2014.07.09" document. 
        \begin{center}
            \begin{tabular}{ | p{2cm} | l | l | l | p{3.5cm} |}
            \hline
            \cellcolor{lightgray} Line Number (LNum) & \cellcolor{lightgray} Line Tag \\ \hline
            1 & F2A \\ \hline
            2 & F2B \\ \hline
            3 & F2C \\ \hline
            4 & F3A \\ \hline
            5 & F3B \\ \hline
            6 & F3C \\ \hline
            \end{tabular}
        \end{center}
  
  The 16 bits of StationLocation are divided into Line number (LNum), factory stage number (FSNum) and machine id. Each stage may have more than one station, each station being identified by the MSB of the machine ID of the machine, the test is tied to. \\
  
    \begin{center}
        \begin{bytefield}[leftcurly=.,bitwidth=1.1em]{16}
             \bitheader{0-15} \\
        \begin{leftwordgroup}{0}
               \bitbox{3}{LNum} & \bitbox{5}{FSNum} & \bitbox{8}{Machine ID MSB}
        \end{leftwordgroup} \\
        \end{bytefield}
    \end{center}
    \item {\bfseries StageTime} (32 bits): The UNIX 32 bit time at which the stage was performed.
    \item {\bfseries Result} (32 bits): The following table provides details of the error codes available in Front Shell LED Test.
    \item {\bfseries Result} (32 bits): The following table provides details of the error codes available in Shake Test.
    
        \begin{minipage}{\linewidth}
            \centering
                \begin{tabular}{ | l | p{5cm} |}
                \hline
                \cellcolor{lightgray} Error Code & \cellcolor{lightgray} Description \\ \hline
                0x0 & Default \\ \hline
                0x1 & OK \\ \hline
                0x2 & Read Error \\ \hline
                0x3 & Out of Range Error \\ \hline
                0x4 & Update Error \\ \hline
                0x5 & INReport Unpack Error \\ \hline
                0x6 & Multiple HMD Error \\ \hline
                0x7 & Disconnected Error \\ \hline
                0x8 & No Movement Error \\ \hline
                0x9 & Zero value error \\ \hline
                \end{tabular}\par
            \bigskip
            Shake Test Error Codes
            \end{minipage}

    \item {\bfseries Result} (32 bits): The following table provides details of the error codes available in LED LightBox Test.
    
        \begin{minipage}{\linewidth}
            \centering
                \begin{tabular}{ | l | p{5cm} |}
                \hline
                \cellcolor{lightgray} Error Code & \cellcolor{lightgray} Description \\ \hline
                0x0 & Default \\ \hline
                0x1 & OK \\ \hline
                0x2 & Calibration Save Error \\ \hline
                0x3 & No Camera Error \\ \hline
                0x4 & Calibration Failed \\ \hline
                \end{tabular}\par
            \bigskip
            LED Lightbox Test Error Codes
        \end{minipage}
    
    \item {\bfseries Result} (32 bits): The following table provides details of the error codes available in Magnetometer Calibration.
    
        \begin{minipage}{\linewidth}
            \centering
                \begin{tabular}{ | l | p{5cm} |}
                \hline
                \cellcolor{lightgray} Error Code & \cellcolor{lightgray} Description \\ \hline
                0x0 & Default \\ \hline
                0x1 & OK \\ \hline
                0x0 & No Data \\ \hline
                0x2 & Mag Sanity Fail \\ \hline
                0x3 & Mag Length Fail \\ \hline
                0x4 & Mag Angle Fail \\ \hline
                \end{tabular}\par
            \bigskip
            Magnetometer Calibration Test Error Codes
        \end{minipage}

    \item {\bfseries Result} (32 bits): The following error code tables provide the correlation of the error codes in Bundle Adjustment Station.
    
        \begin{minipage}{\linewidth}
            \centering
                \begin{tabular}{ | l | p{5cm} |}
                \hline
                \cellcolor{lightgray} Error Code & \cellcolor{lightgray} Description \\ \hline
                0x0 & Default \\ \hline
                0x1 & OK \\ \hline
                0x2 & Bundle Empty \\ \hline
                0x3 & Optimization Failed \\ \hline
                0x4 & Bad LED Position \\ \hline
                0x5 & Bad Camera Params \\ \hline
                \end{tabular}\par
            \bigskip
            Bundle Adjustment Station Error Codes
        \end{minipage}

    \item {\bfseries Result} (32 bits): The following error code tables provide the correlation of the error codes in Label Printer Station.
    
        \begin{minipage}{\linewidth}
            \centering
                \begin{tabular}{ | l | p{5cm} |}
                \hline
                \cellcolor{lightgray} Error Code & \cellcolor{lightgray} Description \\ \hline
                0x0 & Default \\ \hline
                0x1 & OK \\ \hline
                0x2 & BarTender Not Installed \\ \hline
                0x3 & HMD Position Calibration Error \\ \hline
                0x4 & HMD MagCalibration Error \\ \hline
                0x5 & Multiple HMD Error \\ \hline
                \end{tabular}\par
            \bigskip
            Label Printer Station Error Codes
        \end{minipage}
        
\end{itemize}

\end{document}

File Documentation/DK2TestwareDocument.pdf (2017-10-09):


# DK2 Testware Document

Anusha Balan

Revision 0.1
18 August 2014

CONTENTS | CONTENTS

## Contents

1 Revision History | 3
2 Introduction | 4
3 Manufacturing Report | 5
DK2 Testware Document | 2

1 REVISION HISTORY

## 1 Revision History

Revision | Date | Description
0.1 | 18-08-2014 | Preliminary document.
DK2 Testware Document | 3

2 INTRODUCTION

## 2 Introduction

The Rift DK2 is interfaced using USB HID with a 1000 Hz polling rate. The manufacturing feature report is set and checked for in the factory at different test stations using Feature Report Gets and Sets. For more information about the various other feature reports, see the DK2 Firmware Specification document. This document details the tests available in the factory and the data saved in the manufacturing report regarding each of these tests.

- Vendor ID: 0x2833
- Product ID: 0x0021
- Vendor String: Oculus VR, Inc.
- Product String: Rift DK2
DK2 Testware Document | 4

3 MANUFACTURING REPORT

## 3 Manufacturing Report

The 16 byte Manufacturing report has a ReportID of 18. It is used to record and display the results of each stage of the production of the DK2 product that has USB access. Stage, in this document, refers to the type of test performed along the factory floor and may consist of several stations (operators) each of which handle one HMD. The manufacturing report for each stage is read by successive calls to the manufacturing report to get the report from each stage present. EG on power on, reading the manufacturing report twice will return
the manufacturing report for stange 0 and 1.
0 | 1 | 2 | 3 | 4 | 5 | 6 | 7 | 8 | 9 | 10 11 12 13 14 15 16 17 18 19 20 21 22 23 24 25 26 27 28 29 30 31
0 | ReportID = 18 | CommandID | NumStages
4 | Stage | StageVersion | StageLocation
8 | StageTime
12 | Result
- ReportID (8 bits): The USB Report ID for this report is 18.
- CommandID (16 bits): A sequence number that is then repeated in the LastCommandID field of the HID IN Report.
- NumStages = 6 (8 bits)(Read only): The number of stages of production being recorded on the product. In DK2, the number of stages that are being stored are the number of active tests, utilizing USB HID interface. The number of such active tests in the current DK2 production line is 6¹ .
- Stage (8 bits): The specific stage number being recorded or read from. This autoincrements on reads, and gets set to the written value on writes. The default before writing is 0.
- StageVersion (8 bits): The version of the specific manufacturing test, along with their stage numbers can be referred to from this table. The default before writing is 0. Table below also provides the cross-reference between the active test and their corresponding stage value for the 8 bits of Stage.

1Reference: Berway Dongguan Factory Audit - 2014.07.09

DK2 Testware Document | 5

3 MANUFACTURING REPORT

Stage Type | Stage Location | Software | Version | Version Date | Description
1 | F2A-6 | FrontShell LED Test | 1 | 2014-05-20 | Preliminary software.
2 | F2B-1 | Shake Test | 1 | 2014-07-10 | Python GUI.
3 | F2B-21 | LED Light Box | 1 | 2014-05-20 | Preliminary software.
4 | F2C-3 | Magnetometer Calibration | 2 | 2014-06-30 | Software update.
5 | F2C-11 | Bundle Ad-justment | 2 | 2014-07-11 | Software update
6 | F2C-18 | Print Station | 3 | 2014-08-11 | Updated bundle adjust-ment check in Printer software.
- StationLocation (16 bits): This is a bit mask representing line, location in the line and machine this test was performed on. The line tags and the exact stage number for each of the stations is available in the ”Berway Dongguan Factory Audit - 2014.07.09” document.
Line Number (LNum) | Line Tag
1 | F2A
2 | F2B
3 | F2C
4 | F3A
5 | F3B
6 | F3C

The 16 bits of StationLocation are divided into Line number (LNum), factory stage number (FSNum) and machine id. Each stage may have more than one station, each station being identified by the MSB of the machine ID of the machine, the test is tied to.

0 | 1 | 2 | 3 | 4 | 5 | 6 | 7 | 8 | 9 | 10 11 12 13 14 15
0 | LNum | FSNum | Machine ID MSB
- StageTime (32 bits): The UNIX 32 bit time at which the stage was performed.
DK2 Testware Document | 6

3 MANUFACTURING REPORT

- Result (32 bits): The following table provides details of the error codes available in Front Shell LED Test.
- Result (32 bits): The following table provides details of the error codes available in Shake Test.
Error Code | Description
0x0 | Default
0x1 | OK
0x2 | Read Error
0x3 | Out of Range Error
0x4 | Update Error
0x5 | INReport Unpack Error
0x6 | Multiple HMD Error
0x7 | Disconnected Error
0x8 | No Movement Error
0x9 | Zero value error

Shake Test Error Codes
- Result (32 bits): The following table provides details of the error codes available in LED LightBox Test.
Error Code | Description
0x0 | Default
0x1 | OK
0x2 | Calibration Save Error
0x3 | No Camera Error
0x4 | Calibration Failed

LED Lightbox Test Error Codes

- Result (32 bits): The following table provides details of the error codes available in Magnetometer Calibration.
DK2 Testware Document | 7

3 MANUFACTURING REPORT

Error Code | Description
0x0 | Default
0x1 | OK
0x0 | No Data
0x2 | Mag Sanity Fail
0x3 | Mag Length Fail
0x4 | Mag Angle Fail

Magnetometer Calibration Test Error Codes

- Result (32 bits): The following error code tables provide the correlation of the error codes in Bundle Adjustment Station.
Error Code | Description
0x0 | Default
0x1 | OK
0x2 | Bundle Empty
0x3 | Optimization Failed
0x4 | Bad LED Position
0x5 | Bad Camera Params

Bundle Adjustment Station Error Codes

- Result (32 bits): The following error code tables provide the correlation of the error codes in Label Printer Station.
Error Code | Description
0x0 | Default
0x1 | OK
0x2 | BarTender Not Installed
0x3 | HMD Position Calibration Error
0x4 | HMD MagCalibration Error
0x5 | Multiple HMD Error

Label Printer Station Error Codes

DK2 Testware Document | 8

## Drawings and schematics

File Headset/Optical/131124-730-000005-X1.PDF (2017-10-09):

D
D

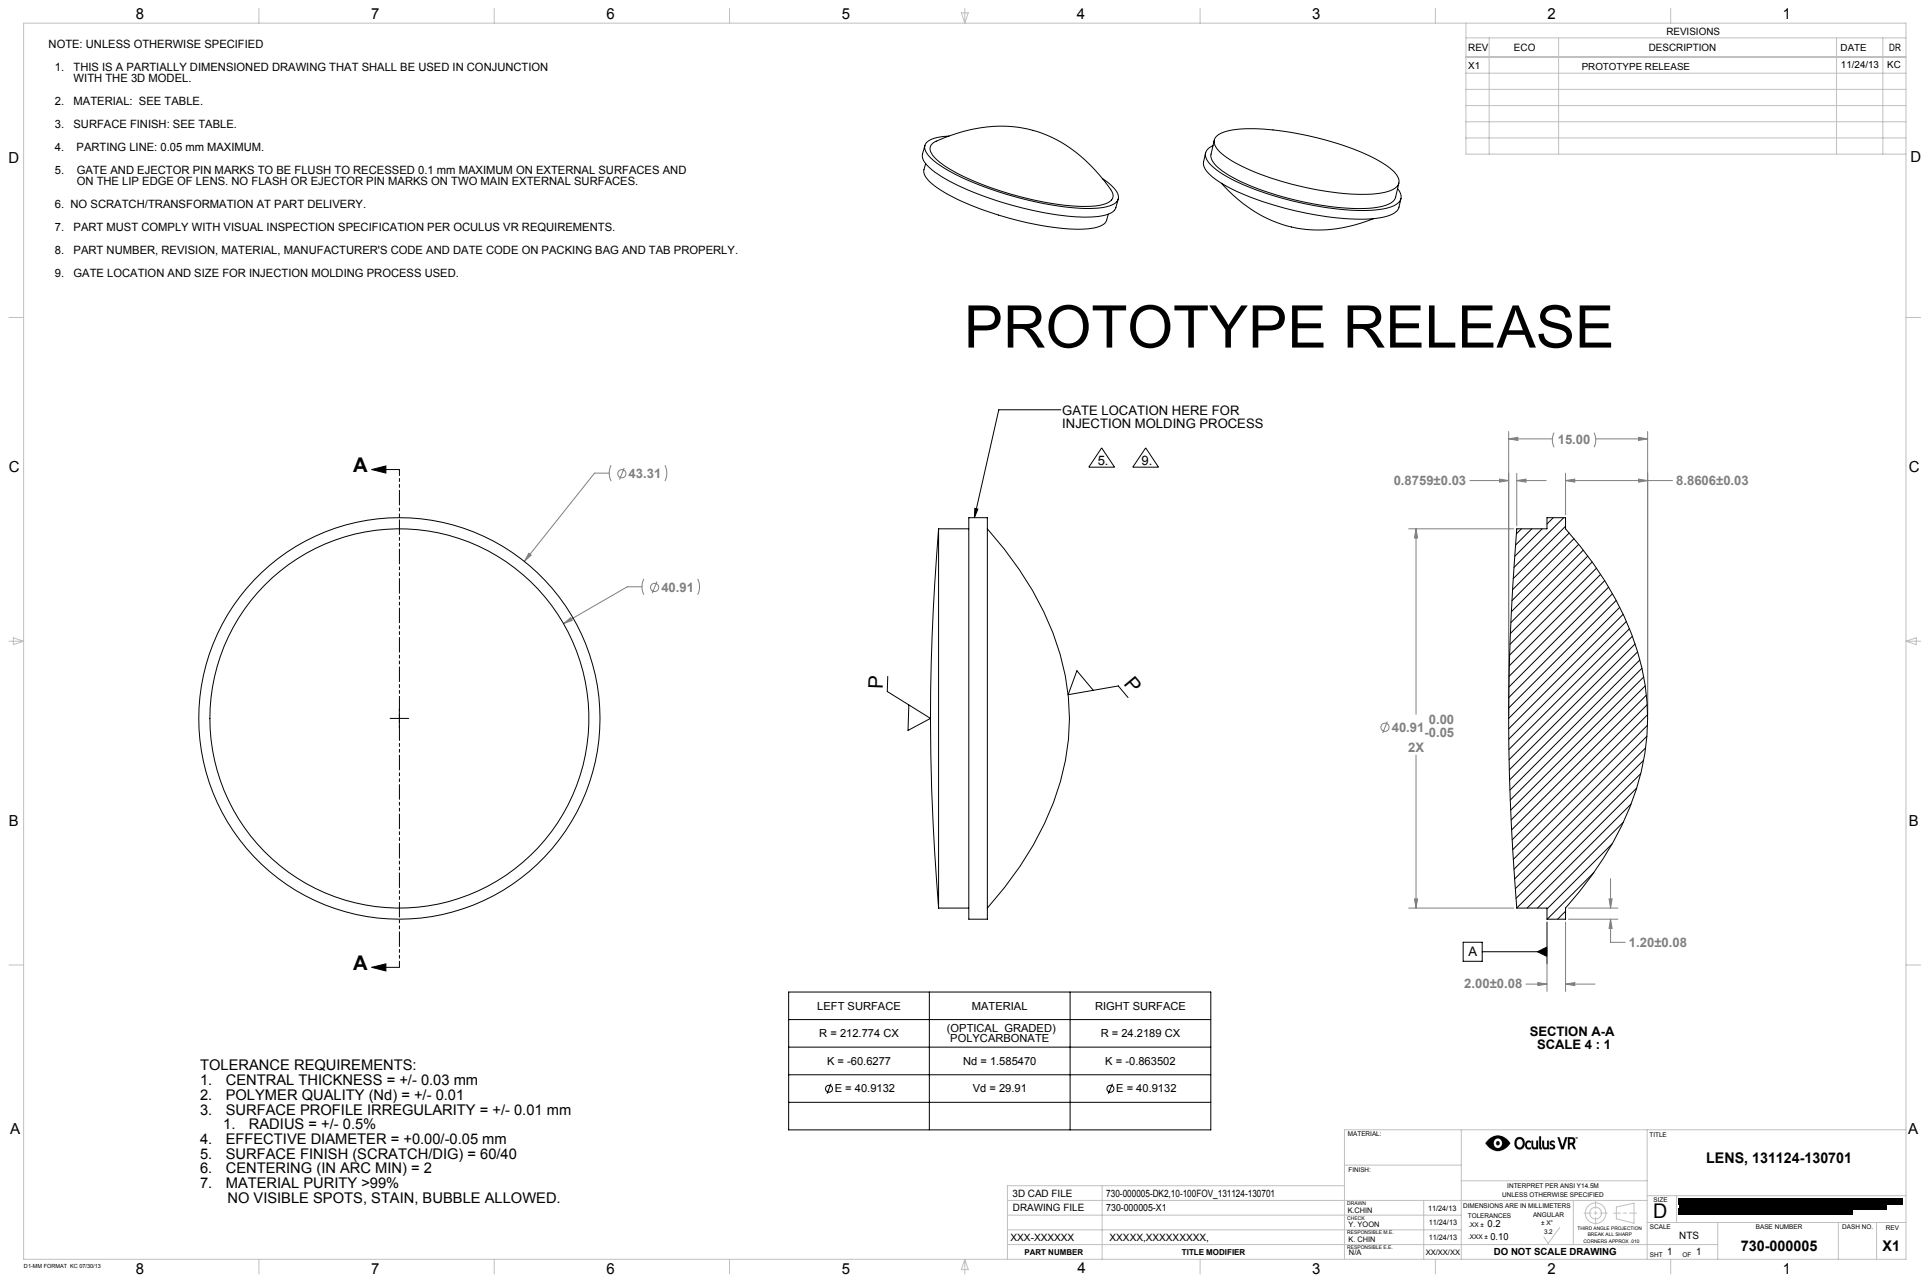
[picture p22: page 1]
SECTION A-A SCALE 4 : 1; SCALE; BASE NUMBER; DASH NO.; REV; SHT; TITLE; MATERIAL:; DRAWN; CHECK; RESPONSIBLE M.E.; RESPONSIBLE E.E.; FINISH:; ANGULAR ± X°; PART NUMBER; ECO; DESCRIPTION; REVISIONS; TITLE MODIFIER; NTS 1; K.CHIN; K. CHIN N/A; XXX-XXXXXX; XXXXX,XXXXXXXXX,; SIZE; 3D CAD FILE; 730-000005-DK2,10-100FOV_131124-130701; DRAWING FILE; DATE; LENS, 131124-130701; Y. YOON; PROTOTYPE RELEASE

NOTE: UNLESS OTHERWISE SPECIFIED
1. THIS IS A PARTIALLY DIMENSIONED DRAWING THAT SHALL BE USED IN CONJUNCTION
WITH THE 3D MODEL.
2. MATERIAL: SEE TABLE.
3. SURFACE FINISH: SEE TABLE.
4. PARTING LINE: 0.05 mm MAXIMUM.
5. GATE AND EJECTOR PIN MARKS TO BE FLUSH TO RECESSED 0.1 mm MAXIMUM ON EXTERNAL SURFACES AND
ON THE LIP EDGE OF LENS. NO FLASH OR EJECTOR PIN MARKS ON TWO MAIN EXTERNAL SURFACES.
6. NO SCRATCH/TRANSFORMATION AT PART DELIVERY.
7. PART MUST COMPLY WITH VISUAL INSPECTION SPECIFICATION PER OCULUS VR REQUIREMENTS.
8. PART NUMBER, REVISION, MATERIAL, MANUFACTURER'S CODE AND DATE CODE ON PACKING BAG AND TAB PROPERLY.
9. GATE LOCATION AND SIZE FOR INJECTION MOLDING PROCESS USED.

GATE LOCATION HERE FOR
INJECTION MOLDING PROCESS

LEFT SURFACE | MATERIAL | RIGHT SURFACE
R = 212.774 CX | (OPTICAL GRADED) POLYCARBONATE | R = 24.2189 CX

TOLERANCE REQUIREMENTS:
1. CENTRAL THICKNESS = +/- 0.03 mm
2. POLYMER QUALITY (Nd) = +/- 0.01
3. SURFACE PROFILE IRREGULARITY = +/- 0.01 mm
1. RADIUS = +/- 0.5%
4. EFFECTIVE DIAMETER = +0.00/-0.05 mm
5. SURFACE FINISH (SCRATCH/DIG) = 60/40
6. CENTERING (IN ARC MIN) = 2
7. MATERIAL PURITY >99%
NO VISIBLE SPOTS, STAIN, BUBBLE ALLOWED.

K = -60.6277 | Nd = 1.585470 | K = -0.863502
E = 40.9132 | Vd = 29.91 | E = 40.9132

INTERPRET PER ANSI Y14.5M
UNLESS OTHERWISE SPECIFIED

DIMENSIONS ARE IN MILLIMETERS
TOLERANCES
.XXX ±
DO NOT SCALE DRAWING

THIRD ANGLE PROJECTION
BREAK ALL SHARP
CORNERS APPROX .010

D1-MM FORMAT KC 07/30/13

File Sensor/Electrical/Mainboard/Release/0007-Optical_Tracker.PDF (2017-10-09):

# 10K SRST_B

# CLK_27PCLK

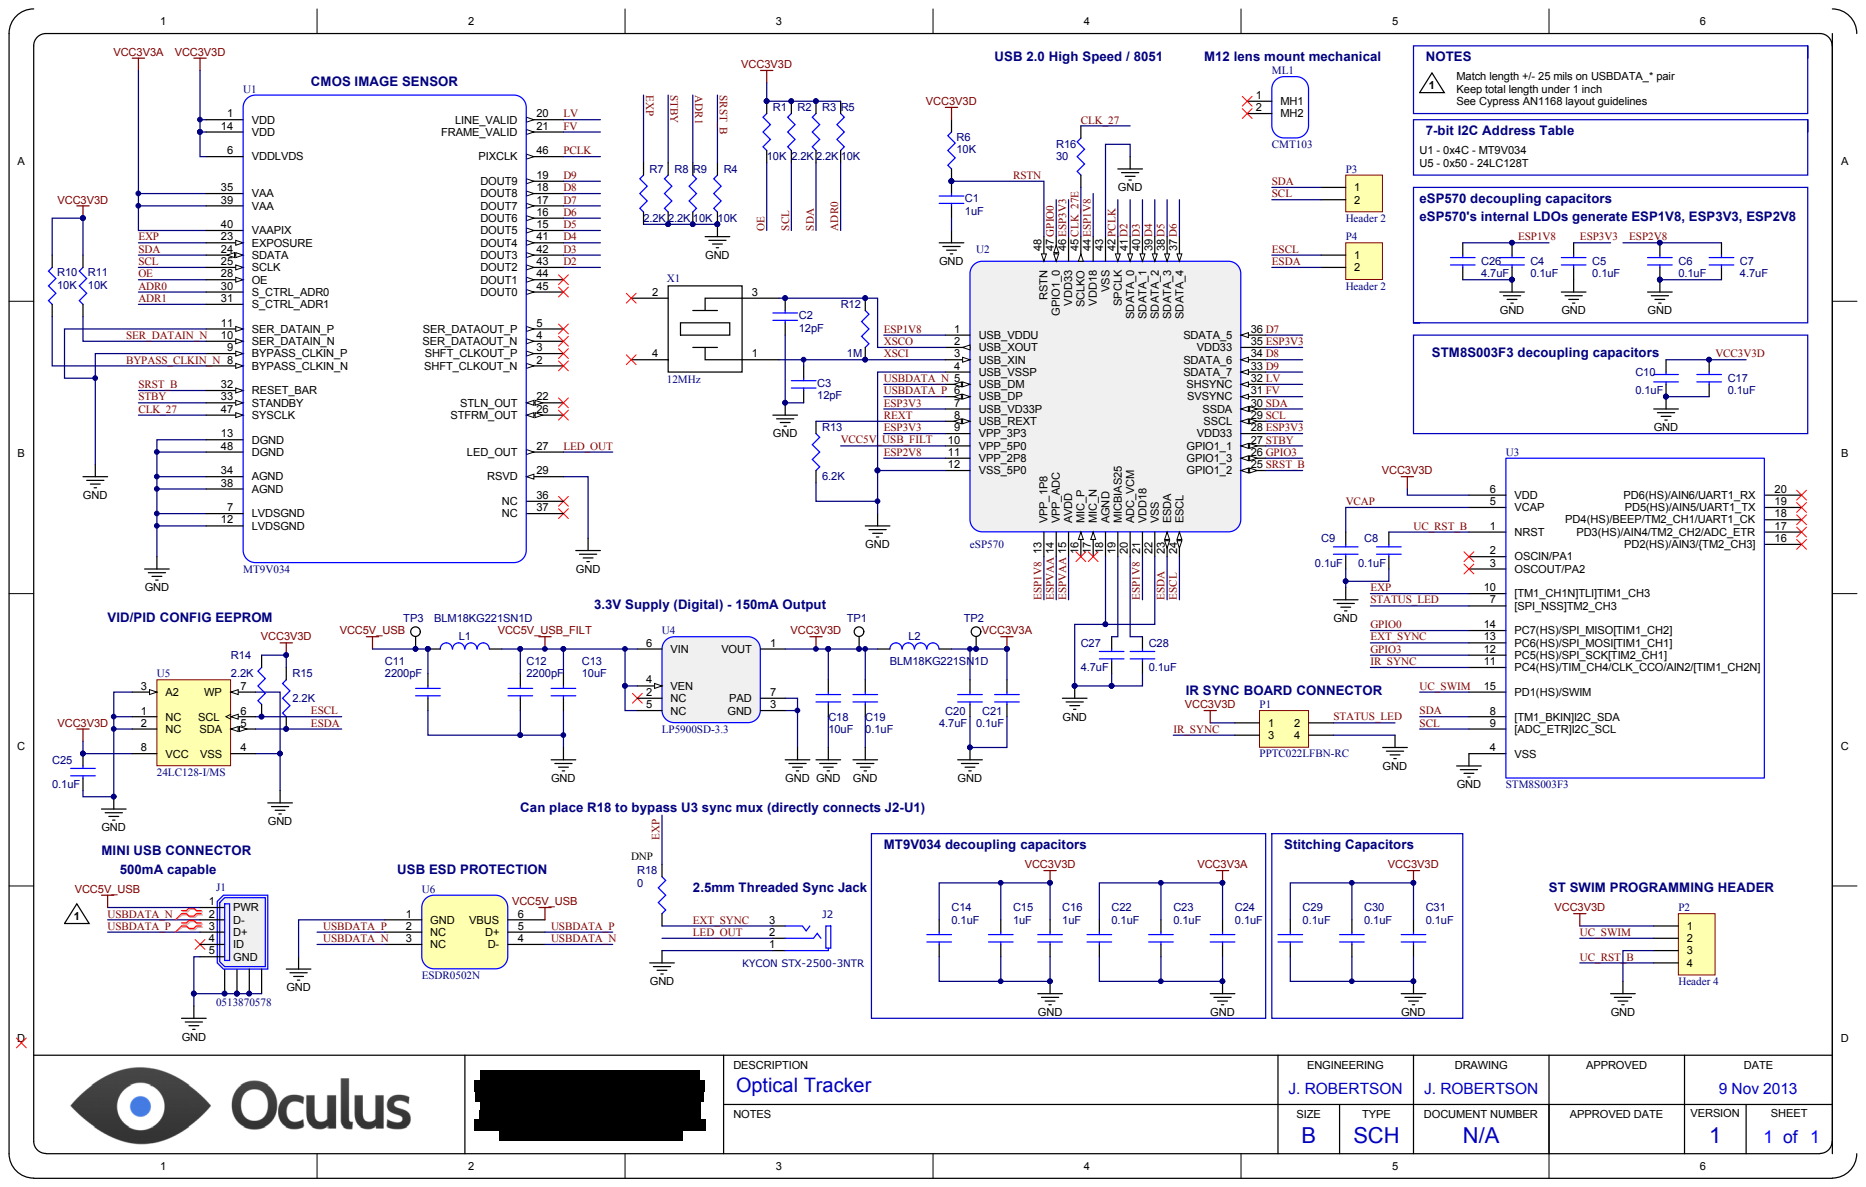
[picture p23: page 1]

Match length +/- 25 mils on USBDATA_* pair
Keep total length under 1 inch
See Cypress AN1168 layout guidelines

ESCL 24 GPIO1_2 25 GPIO1_3 26 GPIO1_1 27 VDD33 28 SSCL 29 SSDA 30 SVSYNC 31 SHSYNC 32 SDATA_7 33 SDATA_6 34 VDD33 35 SDATA_5 36 SDATA_4 37 SDATA_3 38 SDATA_2 39 SDATA_1 40 SDATA_0 41 SPCLK 42 VSS 43 VDD18 44 SCLKO 45 VDD33 46 GPIO1_0 47 RSTN

VID/PID CONFIG EEPROM

IR SYNC BOARD CONNECTOR
VCC3V3D

Can place R18 to bypass U3 sync mux (directly connects J2-U1)

ST SWIM PROGRAMMING HEADER

DESCRIPTION Optical Tracker | ENGINEERING J. ROBERTSON | DRAWING J. ROBERTSON | APPROVED | DATE 9 Nov 2013

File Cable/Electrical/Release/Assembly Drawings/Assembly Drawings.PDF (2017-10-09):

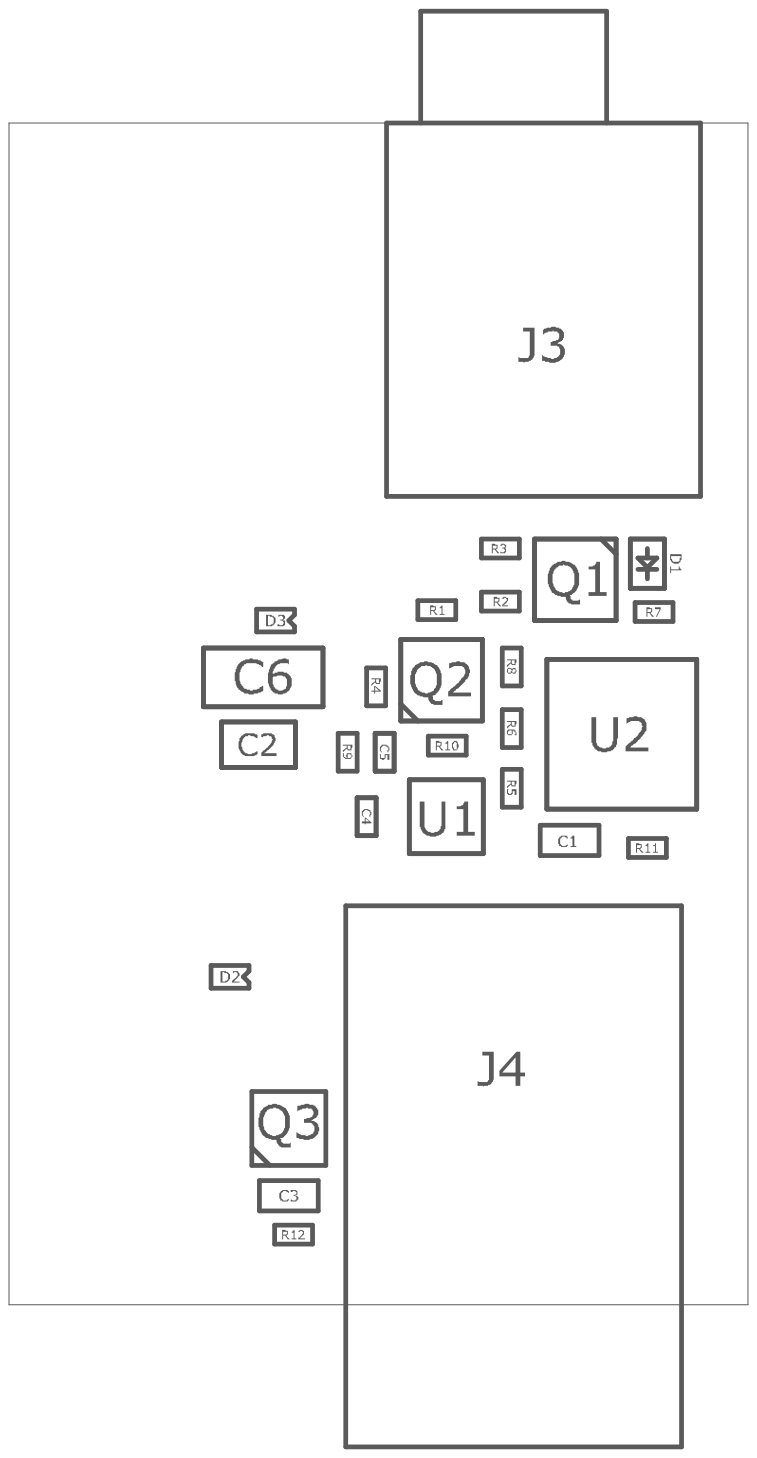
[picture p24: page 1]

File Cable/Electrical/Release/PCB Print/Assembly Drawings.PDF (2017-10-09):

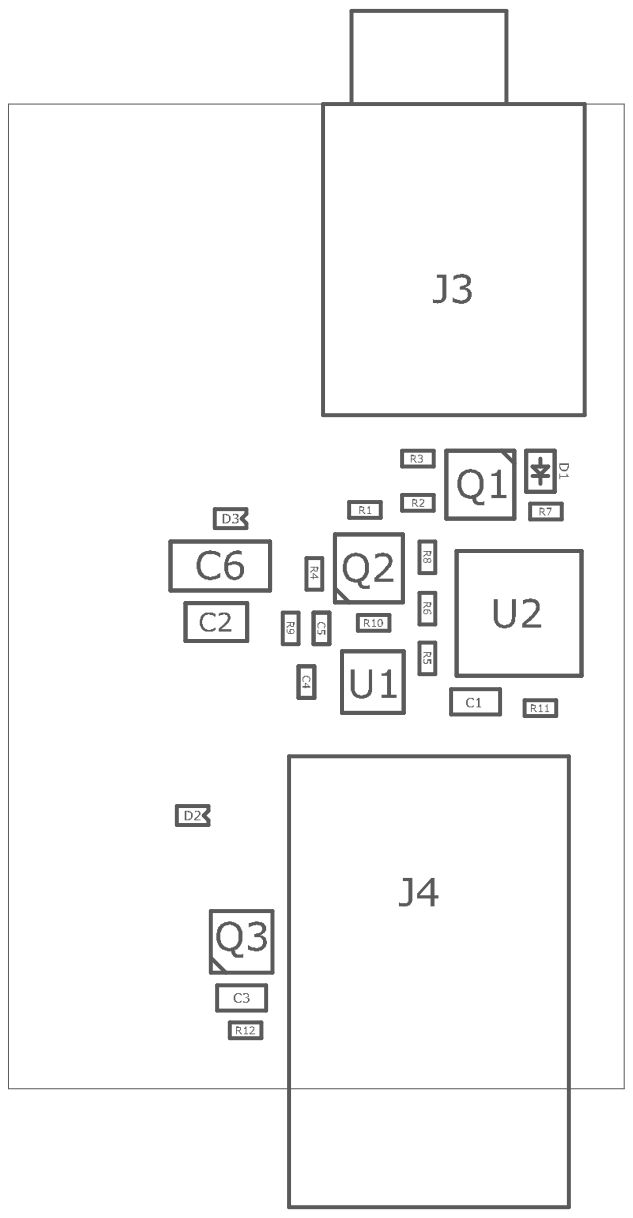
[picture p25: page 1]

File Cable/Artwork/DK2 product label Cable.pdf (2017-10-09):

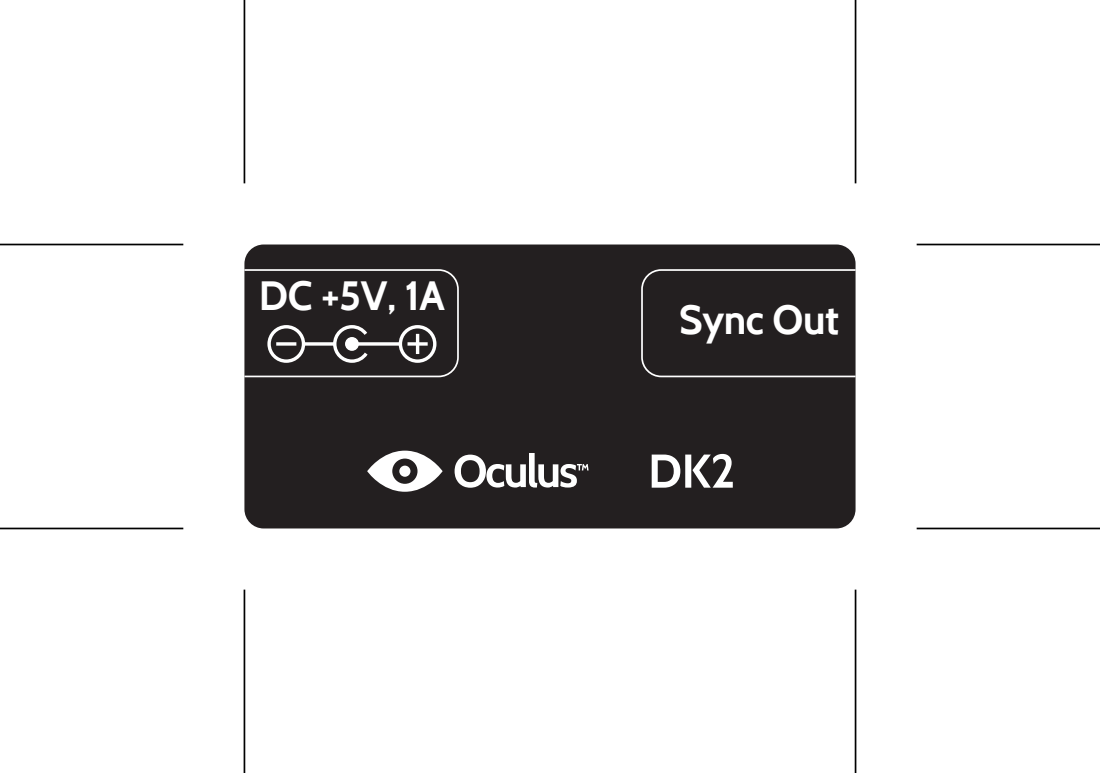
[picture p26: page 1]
Sync Out

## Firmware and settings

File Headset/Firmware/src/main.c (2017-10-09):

/************************************************************************************

Filename    :   main.c
Content     :   Main loop and supporting functions for the main board.
Created     :
Authors     :   Nirav Patel, Lyle Bainbridge

Copyright   :   Copyright (c) 2013-present, Facebook, Inc.
                All rights reserved.

This source code is licensed under the BSD-style license found in the
LICENSE file in the root directory of this source tree. An additional grant 
of patent rights can be found in the PATENTS file in the same directory.

*************************************************************************************/

#include "hw_config.h"
#include <stdint.h>
#include <stdio.h>
#include <string.h>
#include <stm32l1xx.h>
#include "stm32l.h"
#include "delay.h"
#include "gpio.h"
#include "leds.h"
#include "hub.h"
#include "h2c.h"
#include "panel.h"
#include "debug.h"
#include "systick.h"
#include "button.h"
#include "uuid.h"
#include "sequence.h"
#include "timestamper.h"
#include "in_report.h"
#include "feature_report.h"
#include "usb.h"
#include "lis3mdl.h"
#include "mpu6500.h"
#include "vsync.h"
#include "autocalibrate.h"
#include "calibrate.h"
#include "factory.h"
#include "bootloader_state.h"
#include "config.h"
#include "blocking.h"

volatile bool v_lock_changed = 0;
static feature_config_t g_config = {0};
static feature_keep_alive_t g_keep_alive = {0};

static void brownout_setup(void)
{
    uint8_t bor = FLASH_OB_GetBOR();
    // Check if we have brownout reset at 1.94V, set it otherwise
    if (bor != OB_BOR_LEVEL2) {
        FLASH_OB_Unlock();
        FLASH_OB_BORConfig(OB_BOR_LEVEL2);
        FLASH_OB_Launch();
        FLASH_OB_Lock();
    }
}

static void power_on(void)
{
    // Start with the Amber LED on
    led_amber_on();
    hub_accessory_led_update(0);
    
    // Unsleep the sensors
    lis3mdl_sleep(0);
    mpu6500_sleep(0);

    sequence_init();
    
    panel_reset_state();
    h2c_power_on();
    h2c_config();

    // Initialize the MIPI Master
    panel_timing_t initial_timing;
    panel_current_timing(&initial_timing);
    h2c_mipi_init(&initial_timing);

    // Go into video mode, though the HDMI PHY will remain inactive until HPD
    h2c_video_mode();
}

static void power_off(void)
{
    led_amber_off();
    led_blue_off();
    hub_accessory_led_update(1);

    // Power off the various peripherals before powering off
    panel_enable(0);
    panel_power_off();
    h2c_power_off();
    mpu6500_sleep(1);
    lis3mdl_sleep(1);
    sequence_deinit();
    in_report_reset();
}

static void perform_reset(void)
{
    power_off();
    
    // Reset
    NVIC_SystemReset();
}

static void use_pll(bool use_pll)
{
    if (use_pll) {
        // Switch back to using the PLL
        RCC_SYSCLKConfig(RCC_SYSCLKSource_PLLCLK);
        while (RCC_GetSYSCLKSource() != 0x0C);
        
        // Reset the systick and button again
        systick_init();
        button_init();
    } else {
        // Switch to directly running on HSE to drop current consumption
        // by a few milliamps
        RCC_SYSCLKConfig(RCC_SYSCLKSource_HSE);
        while (RCC_GetSYSCLKSource() != 0x08);
        
        // Reset the systick to get the right millisecond tick
        systick_init();
        // Reset the button, since it depends on systick count
        button_init();
    }
}

static void off_loop(bool off_reason_usb)
{
    // Power everything off
    power_off();
    
    bool using_pll = 1;
    
    while (1) {
        // If USB is suspended, we need to get under 12.5 mA, which requires
        // shutting off more 
        if (usb_suspended() && using_pll) {
            use_pll(0);
            using_pll = 0;
        } else if (!usb_suspended() && !using_pll) {
            use_pll(1);
            using_pll = 1;
        }
        
        // Keep the CPU asleep while waiting for something to happen
        __WFI();
        
        // Check if the button has been pressed or we're getting woken from USB
        // and the reason we went to sleep was USB suspend
        if ((button_update() && button_state()) || (off_reason_usb && usb_ready())) {
            // Go back to full clock speed to use USB
            if (!using_pll) {
                use_pll(1);
                using_pll = 1;
            }
            
            // Bring USB back and attempt to wake up the PC
            if (!usb_ready()) {
                // If resume isn't allowed, remain in Suspend
                if (!usb_resume()) {
                    continue;
                }
            }
            
            // Only wake up everything if USB successfully came back on
            if (usb_ready()) {
                power_on();
                break;
            }
        }
    }
}

static bool handle_button(void)
{
    if (button_update() && button_state()) {
        // Wait for the button to be let go
        while (button_state()) {
            button_update();
        }
        
        return 1;
    }
    
    return 0;
}

static void handle_feature_report(void)
{
    feature_config_t config;
    feature_range_t range;
    feature_register_t reg;
    feature_dfu_t dfu;
    sequence_t sequence;
    panel_t panel;
    sequence_pattern_t pattern;
    
    if (feature_report_get_config(&config)) {
        if (config.override_power != g_config.override_power) {
            // Only set the config if it changed
            uint8_t overrides = config.override_power;
            config_write(&overrides, CFG_SIZE_OVERRIDES, CFG_ADDR_OVERRIDES);
        }
        
        // Use the new configuration
        memcpy(&g_config, &config, sizeof(feature_config_t));
        
        // Reset the IN Report, since the coordinate system may have changed
        // TODO: should this also reset the magnetometer fields?
        in_report_reset();        
    }
    
    if (feature_report_get_range(&range)) {
        mpu6500_set_ranges(range.accel_range, range.gyro_range);
        lis3mdl_set_range(range.mag_range);
    }
    
    if (feature_report_get_register(&reg)) {
        switch (reg.device) {
            case FEATURE_REGISTER_MPU6500:
                // dump partially stored packets only when gyro registers change
                in_report_reset();
                mpu6500_set_register(reg.reg, reg.payload);
                break;

            case FEATURE_REGISTER_LIS3MDL:
                lis3mdl_set_register(reg.reg, reg.payload);
                break;

            default:
                break;
        }
    }
    
    if (feature_report_get_dfu(&dfu)) {
        if (dfu.use_dfu) {
            bootloader_state_set(BOOTLOAD_MANUAL);
            perform_reset();
        }
    }
    
    if (feature_report_get_keep_alive(&g_keep_alive)) {
        // Update the in report configuration to switch between DK1 and DK2
        in_report_update_id(g_keep_alive.in_report);
    }
    
    if (feature_report_get_tracking(&sequence)) {
        sequence_set_state(&sequence);
    }
    
    if (feature_report_get_display(&panel)) {
        panel_set_state(&panel);
    }
    
    if (feature_report_get_pattern(&pattern)) {
        sequence_set_custom_pattern(&pattern);
    }
    
    in_report_update_command_id(feature_report_latest_command_id());
}

void blocking_update(uint32_t wait_us)
{
    uint32_t start = timestamper_get_time();
    
    mpu6500_data_t mpu = {0};
    exposure_t exposure = {0};
    
    // This is ugly, but we have a bunch of blocking waits that shouldn't
    // prevent inertial samples from being transmitted.  Note that to reduce
    // the scope of conflicts, only gyro/accel and LED sequence information
    // is updated
    while (!timestamper_is_after(start + wait_us)) {
        // Update the gyro/accelerometer part of the in report if there is a new sample
        if (mpu6500_read(&mpu, g_config.use_raw)) {
            // Don't store autocalibration if the samples are raw, to avoid bad table items
            autocalibrate_update(&mpu, g_config.autocalibration, !g_config.use_raw);
            
            if (g_config.use_calibration)
                calibrate_apply(&mpu);
            
            in_report_update_mpu(&mpu);
        }
        
        // Update the tracking part of the in report if there was a new exposure
        if (sequence_get_exposure(&exposure)) {
            in_report_update_tracking(&exposure);
        }
        
        if (!g_config.command_keep_alive || ((systick_get_tick_count() - feature_report_latest_command_time()) < g_keep_alive.keep_alive)) {
            if (in_report_ready(g_config.interval)) {
                in_report_send();
            }
        }
    }
}

int main(void)
{
    // stm32l_init happens from the reset handler
    brownout_setup();
    systick_init();
    timestamper_init();
    config_init();
    uuid_init();
    leds_init();
    
    // Initialize the HID Reports
    feature_report_init_config(&g_config);
    feature_report_init_keep_alive(&g_keep_alive);
    in_report_update_id(g_keep_alive.in_report);
    
    sequence_init();
    debug_init();
    button_init();
    lis3mdl_init();
    mpu6500_init();
    calibrate_init();
    h2c_init();
    panel_init();

    // Wait until the modules are initialized before bringing up USB    
    hub_init(g_config.override_power);
    usb_init();
    bool factory_calibrating = factory_check_enable();
    
    // Spit out the build date/time/compiler version for board debugging
    // over the serial interface if we aren't in the calibration cube
    if (!factory_calibrating) {
        printf("%s %s %u\r\n", __DATE__, __TIME__, __VER__);
    }
    
    // Wait for USB to be present before doing anything unless we're in factory mode
    while (!factory_calibrating && !usb_ready());
    // As a workaround for #145, check wall wart presence again after USB
    // is ready
    hub_check_ww();
    // Take the i2c bus back from the hub after USB is ready
    hub_post_init();
    
    // DK2 shares a bus for the hub and config i2c, so reinit config
    config_init();
    
    // TODO: Don't allow feature report reads until after config is reinited
    
    // Turn on the bridge, panel, and sensors
    power_on();
    
    lis3mdl_data_t mag = {0};
    mpu6500_data_t mpu = {0};
    exposure_t exposure = {0};
    vsync_t vsync = {0};
    uint32_t last_feature_report = 0;
    bool reset_sync = 0;
    bool keep_alive_active = 0;
    
    while (1) {
        // Keep the CPU asleep while waiting for something to happen
//        __WFI();
        
        // Get the current time for housekeeping use
        uint32_t now = systick_get_tick_count();

        // Handle any incoming feature reports
        uint32_t latest_report = feature_report_count();
        if (last_feature_report != latest_report) {
            handle_feature_report();
            last_feature_report = latest_report;
        }
        
        // Use the button for power on/off
        if (handle_button()) {
            off_loop(0);
        }
                
        // Handle powering down due to USB suspend, only if we aren't in
        // a test fixture where USB should not be present
        if (!factory_calibrating && usb_suspended()) {
            // We get stuck in a suspend loop on boards before Rev3.3
#ifdef DK2_REV3_3
            off_loop(1);
#endif /* DK2_REV3_3 */
        }
        
        // Handle getting or losing HDMI Rx
        if (v_lock_changed) {
            v_lock_changed = 0;
            h2c_hdmi_v_clear();
            // Reset the calculated refresh rate if we get or lose sync
            vsync_reset_average();
            reset_sync = 1;
            if (h2c_hdmi_v_status()) {
                // Only take action if the panel was powered off
                if (!panel_enabled()) {
                    // If the resolution changed, we need to reconfigure
                    // the HDMI receiver for the panel to work
                    uint16_t h_active = h2c_h_active();
                    uint16_t v_active = h2c_v_active();
                    if (panel_resolution_changed(h_active, v_active)) {
                        panel_timing_t timing;
                        // We don't have the actual refresh rate yet, so
                        // get the default
                        panel_get_timing(0, &timing);
                        // Find a timing that matches the new resolution
                        uint8_t index = panel_get_closest_timing(timing.refresh, h_active, v_active);
                        // Get the timing and set it to the HDMI bridge
                        panel_get_timing(index, &timing);
                        h2c_mipi_init(&timing);
                    }
                    
                    // Don't power on panel until HDMI is present
                    panel_power_on();
                    
                    // Repeat the panel enable until it succeeds, since it may
                    // fail if TMDS briefly disappears
                    while (h2c_hdmi_v_status()) {
                        // Switch from Amber to Blue when the screen goes active
                        led_blue_on();
                        led_amber_off();
                    
                        if (panel_enable(1)) {
                            break;
                        } else {
                            // If a MIPI command fails, the H2C and/or panel are
                            // in an bad and unknown state, so we need to
                            // reset the TMDS PHY, the MIPI block (this happens
                            // in the h2c_mipi_write), and the panel
                            h2c_hdmi_phy_suspend(1);
                            panel_enable(0);
                            h2c_mipi_set_tx(0);
                            h2c_hdmi_phy_suspend(0);
                            
                            led_blue_off();
                            led_amber_on();
                            
                            blocking_update(120000);          
                        }
                    }
                    
                    h2c_mipi_set_tx(1);
                }
            } else {
                // Sending MIPI commands while the HDMI PHY is active but there
                // is no input TMDS signal puts the H2C in a state where
                // all MIPI commands fail.  Powering down the HDMI PHY
                // before sending the panel off commands appears to function
                // as a workaround.
                h2c_hdmi_phy_suspend(1);
                panel_enable(0);
                panel_power_off();
                h2c_mipi_set_tx(0);
                // Turn the phy back to auto-on on cable detect to be prepared
                // for the HDMI signal coming back
                h2c_hdmi_phy_suspend(0);
                
                // Switch from Blue to Amber when the screen goes to sleep
                led_blue_off();
                led_amber_on();
            }
        }
        
        // Handle factory calibration commands
        if (factory_calibrating) {
            int command = getchar();
            if (command != EOF) {
                factory_set_command(command);
            }
        }
        
        // Update the gyro/accelerometer part of the in report if there is a new sample
        if (mpu6500_read(&mpu, g_config.use_raw)) {
            if (factory_calibrating) {
                // Update the factory calibrate state machine if we are in the calibration fixture
                factory_update(&mpu);
            } else {
                // Don't store autocalibration if the samples are raw, to avoid bad table items
                autocalibrate_update(&mpu, g_config.autocalibration, !g_config.use_raw);
            }
            if (g_config.use_calibration)
                calibrate_apply(&mpu);
            
            in_report_update_mpu(&mpu);
        }
        
        // Update the magnetometer part of the in report if there is a new sample
        if (lis3mdl_read(&mag, g_config.use_raw)) {            
            in_report_update_mag(&mag);
        }
        
        // Update the tracking part of the in report if there was a new exposure
        if (sequence_get_exposure(&exposure)) {
            in_report_update_tracking(&exposure);
        }
        
        // Update the display part of the in report if there was a new frame
        if (panel_get_vsync(&vsync)) {
            in_report_update_display(&vsync);
        }
        
        // Handle the refresh rate changing
        if (reset_sync) {
            uint16_t refresh = panel_get_refresh();
            if (refresh && panel_enabled()) {
                uint16_t h_active = h2c_h_active();
                uint16_t v_active = h2c_v_active();
                panel_update_timing(refresh, h_active, v_active);
                reset_sync = 0;
                
                // Set the right values on the bridge
                // when the timings change
                // TODO: this potentially also effects other stuff like
                // camera sync when tied to vsync and scaling settings
                panel_timing_t new_timing;
                panel_current_timing(&new_timing);
                h2c_mipi_init(&new_timing);
            }
        }
        
        if (!g_config.command_keep_alive || ((now - feature_report_latest_command_time()) < g_keep_alive.keep_alive)) {
            keep_alive_active = 1;
            sequence_set_timeout(0);
        } else if (keep_alive_active) {
            keep_alive_active = 0;
            // Power off the LED system if we timed out of keep alive to avoid
            // leaving the LEDs and camera running
            sequence_set_timeout(1);
        }
        
        // Only send a new in report if the previous one sent, there is new
        // data, and we are either not using keep alive or we are within
        // the keep alive interval.
        // TODO: Also support motion keep alive?
        if (in_report_ready(g_config.interval) && keep_alive_active) {
            in_report_send();
        }
    }
}

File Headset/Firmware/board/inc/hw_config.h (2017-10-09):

/************************************************************************************

Filename    :   hw_config.h
Content     :   Hardware configuration for the main board.
Created     :
Authors     :   Lyle Bainbridge

Copyright   :   Copyright (c) 2013-present, Facebook, Inc.
                All rights reserved.

This source code is licensed under the BSD-style license found in the
LICENSE file in the root directory of this source tree. An additional grant 
of patent rights can be found in the PATENTS file in the same directory.

*************************************************************************************/

#ifndef _HW_CONFIG_H_
#define _HW_CONFIG_H_

// 12 KB is reserved for the bootloader, and the application firmware 
// starts immediately after
#define APPLICATION_OFFSET (0x4000)
#define APPLICATION_ADDRESS (0x08000000 + APPLICATION_OFFSET)
#define PWM_FREQ PANEL_PWM
#define BL_SCALER (32 - 1)
#define BL_PERIOD(pwm) (((8000000 / BL_SCALER) / pwm))

/******************************************************************************/
#ifdef DK2_REV3
/******************************************************************************/

#define MAG_DRDY_PORT           GPIOC
#define MAG_DRDY_PIN            GPIO_Pin_5
#define MAG_DRDY_SOURCE_PORT    EXTI_PortSourceGPIOC
#define MAG_DRDY_SOURCE         EXTI_PinSource5
#define MAG_DRDY_LINE           EXTI_Line5
#define MAG_DRDY_CHANNEL        EXTI9_5_IRQn

#define MAG_CS_PORT             GPIOC
#define MAG_CS_PIN              GPIO_Pin_6

#define GYRO_FSYNC_PORT         GPIOA
#define GYRO_FSYNC_PIN          GPIO_Pin_4

#define GYRO_CS_PORT            GPIOB
#define GYRO_CS_PIN             GPIO_Pin_12

#define GYRO_IRQ_PORT           GPIOA
#define GYRO_IRQ_PIN            GPIO_Pin_2
#define GYRO_IRQ_SOURCE         GPIO_PinSource2
#define GYRO_IRQ_CHANNEL        TIM_Channel_3
#define GYRO_IRQ_FLAG           TIM_IT_CC3
#define GYRO_IRQ_TIM            TIM2
#define GYRO_IRQ_IRQ            TIM2_IRQn
#define GYRO_IRQ_AF             GPIO_AF_TIM2

#define MEMS_SPI_NUM            SPI2
#define MEMS_SPI_RCC            RCC_APB1Periph_SPI2
#define MEMS_SPI_AF             GPIO_AF_SPI2
#define MEMS_SPI_DMA_TX         DMA1_Channel5
#define MEMS_SPI_DMA_RX         DMA1_Channel4
#define MEMS_SPI_DMA_RCC        RCC_AHBPeriph_DMA1
#define MEMS_SPI_DMA_TX_FLAG    (DMA1_FLAG_TE5 | DMA1_FLAG_TC5)
#define MEMS_SPI_DMA_RX_FLAG    (DMA1_FLAG_TE4 | DMA1_FLAG_TC4)
#define MEMS_SPI_CONFIG_SPEED   SPI_BaudRatePrescaler_32
#define MEMS_SPI_READ_SPEED     SPI_BaudRatePrescaler_4
#define MEMS_PORT               GPIOB
#define MEMS_SCK_PIN            GPIO_Pin_13
#define MEMS_SCK_SOURCE         GPIO_PinSource13
#define MEMS_MISO_PIN           GPIO_Pin_14
#define MEMS_MISO_SOURCE        GPIO_PinSource14
#define MEMS_MOSI_PIN           GPIO_Pin_15
#define MEMS_MOSI_SOURCE        GPIO_PinSource15

#define MCO_PORT                GPIOA
#define MCO_PIN                 GPIO_Pin_8

#define USB_DM_PORT             GPIOA
#define USB_DM_PIN              GPIO_Pin_11

#define USB_DP_PORT             GPIOA
#define USB_DP_PIN              GPIO_Pin_12

#define ACC_PWR_EN_PORT         GPIOB
#define ACC_PWR_EN_PIN          GPIO_Pin_5

#define ACC_PWR_FAULT_PORT      GPIOC
#define ACC_PWR_FAULT_PIN       GPIO_Pin_10
#define ACC_PWR_FAULT_IRQ_SOURCE_PORT   EXTI_PortSourceGPIOC
#define ACC_PWR_FAULT_IRQ_SOURCE        EXTI_PinSource10
#define ACC_PWR_FAULT_IRQ_LINE          EXTI_Line10

#define GPIO0_PORT              GPIOC
#define GPIO0_PIN               GPIO_Pin_7
#define GPIO0_IRQ_SOURCE_PORT   EXTI_PortSourceGPIOC
#define GPIO0_IRQ_SOURCE        EXTI_PinSource7
#define GPIO0_IRQ_LINE          EXTI_Line7

#define CAM_SYNC_IN_PORT              GPIO0_PORT
#define CAM_SYNC_IN_PIN               GPIO0_PIN
#define CAM_SYNC_IN_IRQ_SOURCE_PORT   GPIO0_IRQ_SOURCE_PORT
#define CAM_SYNC_IN_IRQ_SOURCE        GPIO0_IRQ_SOURCE
#define CAM_SYNC_IN_IRQ_LINE          GPIO0_IRQ_LINE

#define GPIO1_PORT              GPIOC
#define GPIO1_PIN               GPIO_Pin_8

// Use GPIO1 since there isn't a dedicated pin
#define CAL_EN_PORT             GPIO1_PORT
#define CAL_EN_PIN              GPIO1_PIN

#define PANEL_PWM_TIM           TIM2
#define PANEL_PWM_TIM_RCC       RCC_APB1Periph_TIM2
#define PANEL_PWM_PORT          GPIOB
#define PANEL_PWM_PIN           GPIO_Pin_3
#define PANEL_PWM_SOURCE        GPIO_PinSource3
#define PANEL_PWM_AF            GPIO_AF_TIM2

#define PANEL_RESET_PORT        GPIOC
#define PANEL_RESET_PIN         GPIO_Pin_3

#define PANEL_MIPI_ERR_PORT     GPIOA
#define PANEL_MIPI_ERR_PIN      GPIO_Pin_0

#define PANEL_VSYNC_PORT        GPIOA
#define PANEL_VSYNC_PIN         GPIO_Pin_1
#define PANEL_VSYNC_SOURCE      GPIO_PinSource1
#define PANEL_VSYNC_CHANNEL     TIM_Channel_2
#define PANEL_VSYNC_FLAG        TIM_IT_CC2
#define PANEL_VSYNC_TIM         TIM2
#define PANEL_VSYNC_IRQ         TIM2_IRQn
#define PANEL_VSYNC_AF          GPIO_AF_TIM2
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
